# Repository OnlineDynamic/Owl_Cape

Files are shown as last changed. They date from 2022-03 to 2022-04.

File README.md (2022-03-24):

# Owl_Cape
Raspberry Pi (SMI Driven) FPP WS2811 based ch16 Pixel Controller Cape

Building on the great work of the Falcon FPP project, numerous open hardware pixel controllers and the clever brain behind this blog: https://iosoft.blog/2020/09/29/raspberry-pi-multi-channel-ws2812/

This project is looking to create a simple low cost 16ch Raspberry PI Cape to run on FPP using SMI interface of a 'Raspberry Pi Zero 2 W' (and potentially then expand out to supporting other Pi's with the 40PIN Header).  The aspiration is for the final code for the cape to be included in the FPP project and the xLights project to make a low cost easy to use pixel controller for LED pixel light shows which will benefit as the FPP project evolves its functionality.

## Basic Spec of Cape

- 12V DC in only (fused at xx Amps)
- PI Mounts on PCB
- 40 Pin Header for attaching to RPI via a ribbon cable (allow easy removal of PI)
- Power the RPI via Header pins
- 16 Ch of LED (WS2811) outputs individually fused at 5A running at 12V DC with SMD LED power indicators
- EEPROM onboard to identify CAPE to PI

## Potential Future expansion
- On board RJ45 Jack to connect wired ethernet to PI using USB test pads on PI
- Jumper to make LED voltage either 12V or 5V DC
- Basic LED Screen showing status

## Out of scope
- Any differential outputs

## Special Thanks to:
https://github.com/Kosh42/PCB-Designs/tree/main/Mirage for the inspiration

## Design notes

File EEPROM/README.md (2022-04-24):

# HOWTO: Raspi HAT EEPROM and device-tree setup

Customised from https://forums.raspberrypi.com/viewtopic.php?t=108134

## Intro

As it is hard to find good quality information EEPROM for HATs, and after some struggling I have found the post above but it too had issues and seemed out of date, so I decided to write this file to create a set of instructions for myself to use with the 'Owl Cape' project but have tried to leave in lots of description to help others more generically. 

In this project I'm using a Amtel AT24C256 (32,768 x 8 bits (256k bits or 32kB)) (https://ww1.microchip.com/downloads/en/DeviceDoc/doc0670.pdf) to meet FPP[^5]. spec but typically the standard Pi hat spec talks about using its smaller brother the AT24C32 (4,096 x 8)

This process should work for:
- 24c32
- 24c64
- 24c128
- 24c256
- 24c512
- 24c1024

(with the correct adjustments in file size generation and type command passed to eepflash)

## Initial Setup

First off, let’s talk about the hardware. I used an AT24C256 DIP i2c EEPROM. 

The pins need to be wired like this:

| AT24C256 Pin |	Raspberry Pi Pin 	  | Notes |
|---|---|---|
|1 (AO) 	 |GND (pins 6, 9, 14, 20, 25, 30, 34, 39)| 	All address pins tied to ground will place the EEPROM at address 50. This is the required address in the specification|
|2 (A1) |GND | | 	
|3 NC |Not Connected|| 	
|4 GND 	|GND 	||
|5 SDA | 	27 You should also add a 3.9K pullup resistor from EEPROM pin 5 to 3.3V | You must use this pin for the Raspberry Pi to detect the EEPROM on startup |
|6 SCL | 	28 You should also add a 3.9K pullup resistor from EEPROM pin 6 to 3.3V | You must use this pin for the Raspberry Pi to detect the EEPROM on startup |
|7 WP 	|Not connected 	| Write protect. The write protect input, when connected to GND, allows normal write operations. When WP is connected high to V CC , all write operations to the memory are inhib-ited. If the pin is left floating, the WP pin will be internally pulled down to GND.|
|8 VCC 	| 3.3V (pins 1 or 17) |	The EEPROM is capable of being run at 5 volts, but must be run at 3.3 volts to work as a HAT identification EEPROM.|

The specification requires that the data pin be on pin 27, the clock pin be on pin 28, and that the EEPROM be at address 50 on the i2c bus as described in the table above. There is also some mention of pullup resistors in both the data sheet and the HAT specification, but not in a lot of detail. The best I could find was a circuit diagram for a different EEPROM with the pullup resistors shown.

## Setup Raspberry PI

As a preliminary step, you need to activate videocore I2C. This is done by adding a line at the beginning of your /boot/config.txt file :

Add:

Code: 
```
dtparam=i2c_vc=on
```

Then reboot.

First of all, you need to get EEPROM utils (to make EEPROM content and flash it) and device-tree compiler (dtc).
For the device tree, the original author followed advice from Adafruit : https://learn.adafruit.com/introduction-to-the-beaglebone-black-device-tree/compiling-an-overlay

Code: 
```bash
git clone https://github.com/raspberrypi/hats.git
wget -c https://raw.githubusercontent.com/RobertCNelson/tools/master/pkgs/dtc.sh
chmod +x dtc.sh
./dtc.sh
```

You'll have now installed dtc compiler and have a hats directory. Go inside, and open eepromutils directory.

Code:
```bash
cd hats/eepromutils
```

Then need to run the make command to get the eepmake programme work:

Code:
```bash
make && sudo make install
```

Install I2C tools (used for detecting EEPROM)

Code:
```bash
sudo apt install i2c-tools
```

## Create Custom EEPROM Content

First of all, you need to modify eeprom_settings.txt to create your own version of HAT board. You don't have to modify UUID, as it will be auto-generated.

Template Code: (Owl_Cape version in git folder) 

```
########################################################################
# EEPROM settings text file
#
# Edit this file for your particular board and run through eepmake tool,
# then use eepflash tool to write to attached HAT ID EEPROM 
#
# Tools available:
#  eepmake   Parses EEPROM text file and creates binary .eep file
#  eepdump   Dumps a binary .eep file as human readable text (for debug)
#  eepflash  Write or read .eep binary image to/from HAT EEPROM
#
########################################################################

########################################################################
# Vendor info

# 128 bit UUID. If left at zero eepmake tool will auto-generate
# RFC 4122 compliant UUID
product_uuid 00000000-0000-0000-0000-000000000000

# 16 bit product id
product_id 0x0001

# 16 bit product version
product_ver 0x0002

# ASCII vendor string  (max 255 characters)
vendor "Martinlbb"

# ASCII product string (max 255 characters)
product "Brilliant board"

########################################################################
# GPIO bank settings, set to nonzero to change from the default.
# NOTE these setting can only be set per BANK, uncommenting any of
# these will force the bank to use the custom setting.

# drive strength, 0=default, 1-8=2,4,6,8,10,12,14,16mA, 9-15=reserved
gpio_drive 0

# 0=default, 1=slew rate limiting, 2=no slew limiting, 3=reserved
gpio_slew 0

# 0=default, 1=hysteresis disabled, 2=hysteresis enabled, 3=reserved
gpio_hysteresis 0

# If board back-powers Pi via 5V GPIO header pins:
# 0 = board does not back-power
# 1 = board back-powers and can supply the Pi with a minimum of 1.3A
# 2 = board back-powers and can supply the Pi with a minimum of 2A
# 3 = reserved
# If back_power=2 then USB high current mode will be automatically 
# enabled on the Pi
back_power 0

########################################################################
# GPIO pins, uncomment for GPIOs used on board
# Options for FUNCTION: INPUT, OUTPUT, ALT0-ALT5
# Options for PULL: DEFAULT, UP, DOWN, NONE
# NB GPIO0 and GPIO1 are reserved for ID EEPROM so cannot be set

#         GPIO  FUNCTION  PULL
#         ----  --------  ----
#setgpio  2     INPUT     DEFAULT
#setgpio  3     INPUT     DEFAULT
#setgpio  4     INPUT     DEFAULT
#setgpio  5     INPUT     DEFAULT
#setgpio  6     INPUT     DEFAULT
#setgpio  7     INPUT     DEFAULT
#setgpio  8     INPUT     DEFAULT
#setgpio  9     INPUT     DEFAULT
#setgpio  10    INPUT     DEFAULT
#setgpio  11    INPUT     DEFAULT
#setgpio  12    INPUT     DEFAULT
#setgpio  13    INPUT     DEFAULT
#setgpio  14    INPUT     DEFAULT
#setgpio  15    INPUT     DEFAULT
#setgpio  16    INPUT     DEFAULT
#setgpio  17    INTPUT     DEFAULT
setgpio  18    OUTPUT     DEFAULT
#setgpio  19    INPUT     DEFAULT
#setgpio  20    INPUT     DEFAULT
#setgpio  21    INPUT     DEFAULT
#setgpio  22    INPUT     DEFAULT
#setgpio  23    INPUT     DEFAULT
#setgpio  24    INPUT     DEFAULT
#setgpio  25    INPUT     DEFAULT
#setgpio  26    INPUT     DEFAULT
#setgpio  27    INPUT     DEFAULT
```

Then, you can create an eep file, based on you eeprom_settings.txt file. Basically, an eep file is a binary version of this file, which is ready to flash on EEPROM.

Code:
```bash
./eepmake eeprom_settings.txt myhat.eep
```
You have now a working HAT file!

## Writting file to EEPROM

You can now write it on EEPROM. If you have followed my design, you have a 24c256 memory (32k) if you have pi standard hat spec you have 24c32 memory (4k). But your myhat.eep file is smaller. As you don't know the state of your EEPROM, you may have conflict, as your myhat.eep could be misread. To avoid that, we shall start by cleaning EEPROM.

Use this dd command to generate a 32k file, padded with zero (an excellent choice, zeros are my favorites!). If you have another EEPROM size, just change count value according to your real EEPROM size.

Code: 

```bash
dd if=/dev/zero ibs=1k count=32 of=blank.eep
```

To be sure, you can review this binary, using hexdump :

Code:
```bash
hexdump blank.eep
```

## Make sure you can talk to the EEPROM

    In the HAT specification, the HAT EEPROM is connected to pins that can be driven by I2C0. However, this is the same interface as used by the camera and displays, so use of it by the ARMs is discouraged. The eepflash.sh script gets around this problem by instantiating a software driven I2C interface using those pins as GPIOs, calling it i2c-9:

Code:
```bash
   sudo dtoverlay i2c-gpio i2c_gpio_sda=0 i2c_gpio_scl=1 bus=9
```

Install i2cdetect Code:
```bash
   sudo apt install i2c-tools
```
    
Check with i2cdetect -y 9 (should be at address 0x50)

Code:
```bash
   i2cdetect -y 9 0x50 0x50
```

   Result:
   ```
       0  1  2  3  4  5  6  7  8  9  a  b  c  d  e  f
   00: 
   10:
   20:
   30:
   40:
   50: 50
   60: 
   70:
```

Next, you can now upload it to your EEPROM :

Code:
```bash
sudo ./eepflash.sh -w -d=9 -f=blank.eep -t=24c256
```

Answer yes, and before hitting enter, do a ground connection to test point (see design guide recommendation), who remove read-only flag. Then, press enter and wait without moving this ground connection!

To verify if everything went well, you can use this command to check EEPROM content. Caution: it will only work after you use the eepflash command, which does some modprobes.

Code: 
```bash
sudo hexdump /sys/class/i2c-adapter/i2c-9/0-0050/eeprom
```

If everything is okay, you'll only see zeros.

Then, you can upload your own myhat.eep.

Code:
```bash
sudo ./eepflash -w -d=9 -f=myhat.eep -t=24c256
```

And again, verify it after uploading :

Code:
```bash
sudo hexdump /sys/class/i2c-adapter/i2c-9/0-0050/eeprom
```

If the contents match, you can reboot your Raspberry Pi.

## Checking it worked and PI recognises HAT

To check if your HAT is recognized, just go to /proc/device-tree/. If you see a hat directory, you are a winner:)

Code:
```bash
cd /proc/device-tree/hat/
more vendor
more product
```

## Setting up Auto Configuration

The next step is to allow autoconfiguration of this HAT, following device-tree usage. In our example, we have a led connected to GPIO 18 (pin 12). I suggest you to test it before, using /sys/class/gpio :

Code:
```bash
sudo sh -c 'echo "18" > /sys/class/gpio/export'
sudo sh -c 'echo "out" > /sys/class/gpio/gpio18/direction'
sudo sh -c 'echo "1" > /sys/class/gpio/gpio18/value'
```

Your led is powered on. And to power off :

Code:
```bash
sudo sh -c 'echo "0" > /sys/class/gpio/gpio18/value'
```

Don't forget to get back to your hat/eepromutils directory after !

Now we can dive in the device-tree world. Open a file, called myled.dts, and paste this code (heavily copied from fividi post viewtopic.php?f=29&t=97875):

Code:
```
/dts-v1/;
/plugin/;

/ {
    compatible = "brcm,bcm2708";

    fragment@0 {
        target = <&leds>;
        __overlay__ {
            my_led: myled {
                label = "MYLED";
                gpios = <&gpio 18 0>;
                linux,default-trigger = "heartbeat";
            };
        };
    };
};
```
Compile it with dtc compiler :

Code:
```bash
sudo dtc -@ -I dts -O dtb -o myled.dtb myled.dts ; sudo chown pi:pi myled.dtb
```
For testing purposes, you can load this dtb as an overlay, using dtoverlay= in /boot/config.txt. This is not the purpose of this post, I let you search it on this forum.

Now, we can generate a eep file containing both board definition (eeprom_config.txt) and device-tree (for kernel auto configuration).

Code: 
```bash
./eepmake eeprom_settings.txt myhat-with-dt.eep myled.dtb
```

Then, blank the eeprom and upload it (don't forget to ground the test point to disabled read-only mode):

Code:
```bash
sudo ./eepflash.sh -w -f=blank.eep -t=24c256
sudo ./eepflash.sh -w -f=myhat-with-dt.eep -t=24c256
```

And finally, consistency checking by viewing both original file and eeprom dump :

Code:
```bash
hexdump myhat-with-dt.eep
sudo hexdump /sys/class/i2c-adapter/i2c-9/0-0050/eeprom
```
Finally, do a reboot, and enjoy your LED, blinking like a heartbeat!

Final reminder: When you start playing with adding long device tree, keep in mind you have a limited memory (4096 bytes for a 24c32 memory). When creating an eep file with eepmake, this tool will give you final size of your eep. Just verifiy if you have exceed your EEPROM size.

Note: With an incorrect DT, even your eeprom_settings are not recognized by kernel. And a bootable device-tree overlay is sometimes not sufficient for "eeprom boot"

To allow auto configuration after kernel boot (ie: modprobe some modules, TFT calibration, etc...), I use a custom parameter file, based on JSON, that could be parsed after. I choose JSON as it is small, human-readable, and easy to parse.
To add a custom file to your eep, just do this:

Code:
```bash
./eepmake eeprom_settings.txt myhat-with-dt.eep myled.dtb -c myparams.json
```

## Footnotes of reference sites used

[^1]: Official Guide https://github.com/raspberrypi/hats/tree/master/eepromutils.
[^2]: Helpful blog https://www.madebymikal.com/raspberry-pi-hat-identity-eeproms-a-simple-guide/.
[^3]: AT24C256 Spec https://datasheetspdf.com/pdf-file/160492/ATMELCorporation/AT24C256/1.
[^4]: Raspberry Pi Pinout https://pinout.xyz/pinout/sdio#.
[^5]: FPP (Falcon Pi Player) https://github.com/FalconChristmas/fpp.

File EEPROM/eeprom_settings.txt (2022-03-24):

########################################################################
# EEPROM settings text file
#
# Edit this file for your particular board and run through eepmake tool,
# then use eepflash tool to write to attached HAT ID EEPROM 
#
# Tools available:
#  eepmake   Parses EEPROM text file and creates binary .eep file
#  eepdump   Dumps a binary .eep file as human readable text (for debug)
#  eepflash  Write or read .eep binary image to/from HAT EEPROM
#
########################################################################

########################################################################
# Vendor info

# 128 bit UUID. If left at zero eepmake tool will auto-generate
# RFC 4122 compliant UUID
product_uuid 00000000-0000-0000-0000-000000000000

# 16 bit product id
product_id 0x0001

# 16 bit product version
product_ver 0x0002

# ASCII vendor string  (max 255 characters)
vendor "OnlineDynamic"

# ASCII product string (max 255 characters)
product "Owl Cape"

########################################################################
# GPIO bank settings, set to nonzero to change from the default.
# NOTE these setting can only be set per BANK, uncommenting any of
# these will force the bank to use the custom setting.

# drive strength, 0=default, 1-8=2,4,6,8,10,12,14,16mA, 9-15=reserved
gpio_drive 0

# 0=default, 1=slew rate limiting, 2=no slew limiting, 3=reserved
gpio_slew 0

# 0=default, 1=hysteresis disabled, 2=hysteresis enabled, 3=reserved
gpio_hysteresis 0

# If board back-powers Pi via 5V GPIO header pins:
# 0 = board does not back-power
# 1 = board back-powers and can supply the Pi with a minimum of 1.3A
# 2 = board back-powers and can supply the Pi with a minimum of 2A
# 3 = reserved
# If back_power=2 then USB high current mode will be automatically 
# enabled on the Pi
back_power 2

########################################################################
# GPIO pins, uncomment for GPIOs used on board
# Options for FUNCTION: INPUT, OUTPUT, ALT0-ALT5
# Options for PULL: DEFAULT, UP, DOWN, NONE
# NB GPIO0 and GPIO1 are reserved for ID EEPROM so cannot be set

#         GPIO  FUNCTION  PULL
#         ----  --------  ----
#setgpio  2     INPUT     DEFAULT
#setgpio  3     INPUT     DEFAULT
#setgpio  4     INPUT     DEFAULT
#setgpio  5     INPUT     DEFAULT
#setgpio  6     INPUT     DEFAULT
#setgpio  7     INPUT     DEFAULT
setgpio  8     ALT1    DOWN
setgpio  9     ALT1    DOWN
setgpio  10    ALT1    DOWN
setgpio  11    ALT1    DOWN
setgpio  12    ALT1    DOWN
setgpio  13    ALT1    DOWN
setgpio  14    ALT1    DOWN
setgpio  15    ALT1    DOWN
setgpio  16    ALT1    DOWN
setgpio  17    ALT1    DOWN
setgpio  18    ALT1    DOWN
setgpio  19    ALT1    DOWN
setgpio  20    ALT1    DOWN
setgpio  21    ALT1    DOWN
setgpio  22    ALT1    DOWN
setgpio  23    ALT1    DOWN
#setgpio  24    INPUT     DEFAULT
#setgpio  25    INPUT     DEFAULT
#setgpio  26    INPUT     DEFAULT
#setgpio  27    INPUT     DEFAULT

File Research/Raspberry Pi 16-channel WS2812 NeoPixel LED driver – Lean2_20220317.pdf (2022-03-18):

## Lean2 (https://iosoft.blog/)

Embedded systems without the bloat

# Raspberry Pi 16-channel WS2812 NeoPixel LED driver

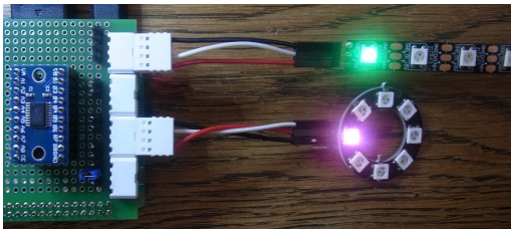
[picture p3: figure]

Raspberry Pi driving smart LEDs

WS2812B LEDs (‘NeoPixels’) are intelligent devices, that can be programmed to a specic 24-bit red, green & blue (RGB) colour, by a pulse train on a single wire. They are capable of being daisy-chained, so a single pulse line can drive a large number of devices.

The programming pulses have to be accurately timed to within fractions of a microsecond, so conventional Raspberry Pi techniques are of limited use; they can only handle a small number of pulse channels, driving a maximum of 1 or 2 strings of LEDs, which is insucient for a complex display.

This blog post describes a new technique that uses the RPi Secondary Memory Interface (SMI) to drive 8 or 16 channels with very accurate timing. No additional hardware is needed, apart from a 3.3 to 5V level-shifter, that is required for all NeoPixel interfaces.

### Pulse shape

To set one device, it is necessary to send 24 pulses with specic widths into its input; they represent green bits G7 to G0, red bits R7 to R0, and blue bits B7 to B0, in that order. If you send more than 24 bits, the extra will emerge from the data output pin, which can drive the data input of the next device in the chain, so to drive ‘n’ LEDs, it is necessary to send n * 24 pulses, without any sizeable gaps in the transmission. If the data line is held low for the ‘reset’ time (or longer), the next transmission will restart at the rst LED. Here is a waveform for 2 LEDs in a chain, the rst being set to red (RGB 240,0,0) the second to green (RGB 0,240,0).

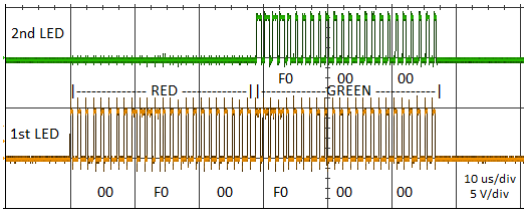
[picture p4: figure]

LED pulse sequence

It is just about possible to see the 0 and 1 pulses on the oscilloscope trace above, here is a zoomed-in section of that trace, to show the varying pulse width more clearly.

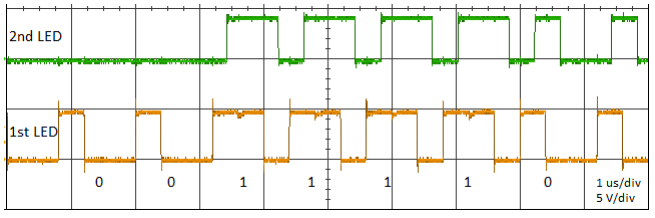
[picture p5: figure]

LED pulses

You can see that the pulses for the second LED are oset by about 200 nanoseconds from those of the rst LED; this is because the rst LED is regenerating the signal, rather than just copying the input to output.

The precise denition of a 0/1/reset pulse depends which version of the LED you are using, but the commonly-accepted values in microseconds (us) are:

To simplify the code, we can tweak the values slightly, whilst still remaining in the tolerance band, so my code generates a ‘0’ pulse as 0.4 us high, 0.8 us low, and a ‘1’ pulse as 0.8 us high, 0.4 us low.

### Generating the pulses

Since the pulses have to be quite accurately timed, and the Raspberry Pi has no specic hardware for pulse generation, the pulse width modulation (PWM) or audio interfaces are generally used, but this imposes a signicant limitation on the number of LED channels that can be supported. I’m using the Secondary Memory Interface (SMI) instead, which could provide up to 18 channels, though my software only supports 8 or 16.

If you are interested in learning more about SMI, I have written a detailed post here, (https://iosoft.blog/raspberry-pi-smi/) but the key points are:

1. The SMI hardware is included as standard in all Raspberry Pi versions, but is little-used due to the lack of publicly-available documentation.
2. As the name implies, it is intended to support fast transfers to & from external memory, so it can eciently transfer blocks of 8- or 16-bit data.
3. The timing of the transfers can be controlled to within a few nanoseconds, making it ideal for generating accurate pulses.
4. When driven by Direct Memory Access (DMA), the SMI output will proceed without any CPU intervention, so the timing will still be accurate even when using the slowest of CPUs (e.g. Pi Zero or 1).
5. SMI output uses specic pins on the I/O header: SD0 to SD17 as shown below.
0: | 0.4 us high, 0.85 us low, tolerance +/- 0.15 us
1: | 0.8 us high, 0.45 us low, tolerance +/- 0.15 us
RST: at least 50 us (older devices) or 300 us (newer devices)

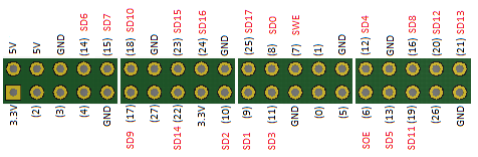
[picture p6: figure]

SMI pins on I/O header

My code supports both 8 and 16-bit SMI output, which equates to 8 or 16 output channels, where each channel can have an arbitrarily long string of LEDs.

Each LED can be individually programmed to any RGB value, the only limitation is that all channels will transmit the same number of RGB values. This is not a problem, since any extra settings have no eect; if 2 LEDs receive 5 RGB values, they will accept the rst 2 values, and ignore the rest.

When rst generating a pulse train, it is worth checking that the output is as expected, so I rst sent the following byte values to the 8-bit SMI interface, using DMA:

This should result in a classic stepped binary output, but instead the lowest 3 data bits were as follows:

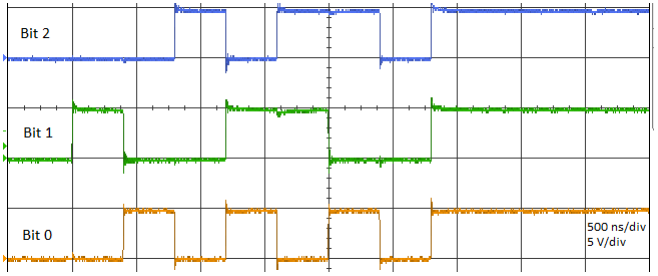
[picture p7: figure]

Binary test waveform: 8-bit SMI

The voltage level and pulse width are correct, but the bytes in each 8-bit word are swapped. This can be corrected by a simple function, using a GCC builtin

// Data for simple transmission test
uint8_t tx_test_data[] = {1, 2, 3, 4, 5, 6, 7, 0};

byte-swap call:

The resulting waveform is correct:

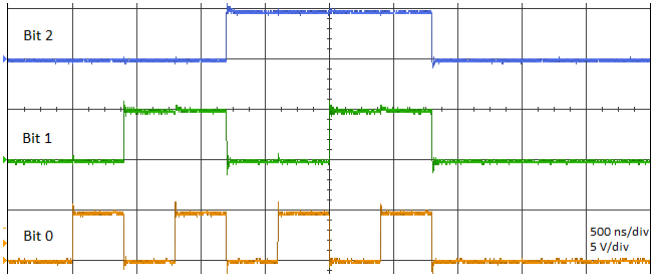
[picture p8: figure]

Corrected test waveform

This byte-swapping isn’t necessary if running a 16-bit interface; the rst byte has the least-signicant data bits, in the usual little-endian format.

### Hardware

The data outputs are SD0 – SD7 for 8 channels, or SD0 – SD15 for 16 channels:

// Swap adjacent bytes in transmit data void swap_bytes(void *data, int len) {
uint16_t *wp = (uint16_t *)data;

len = (len + 1) / 2;
while (len-- > 0)
{
*wp = __builtin_bswap16(*wp); wp++;
}
}

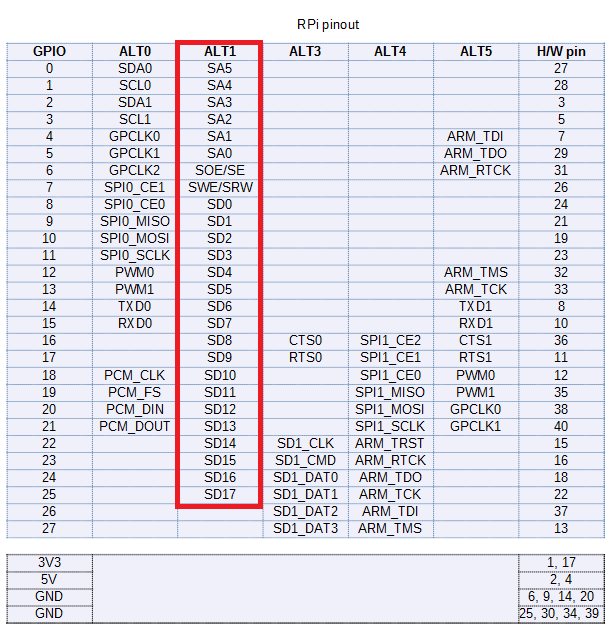
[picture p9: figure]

SMI I/O lines

If 8 channels are sucient, it is worthwhile setting the software to do this, since it halves the DMA bandwidth requirement, and reduces the possibility of a timing conict with the video drivers.

The LEDs need a 5 volt power supply, which can be quite sizeable if there is a large number of devices. A single device takes around 34 mA when at full RGB output, so the standard Pi supply can only be used for relatively small numbers of LEDs.

The channel output signals also need to be stepped up from 3.3V to 5V. There are various ways to do this, I used a TXB0108 bi-directional converter, which generally works OK, but the waveform isn’t correct driving some budget-price devices. In the following graphic, the bottom oscilloscope trace shows a good-quality square wave with 5V amplitude; the upper trace peaks around 5V, but then decays to nearly 3V, which is outside the LED specication.

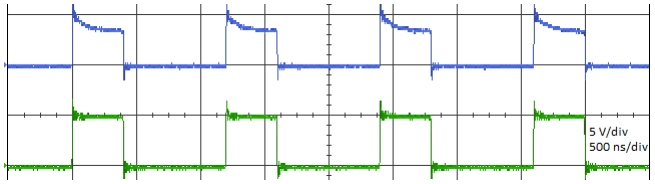
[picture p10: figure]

Correct (lower) and incorrect (upper) drive waveforms

The cheap devices seem to have higher input capacitance than other NeoPixels, and this triggers an issue with the TXB0108, which has an unusual automatic bi-directional ability. Every time an input changes, it emits a brief current pulse to drive the output, then keeps the output in that state using a weak drive. The TXB0108 data sheet warns against driving high-capacitance loads; to get a good-quality waveform, it’d be much better to use a conventional level-shifter such as the 74LVC245.

For quick testing, it is possible to drive a few LEDs from the RPi 3.3V supply rail, in which case the RPi output pin can be connected directly to the LED digital input, without level-shifting; this is outside the specication of the device, but generally works, providing the supply isn’t overloaded.

### Software

As the application has to drive the SMI interface and DMA controller, it is written in C, and must run with root privileges (using ‘sudo’). You can nd detailed information on SMI here, (https://iosoft.blog/raspberry-pi-smi/) and DMA here. (https://iosoft.blog/raspberry-pi-dma-programming/)

In contrast to my other DMA programs, driving WS2812 LEDs is relatively straightforward; it just requires a single block of data to be transmitted, and a single DMA descriptor to transmit it. There is no need for additional DMA pacing, as all the pulse timing is handled by SMI, to a really high accuracy (around 1 nanosecond, according to my measurements).

The only tricky part is the preparation of data for the transmit buer. Each LED needs to receive 24 bits of GRB (green, red, blue) data, and each bit has 3 pulses: the rst is ‘1’, the second is ‘0’ or ‘1’ according to the data, and the third is ‘0’. Each pulse is a single SMI write cycle. The data for all channels is sent out simultaneously, so if we are driving 8 channels, the byte sequence will be:

The encoder function takes a 1-dimensional array of RGB values (1 RGB value per channel), converts them to GRB, and writes the corresponding sequence to the transmit buer. To handle 8 or 16 channels, the buer data type is switched between 8 and 16 bits.

Ch7 Ch6 Ch5 Ch4 Ch3 Ch2 Ch1 Ch0
1 | 1 | 1 | 1 | 1 | 1 | 1 | 1
Grn bit 7: x | x | x | x | x | x | x | x
0 | 0 | 0 | 0 | 0 | 0 | 0 | 0
1 | 1 | 1 | 1 | 1 | 1 | 1 | 1
Grn bit 6: x | x | x | x | x | x | x | x
0 | 0 | 0 | 0 | 0 | 0 | 0 | 0
..and so on until..
1 | 1 | 1 | 1 | 1 | 1 | 1 | 1
Grn bit 0: x | x | x | x | x | x | x | x
0 | 0 | 0 | 0 | 0 | 0 | 0 | 0
1 | 1 | 1 | 1 | 1 | 1 | 1 | 1
Red bit 7: x | x | x | x | x | x | x | x
0 | 0 | 0 | 0 | 0 | 0 | 0 | 0
..and so on until..
1 | 1 | 1 | 1 | 1 | 1 | 1 | 1
Blu bit 0: x | x | x | x | x | x | x | x
0 | 0 | 0 | 0 | 0 | 0 | 0 | 0
#define LED_NCHANS | 16 // Number of LED string channels (8 or 16)

#define BIT_NPULSES | 3 | // Number of O/P pulses per LED bit

#if LED_NCHANS > 8

#define TXDATA_T | uint16_t

#else

#define TXDATA_T | uint8_t

#endif

// Set transmit data for 8 LEDs (1 per chan), given 8 RGB vals
// Logic 1 is 0.8us high, 0.4 us low, logic 0 is 0.4us high, 0.8us low void rgb_txdata(int *rgbs, TXDATA_T *txd)
{
int i, n, msk;

// For each bit of the 24-bit RGB values..
for (n=0; n<LED_NBITS; n++)
{
// Mask to convert RGB to GRB, M.S bit first
msk = n==0 ? 0x8000 : n==8 ? 0x800000 : n==16 ? 0x80 : msk>>1; // 1st byte is a high pulse on all lines

### Beware caching

If you are modifying the software, there is a major trap, that I fell into shortly before releasing the code.

Everything was working ne on RPi v3 hardware, then I switched to a Pi Zero, and it was a disaster; the pulse sequences were all over the place, bearing no resemblance to what they should be.

I then tried outputting a simple 8-bit binary sequence, and that was wrong as well; the code steps were:

Looking at the output on an oscilloscope, the byte-swap function wasn’t working; no matter how I modied the code, it was doing nothing. I then realised there is a golden rule of DMA programming: if your code is behaving illogically, it is probably due to caching.

The transmit buer has been allocated in uncached video memory, as the DMA controller doesn’t have access to the CPU cache – for more details, see my post on DMA. (https://iosoft.blog/raspberry-pi-dma-programming/) Since the transmit buer pointer was dened as non-cached and volatile, the data was copied to it immediately, but then the subsequent byte-swapping will have taken place the CPU’s on-chip cache. Eventually this cache would be written back to the physical memory, but in the short term, there is a mismatch between the two – and the DMA controller will use the copy in txd[0] = (TXDATA_T)0xffff;
// 2nd byte has high or low bits from data // 3rd byte is low pulse
txd[1] = txd[2] = 0;
for (i=0; i<LED_NCHANS; i++)
{
if (rgbs[i] & msk)
txd[1] |= (1 << i);
}
txd += BIT_NPULSES;
}
}

Copy data into transmit buffer Byte-swap the buffer data
Transmit the buffer data physical memory. So the cure is simple; just do the byte-swapping before the data is written to the transmit buer.

Switching back to the real pulse-generating code, again this was all being done in the transmit buer:

Now, in addition to the byte-swap issue, we also have a caching problem in the data preparation, as it involves lots of bit-twiddling; even if we could persuade the compiler to ignore the cache, the code would run quite slowly due to the absence of caching. The best solution is to prepare all the data in local (cached) memory, then nally copy it across to the uncached memory for transmission:

### Source code

The main source le is rpi_pixleds.c, it uses functions from rpi_dma_utils.c and .h, and SMI denitions from rpi_smi_defs.h, available on Github here. (https://github.com/jbentham/rpi)

It is essential to modify the PHYS_REG_BASE setting in rpi_smi_defs.h to reect the RPi hardware version:

The application is compiled and run using:

The options can be in upper or lower case:

Prepare data in transmit buffer Byte-swap the buffer data
Transmit the buffer data

Prepare data in local buffer Byte-swap the local data
Copy local data to transmit buffer Output the transmit buffer data

// Location of peripheral registers in physical memory #define PHYS_REG_BASE PI_23_REG_BASE
#define PI_01_REG_BASE 0x20000000 // Pi Zero or 1 #define PI_23_REG_BASE 0x3F000000 // Pi 2 or 3 #define PI_4_REG_BASE 0xFE000000 // Pi 4

gcc -Wall -o rpi_pixleds rpi_pixleds.c rpi_dma_utils.c

sudo ./rpi_pixleds [options] [RGB_values]

Test mode generates a chaser-light pattern for the given number of LEDs, on 8 or 16 channels as specied at compile-time, e.g. for 5 LEDs per channel:

It is also possible to set the RGB value of an individual LED using 6-character hexadecimals, so full red is FF0000, full green 00FF00, and full blue 0000FF. The RGB values for each LED in a channel are delimited by commas, and the channels are delimited by whitespace, e.g.

You will note that it isn’t necessary to specify the number of LEDs per channel when RGB data is given; the code counts the number of RGB values for each channel, and uses the highest number for all the channels.

### Compile-time options

The following denitions are at the top of the main source le:

The main items that might be changed are:

- TX_TEST, set non-zero to output a simple binary sequence on data bits 0-2,
-n num | # Set number of LEDs per channel
-t | # Set test mode

sudo ./rpi_pixleds -n 5 -t

# All 8 or 16 channels, 5 LEDs per channel, all off

sudo ./rpi_pixleds -n 5
# All 8 or 16 channels, 3 LEDs per channel, all off apart from Ch2 LED0 | red

sudo ./rpi_pixleds -n 3 0 0 ff0000

# 3 active channels, 1 LED per channel, set to half-intensity red, green, blue sudo ./rpi_pixleds 7f0000 007f00 00007F

# 3 active channels, 2 LEDs per channel, set to full & light red, green, blue sudo ./rpi_pixleds ff0000,ff2020 00ff00,20ff20 0000ff,2020ff

#define TX_TEST | 0 | // If non-zero, use dummy Tx data

#define LED_D0_PIN | 8 | // GPIO pin for D0 output

#define LED_NCHANS | 8 | // Number of LED channels (8 or 16)

#define LED_NBITS | 24 // Number of data bits per LED

#define LED_PREBITS | 4 | // Number of zero bits before LED data

#define LED_POSTBITS | 4 | // Number of zero bits after LED data

#define BIT_NPULSES | 3 | // Number of O/P pulses per LED bit

#define CHAN_MAXLEDS | 50 // Maximum number of LEDs per channel

#define CHASE_MSEC | 100 // Delay time for chaser light test

for checking that SMI works as intended.
- LED_NCHANS, to specify either 8 or 16 channels; set to 8 if this number is sucient.
- CHAN_MAXLEDS, to increase the maximum number of LEDs allowed per channel. This is only used for dimensioning the data arrays; the actual number of LEDs per channel is specied at run-time.
- CHASE_MSEC, to increase or decrease the delay time for test mode

### Possible problems

If the program doesn’t work, here are some issues to check:

- PHYS_REG_BASE: make sure you have set this correctly for the RPi version you are using.
- Power overload: check that there is an adequate reserve of power, assuming around 34 mA per LED.
- Incorrect voltage: ensure that the data lines are being driven to the full supply voltage, usually 5 volts.
- Stuck pixels: if you specify too few RGB values for a given channel, then the remaining LEDs will be unchanged, and may appear to be ‘stuck’. If in doubt, use the -n option to set the actual number of LEDs per channel, to ensure all the LEDs receive some data.
- Caching problems: if you have modied the pulse-generating code, and it is behaving illogically, then you probably have a caching issue. See the detailed description (https://iosoft.blog/2020/09/29/raspberry-pi-multi-channel-ws2812/#beware-caching) above.
- RPi v4: test mode may only set 1 row of LEDs, then stop. The reason for this is not understood, but it can be cured by running headless as described below.

There can be an intermittent problem with brief ickering of LEDs to other colours when running a fast-changing test such as the chaser-lights, or maybe occasional colour errors on a slowly-changing display, if running in 16-channel mode. This is due to the HDMI display drivers taking priority over the SMI memory accesses, causing jitter in the pulse timing. I suspect it can be cured by changing the priorities, but due to time pressure, I’ve been taking the

## 25 thoughts on “Raspberry Pi 16-channel WS2812 NeoPixel LED driver”

easy way out, and disabling HDMI output using:

Sadly restoring the output (using ‘/usr/bin/tvservice -p’) doesn’t restore the desktop image, so the Rpi is run ‘headless’, controlled using ssh. More work is needed to nd an easier solution.

Safety warning: take care when creating a rapidly-changing display, as some people can be adversely aected by ashing lights; research ‘photosensitive epilepsy’ for more information.

Copyright (c) Jeremy P Bentham 2020. Please credit this blog if you use the information or software in it.

September 29, 2020 (https://iosoft.blog/2020/09/29/raspberry-pi-multi-channel-ws2812/) Bare metal, (https://iosoft.blog/category/bare-metal/) NeoPixel, (https://iosoft.blog/category/neopixel/) Raspberry Pi, (https://iosoft.blog/category/raspberry-pi/) Smart LED (https://iosoft.blog/category/smart-led/)

/usr/bin/tvservice -o

/

Like (https://iosoft.blog/2020/09/29/raspberry-pi-multi-channel-ws2812/?like_comment=2027&_wpnonce=099cc7a34a)

Like (https://iosoft.blog/2020/09/29/raspberry-pi-multi-channel-ws2812/?like_comment=2028&_wpnonce=badc4067d4)

Pete

October 13, 2020 at 5:39 pm (https://iosoft.blog/2020/09/29/raspberry-pi-multi-channel-ws2812/#comment-2027)

Fantastic work, Jeremy! I’m working on getting this technique into some of the existing RPi libraries and tools for driving RBG LEDs. They currently already use the the PWM or PCM peripheral fed by DMA, so it shouldn’t be too much eort.
If I understand correctly, could one use SMI_TIMING of (4, 26, 52, 26) for the RPi 0-3, or (6, 26, 52, 26) for the RPi 4, to extend the cycle time from 400ns to 416ns, thereby bringing the overall output speed closer to 800kHz? That assumes it doesn’t extend the 0-bit to the point that it becomes a 1-bit.

iosoftcode (https://iosoftblog.wordpress.com/)

October 13, 2020 at 6:56 pm (https://iosoft.blog/2020/09/29/raspberry-pi-multi-channel-ws2812/#comment-2028)

An easy-to-use library would be great, but personally I thought that approximating the individual pulse widths was more important than getting the frequency right, since the WS2182B data sheet species the acceptable pulse timings, not frequency. However, there is plenty of scope for interpreting the (minimal amount of) manufacturer’s data.

Pete

October 14, 2020 at 3:22 pm (https://iosoft.blog/2020/09/29/raspberry-pi-multi-channel-ws2812/#comment-2031)

That is true, at least for short LED chains and the IC you tested. My hope is this is stable for chains as long as 680 RGB LEDS. That’s four DMX universes, which is typical of a production-grade LED controller.
Also of potential interest with longer chains is the stability of the clock in the face of CPU throttling/overclocking. The RPi 4 is especially known for running hot and throttling the CPU if not actively cooled. Is there any info

Like (https://iosoft.blog/2020/09/29/raspberry-pi-multi-channel-ws2812/?like_comment=2031&_wpnonce=ade18cbb15)

Like (https://iosoft.blog/2020/09/29/raspberry-pi-multi-channel-ws2812/?like_comment=2032&_wpnonce=f9c700e0ef)

Like (https://iosoft.blog/2020/09/29/raspberry-pi-multi-channel-ws2812/?like_comment=2034&_wpnonce=1ca4ee924a)

out there to verify that the SMI clock stays xed even as the CPU is throttled?

iosoftcode (https://iosoftblog.wordpress.com/)

October 14, 2020 at 7:10 pm (https://iosoft.blog/2020/09/29/raspberry-pi-multi-channel-ws2812/#comment-2032)

I don’t have access to very long strings of LEDs, so I’ll leave it to others to perform that test; the key advantage of my approach is that the timings can be tweaked with 3 nanosecond resolution if required, though the values I’m using are well within the published tolerance bands, so really should be OK.

To the best of my knowledge, the CPU frequency throttling does not change the SMI frequency, since it is fed from a separate DPLL clock, however that does need to be checked as well. Personally I’d use a PI zero or 3 for this application, since they fared much better than the Pi 4 in my DMA tests – there is no need for much CPU power, since SMI and DMA are doing all the hard work.

Claude Schwarz (@Claude1079) (http://twitter.com/Claude1079)

October 16, 2020 at 8:09 am (https://iosoft.blog/2020/09/29/raspberry-pi-multi-channel-ws2812/#comment-2034)

This might explain the misbehaviour on RPI4 using the test program, I stumbeld over similar eects on the Pi4 using SMI : https://github.com/raspberrypi/linux/issues/3847

Christian

December 29, 2020 at 2:42 pm (https://iosoft.blog/2020/09/29/raspberry-pi-multi-channel-ws2812/#comment-2463)

Like (https://iosoft.blog/2020/09/29/raspberry-pi-multi-channel-ws2812/?like_comment=2463&_wpnonce=8ba6ad1bfa)

Like (https://iosoft.blog/2020/09/29/raspberry-pi-multi-channel-ws2812/?like_comment=2467&_wpnonce=b4fe470eca)

You did a really good Job! Unfortunalety only the 8 Channel Mode works properly for me. In 16 Channel Mode the driver only produces 12 Data Bits instead of 24 Data Bits per Channel if i set n=1 . The problem occurs on raspberry pi 4 (4GB). I set the correct REG_BASE and disabled the Display output as described above, but the problem still exists. I guess that some DMA have to be changed for 16 Channel Mode? I would be very greatful about a short reply. Thank you!

iosoftcode (https://iosoftblog.wordpress.com/)

December 30, 2020 at 10:16 am (https://iosoft.blog/2020/09/29/raspberry-pi-multi-channel-ws2812/#comment-2467)

Yes, there are some signicant problems with the Pi 4, that I need to revisit to try and understand what is going on – I don’t have any extra information at present.

Like (https://iosoft.blog/2020/09/29/raspberry-pi-multi-channel-ws2812/?like_comment=2668&_wpnonce=2d3048c98b)

Like (https://iosoft.blog/2020/09/29/raspberry-pi-multi-channel-ws2812/?like_comment=2673&_wpnonce=a359b4c874)

Eric-Jan

January 28, 2021 at 1:53 pm (https://iosoft.blog/2020/09/29/raspberry-pi-multi-channel-ws2812/#comment-2668)

Hi,

Thanks for this blog and your amazing example code! I’m quite a newbie when it comes to c / c++. I Managed to add libe131 and driving an 117×47 (5499 pixels) DIY led display with your code (Raspberry Pi 4, 8 Channel mode). With xLights used as sequencer (running about 20fps) But that’s more due xLights then it is a pi limitation. I created a player with libAV on the pi which does it niceley 30+ fps. I want to create my own sequencer on the pi to loose the xLights overhead. So i went to the 64bit version of raspios, i can get the code compiled but it segfaults after that. Is it possible to run the code on 64bit? if so, can you give me some hints how i can x it to get it running on 64bit? Thanks in advance!

iosoftcode (https://iosoftblog.wordpress.com/)

January 29, 2021 at 9:41 am (https://iosoft.blog/2020/09/29/raspberry-pi-multi-channel-ws2812/#comment-2673)

Sorry, I haven’t done any work on 64-bit. One day I’ll get around to it…

Eric-Jan

January 30, 2021 at 2:30 pm (https://iosoft.blog/2020/09/29/raspberry-pi-multi-channel-ws2812/#comment-2687)

Thanks! I’ll keep it with 32bit for now, maybe i can look into 64bit part when i have mastered c /c++ a littlebit more But your code works quite nice with 5499 leds. I read an question about a long string of leds, well, this probably answers it. 702 leds per channel what i’ve got now (Except the 8th channel that has 585, but that is because of the design of the board where the strips are mounted on was cut too small). But with mpeg player and hardware decoding of a 1920×1080 video i’m able to reach about 30+ fps.

Like (https://iosoft.blog/2020/09/29/raspberry-pi-multi-channel-ws2812/?like_comment=2687&_wpnonce=a9af1cfd5d)

Like (https://iosoft.blog/2020/09/29/raspberry-pi-multi-channel-ws2812/?like_comment=3020&_wpnonce=271a320643)

Like (https://iosoft.blog/2020/09/29/raspberry-pi-multi-channel-ws2812/?like_comment=3026&_wpnonce=1c41bad070)

Nick

March 20, 2021 at 4:19 pm (https://iosoft.blog/2020/09/29/raspberry-pi-multi-channel-ws2812/#comment-3020)

I was looking for a solution like this to control ws2812 led without using pwm pins. I would use only one strip on GPIO 4 (BCM). However for test I compiled your code only modifying “#dene PHYS_REG_BASE PI_23_REG_BASE” in “rpi_dma_utils.h” because I’ve a RPi 2B.

compiled and run… and freeze, reboot is needed. I’m missing something? Thanks

iosoftcode (https://iosoftblog.wordpress.com/)

March 21, 2021 at 10:59 am (https://iosoft.blog/2020/09/29/raspberry-pi-multi-channel-ws2812/#comment-3026)

Oh dear; I must admit I don’t have a Pi 2 to test the code, have only tested on the Zero, 3, 4, and 400. Maybe there is an error in the base address..?

Like (https://iosoft.blog/2020/09/29/raspberry-pi-multi-channel-ws2812/?like_comment=3274&_wpnonce=f6932eeddf)

Like (https://iosoft.blog/2020/09/29/raspberry-pi-multi-channel-ws2812/?like_comment=3275&_wpnonce=9cb1271dd3)

Like (https://iosoft.blog/2020/09/29/raspberry-pi-multi-channel-ws2812/?like_comment=3276&_wpnonce=9b2357ac0f)

Hex

May 17, 2021 at 11:26 am (https://iosoft.blog/2020/09/29/raspberry-pi-multi-channel-ws2812/#comment-3274)

Thanks for this great post and solution. I’m trying to implement your library for driving 16 channels of 600leds. I’m using RPi 3 B+ and want also to test RPi 4 later. Now I noticed something strange. When I switch to 16ch mode I get only the exact halve LED count driven by the software. So no i can drive 16 strips but only 300 LEDs long.
I’m trying to gure out what could be the problem. Do you have any ideas?

iosoftcode (https://iosoftblog.wordpress.com/)

May 17, 2021 at 1:56 pm (https://iosoft.blog/2020/09/29/raspberry-pi-multi-channel-ws2812/#comment-3275)

You’ve tried doubling CHAN_MAXLEDs?

Christian

May 17, 2021 at 2:07 pm (https://iosoft.blog/2020/09/29/raspberry-pi-multi-channel-ws2812/#comment-3276)

I’ve gured it out…
Line 374 in rpi_pixleds.c needs to be updated:
cbs[0].tfr_len = nsamp * sizeof(TXDATA_T);

Otherwise the transfer length of the dma Controller will not be updated in 16 Channel Mode and therefore only half of the Data is shifted Out…

iosoftcode (https://iosoftblog.wordpress.com/)

May 17, 2021 at 5:34 pm (https://iosoft.blog/2020/09/29/raspberry-pi-multi-channel-ws2812/#comment-3277)

Like (https://iosoft.blog/2020/09/29/raspberry-pi-multi-channel-ws2812/?like_comment=3277&_wpnonce=d03acfa68f)

Like (https://iosoft.blog/2020/09/29/raspberry-pi-multi-channel-ws2812/?like_comment=3845&_wpnonce=6b73986240)

Thanks very much for nding that bug – I’ll update the code.

Hermann Stamm-Wilbrandt (https://stamm-wilbrandt.de/en)

August 26, 2021 at 12:36 pm (https://iosoft.blog/2020/09/29/raspberry-pi-multi-channel-ws2812/#comment-3845)

Thanks for that interesting code!

I tried with Pi400 and only saw 1 led working. So I connected Pi0W in gadget mode to Pi400 and used Pi0W SD0 to control 16 WS2812B leds. Here also one led works:

pi@raspberrypi0W:~/rpi $ sudo ./rpi_pixleds -n 3 0000 0000 0000
VC mem handle 6, phys 0xde5fd000, virt 0xb6fad000
Setting 3 LEDs per channel, 8 channels
Closing
pi@raspberrypi0W:~/rpi $

Even after disabling HDMI:

pi@raspberrypi0W:~/rpi $ tvservice -o Powering o HDMI
pi@raspberrypi0W:~/rpi $

The only detail I did not according your instructions is using voltage converter from 3.3V to 5V for SD0. If that causes the issues with leds “2..”, then why can I change happily the colors for 1st led without voltage level adapter?

iosoftcode (https://iosoftblog.wordpress.com/)

August 26, 2021 at 2:09 pm (https://iosoft.blog/2020/09/29/raspberry-pi-multi-channel-ws2812/#comment-3846)

I’ve not used gadget mode, so just in case that is causing the problem (e.g. by

Like (https://iosoft.blog/2020/09/29/raspberry-pi-multi-channel-ws2812/?like_comment=3846&_wpnonce=944a542647)

Like (https://iosoft.blog/2020/09/29/raspberry-pi-multi-channel-ws2812/?like_comment=3945&_wpnonce=e7a92fe805)

Like (https://iosoft.blog/2020/09/29/raspberry-pi-multi-channel-ws2812/?like_comment=3948&_wpnonce=44311f26d5)

a DMA conict) it is worth disabling that and using a conventional network ssh connection. Also make sure there isn’t a hardware problem, e.g. an inadequate power supply.

computergeek1507

September 26, 2021 at 5:57 pm (https://iosoft.blog/2020/09/29/raspberry-pi-multi-channel-ws2812/#comment-3945)

I was going to try to use your code in the Falcon Player Project. We use the GPLv2 and you use the Apache License. My understanding is Apache is incompatible with GPLv2. Is it possible to relicense your code to be GPL compatible?

iosoftcode (https://iosoftblog.wordpress.com/)

September 27, 2021 at 7:01 pm (https://iosoft.blog/2020/09/29/raspberry-pi-multi-channel-ws2812/#comment-3948)

I have no problem with my code being used in the Falcon Player, but am unfamiliar with the mechanics of dual-licensing; do I just publish another copy of the source les with a GPL header, or is it more complicated than that?

Graeme (http://n/A)

October 15, 2021 at 10:14 pm (https://iosoft.blog/2020/09/29/raspberry-pi-multi-channel-ws2812/#comment-3995)

Hi there, thank you for this excellent article. I was just wondering if I am understanding the 16 bit-SMI transfer correctly. Let’s say that I am trying to output a 16 bit word via a 16 bit SMI transfer and the word is stored in memory as: yyyyyyyyxxxxxxxx where the x values denote the bits of the most signicant byte as per little-endian format. Am I correct in understanding that this would

Like (https://iosoft.blog/2020/09/29/raspberry-pi-multi-channel-ws2812/?like_comment=3995&_wpnonce=d134463e86)

Like (https://iosoft.blog/2020/09/29/raspberry-pi-multi-channel-ws2812/?like_comment=3996&_wpnonce=761b6de547)

Like (https://iosoft.blog/2020/09/29/raspberry-pi-multi-channel-ws2812/?like_comment=4104&_wpnonce=c6a72c32d6)

then be mapped to the SMI pins as follows during the transfer: (SD15)xxxxxxxxyyyyyyyy(SD0).

I am working on a project where I am trying to output RGB data through a video game console from the RPi and one uses big endian and the other little endian. I want to swap the lines of the adapter board to avoid cpu utilization byte-swapping but I just need to make sure that I am correctly understanding how the SMI bits are transferred.

Thank you very much for your time.

iosoftcode (https://iosoftblog.wordpress.com/)

October 16, 2021 at 10:15 am (https://iosoft.blog/2020/09/29/raspberry-pi-multi-channel-ws2812/#comment-3996)

That should be right, but I’d strongly recommend writing some simple test code to simulate what you intend to do, before you create the hardware. Some users have reported problems with my Smart LED driver when running in 16-bit mode, so I can’t help thinking there might be a serious bug somewhere.

Paul

November 1, 2021 at 2:18 am (https://iosoft.blog/2020/09/29/raspberry-pi-multi-channel-ws2812/#comment-4104)

This is awesome, thanks! Do you have an estimate for the maximum number of LEDs per channel this could drive? The rpi_ws281x library (working via PWM, PCM, SPI) has a maximum of about 5400 LEDs (2 channels of about 2700 LEDs per channel for PWM).

iosoftcode (https://iosoftblog.wordpress.com/)

Like (https://iosoft.blog/2020/09/29/raspberry-pi-multi-channel-ws2812/?like_comment=4105&_wpnonce=18585ba9ff)

Like (https://iosoft.blog/2020/09/29/raspberry-pi-multi-channel-ws2812/?like_comment=4301&_wpnonce=2fb8b229d3)

November 1, 2021 at 10:02 am (https://iosoft.blog/2020/09/29/raspberry-pi-multi-channel-ws2812/#comment-4105)

I am aware of someone using 3000 LEDs in 8 channels, but don’t have a maximum number. I guess the main constraint would be that most of the available DMA channels are ‘lite’ channels (see the BCM2835 ARM Peripherals document) that can only handle a maximum of 64K bytes per transfer, so you might need to use a non-lite channel (0 to 6) without disrupting those that are already taken by OS functions. There is also a limit as to the amount of uncached memory that the GPU will give you, but apart from that, I can’t think of any other theoretical limits.

With regard to using 16 channels, some users have reported problems with my code; I don’t have a lot of LEDs to test, and so far I’ve failed to nd the problem, so 8 channels is the safer option.

siberian microchimp service

December 10, 2021 at 9:39 am (https://iosoft.blog/2020/09/29/raspberry-pi-multi-channel-ws2812/#comment-4301)

Thanks to your unique knowledge, I managed to run ~10000 ws2811 with over 50 frames per second on rpi3. There were problems with “lite” DMA channel 10, but I discovered the ability to use channel 0 on rpi without a display (used by fbturbo).

On frosty evenings, when the vodka becomes thick and the snow creaks under the paws of domestic bears, thousands of iridescent LEDs on the sidewalk make the inhabitants of the small russian cyberpunk city freeze with delight and whisper “uh blya” (“how beautiful it is”). We sincerely thank you Tovarishch

Lean2 (https://iosoft.blog/)
/

Blog at WordPress.com. (https://wordpress.com/?ref=footer_blog)

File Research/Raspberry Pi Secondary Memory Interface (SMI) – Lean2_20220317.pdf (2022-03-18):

## Lean2 (https://iosoft.blog/)

Embedded systems without the bloat

# Raspberry Pi Secondary Memory Interface (SMI)

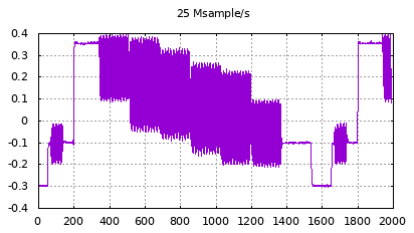
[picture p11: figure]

Colour video signal captured at 25 MS/s

The Secondary Memory Interface (SMI) is a parallel I/O interface that is included in all the Raspberry Pi versions. It is rarely used due to the acute lack of publicly-available documentation; the only information I can nd is in the source code to an external memory device driver here, (https://github.com/Ysurac/raspberry_kernel_mptcp/blob/master/include/linux/broadcom/bcm2835_smi.h) and an experimental IDE interface here. (https://github.com/fenlogic/IDE_trial)

However, it is a very useful general-purpose high-speed parallel interface, that deserves wider usage; in this post I’m testing it with digital-to-analogue and analogue-to-digital converters (DAC and ADC) but there are many other parallel-bus devices that would be suitable.

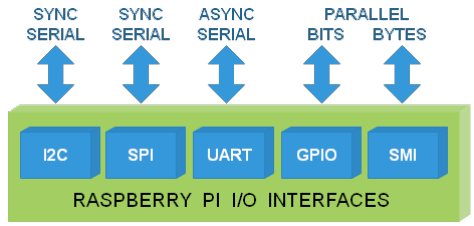
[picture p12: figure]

To take advantage of the high data rates, I’ll be using the C language, and Direct Memory Access (DMA); if you are unfamiliar with DMA on the RPi, I suggest you read my previous 2 posts on the subject, here (https://iosoft.blog/raspberry-pi-dma-programming/) and here. (https://iosoft.blog/fast-data-capture-raspberry-pi/)

## Parallel interface

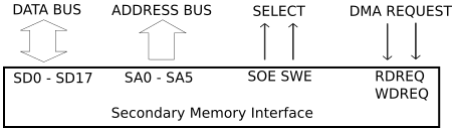
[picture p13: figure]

Raspberry Pi SMI signals

The SMI interface has up to 18 bits of data, 6 address lines, read & write select lines. Transfers can be initiated internally, or externally via read & write request lines, which can take over the uppermost 2 bits of the data bus. Transfer data widths are 8, 9, 16 or 18 bits, and are fully supported by First In First Out (FIFO) buers, and DMA; this makes for ecient memory usage when driving an 8-bit peripheral, since a single 32-bit DMA transfer can automatically be converted into four 8-bit accesses.

If you have ever worked with the classic bus-interfaces of the original microprocessors, you’ll feel quite at home with SMI, but no need to worry about timing problems, because the setup, strobe & hold times are fully
programmable with 4 nanosecond resolution; what luxury!

The SMI functions are assigned to specic GPIO pins:

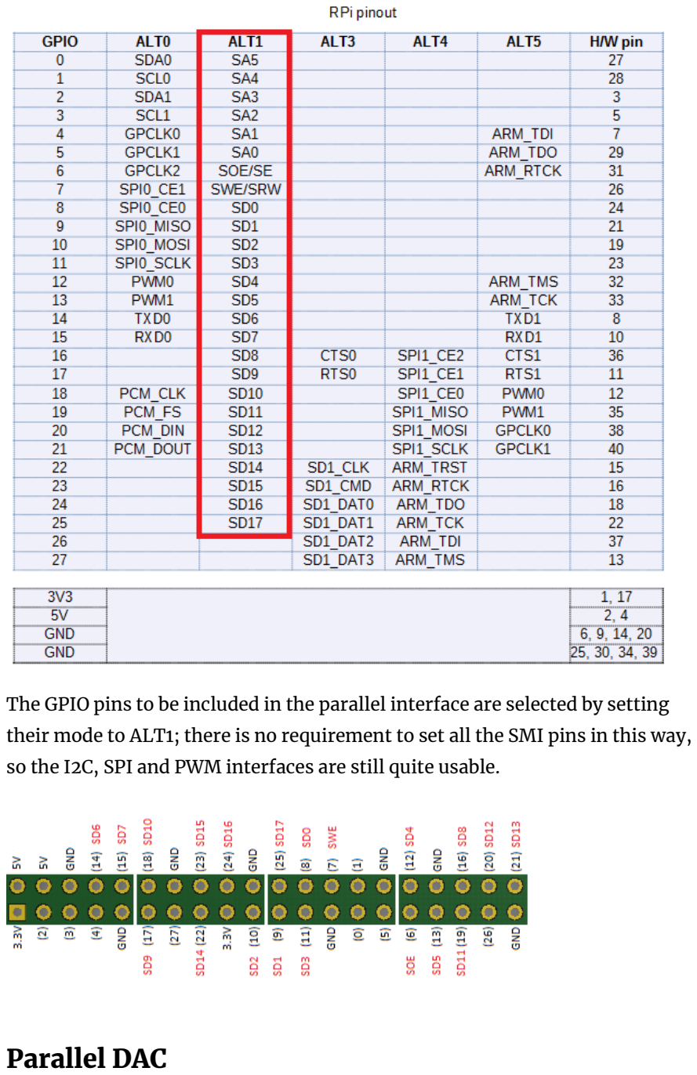
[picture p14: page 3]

The GPIO pins to be included in the parallel interface are selected by setting their mode to ALT1; there is no requirement to set all the SMI pins in this way, so the I2C, SPI and PWM interfaces are still quite usable.

## Parallel DAC

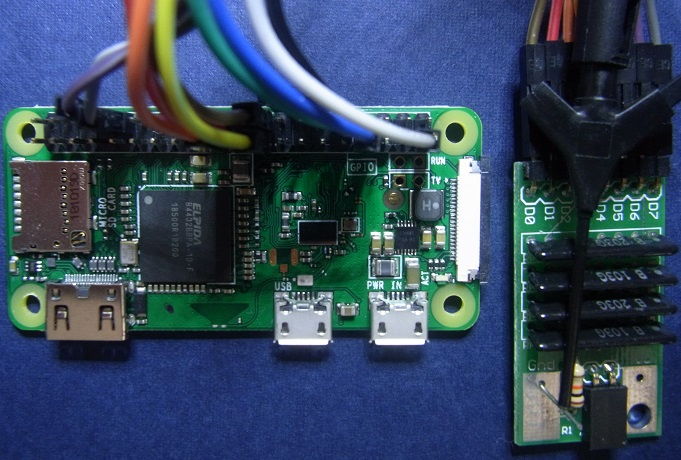
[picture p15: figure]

H A R D W A R E

The simplest device to drive from the parallel bus is a digital-to-analogue converter (DAC), using resistors from each data line to a common output. This arrangement is commonly known as an R-2R ladder, due to the resistor values needed.

I’ve used a pre-built device from Digilent (details here, (https://store.digilentinc.com/r2r-module-retired/) or newer version here) (https://store.digilentinc.com/pmod-r2r-resistor-ladder-d-a-converter/) but it is easy to make your own using discrete resistors; the least-signicant is connected to GPIO8 (SD0), and the most-signicant to GPIO15 (SD7).

S O F T W A R E

I’ll be making extensive use of the dma_utils functions that were created for my previous DMA projects, but before diving into the complication of SMI, it is helpful to test the hardware using simpler GPIO commands:

#define DAC_D0_PIN | 8

#define DAC_NPINS | 8

extern MEM_MAP gpio_regs;

This is less-than-ideal because we have to use one command to set some I/O pins to 1, and another command to clear the rest to 0, so in the gap between them the I/O state will be incorrect; also we won’t get accurate timing with the usleep command.

To my surprise, when I ran this code on a Pi Zero, and viewed the output on an oscilloscope, it didn’t look too bad; however, as soon as I moved the mouse, there were very signicant gaps in the output, so clearly we need to do better.

S M I R E G I S T E R D E F I N I T I O N S

To use SMI, we rst need to dene the control registers, and the bit-values within them. The primary reference is bcm2835_smi.h from the Broadcom external memory driver, but I found this dicult to use in my code, so converted the denitions into C bitelds; this makes the code a bit less portable, but a lot simpler and easier to read.

Also, when learning about a new peripheral, it is helpful if the biteld values can be printed on the console. This normally requires the tedious copying of map_periph(&gpio_regs, (void *)GPIO_BASE, PAGE_SIZE);

// Output value to resistor DAC (without SMI)
void dac_ladder_write(int val)
{
*REG32(gpio_regs, GPIO_SET0) = (val & 0xff) << DAC_D0_PIN; *REG32(gpio_regs, GPIO_CLR0) = (~val & 0xff) << DAC_D0_PIN; }

// Initialise resistor DAC
void dac_ladder_init(void)
{
int i;

for (i=0; i<DAC_NPINS; i++) gpio_mode(DAC_D0_PIN+i, GPIO_OUT); }

// Output sawtooth waveform dac_ladder_init();
while (1)
{
i = (i + 1) % 256;
dac_ladder_write(i);
usleep(10);
}

register eld names into string constants, but with a small amount of macro processing, this can be done with a single denition, for example the SMI CS register:

The last bit of code is needed so that smi_cs points to the register in virtual memory; if you don’t understand why, I suggest you read my post on RPi DMA programming here. (https://iosoft.blog/raspberry-pi-dma-programming/) Anyway, the upshot of all this code is that we can access the whole 32-bit value of the register as smi_cs->value, and also individual bits such as smi_cs->enable, smi_cs->done, etc.

To print out the bit values, we use macros to convert the register denition to a string, then have a simple C parser:

#define REG_DEF(name, fields) typedef union {struct {volatile uint32_t fields;}; volatile

#define SMI_CS_FIELDS \

enable:1, done:1, active:1, start:1, clear:1, write:1, _x1:2,\
teen:1, intd:1, intt:1, intr:1, pvmode:1, seterr:1, pxldat:1, edreq:1,\
_x2:8, _x3:1, aferr:1, txw:1, rxr:1, txd:1, rxd:1, txe:1, rxf:1 REG_DEF(SMI_CS_REG, SMI_CS_FIELDS);

volatile SMI_CS_REG *smi_cs;

smi_cs = (SMI_CS_REG *) REG32(smi_regs, SMI_CS);

#define STRS(x) STRS_(x) ","

#define STRS_(...) #__VA_ARGS__

char *smi_cs_regstrs = STRS(SMI_CS_FIELDS);

// Display bit values in register
void disp_reg_fields(char *regstrs, char *name, uint32_t val) {
char *p=regstrs, *q, *r=regstrs;
uint32_t nbits, v;

printf("%s %08X", name, val); while ((q = strchr(p, ':')) != 0) {
p = q + 1;
nbits = 0;
while (*p>='0' && *p<='9')
nbits = nbits * 10 + *p++ - '0'; v = val & ((1 << nbits) - 1);
val >>= nbits;
if (v && *r!='_')
printf(" %.*s=%X", q-r, r, v); while (*p==',' || *p==' ')
p = r = p + 1;
}

Now we can display all the non-zero bit values using:

..which produces a display like..

S M I R E G I S T E R S

The SMI registers are:

You can specify up to 4 unique timing settings for read & write, making 8 settings in total. The settings are specied by giving a 2-bit device number for each transaction; this selects 1 of the 4 descriptors for read or write. I’ve only used one pair of settings, and the ADC & DAC don’t have address lines, so the address & device register remains at zero.

Direct mode is a simple way of doing accesses using the appropriate timings, but without DMA; it has separate address, data and control registers.

Some notable elds in the control & status register are:

Enable: it is obvious that this bit must be set for SMI to work, but it is less obvious when that should be done. Initially, I assumed it was necessary to enable the interface before any other initialisation, but then it responded with the ‘settings error’ bit set. So now I do most of the conguration with the device disabled, then enable it before clearing the FIFOs and enabling DMA,

printf("\n");
}

disp_reg_fields(smi_cs_regstrs, "CS", *REG32(smi_regs, SMI_CS));

CS 54000025 enable=1 active=1 write=1 txw=1 txd=1 txe=1

CS: control and status
L: | data length (number of transfers)
A: | address and device number
D: | data FIFO
DMC: DMA control
DSR: device settings for read
DSW: device settings for write
DCS: direct control and status
DCA: direct control address and device number DCD: direct control data otherwise the transfers go through immediately.

Start: set this bit to start the transfer; the SMI controller will perform the number of transfers in the length register, using the timing parameters specied in DSR (for read) or DSW (for write). If there is a backlog of data (FIFO is full) the transaction may stall.

Pxldat: when this ‘pixel data’ bit is set, the 8- or 16-bit data is packed into 32-bit words.

Pvmode: I have no idea what this ‘pixel valve’ mode should do; any information would be gratefully received.

D I R E C T M O D E

As the name implies, SMI Direct Mode allows you to perform a single I/O transfer without DMA. However, it is still necessary to specify the timing parameters of the transfer, specically:

- The clock period, that will be used for the following timing:
- The setup time, that is used by the peripheral to decode the address value
- The width of the strobe pulse, that triggers the transfer
- The hold time, that keeps the signals stable after the transfer

To add to the complication, the SMI controller can drive 4 peripheral devices, each with its own individual read & write settings, so there are a total of 8 timing registers. I’m keeping this simple by always using the rst register pair (for device zero) but it is worth remembering that you can dene more than one set of timings, and quickly switch between them by setting the device number.

Likewise, I’m ignoring the address eld since it is also redundant for my DAC; for safety, I clear all the SMI registers on startup, in case there are any residual unwanted values.

As it happens, this setup/strobe/hold timing is largely redundant for our simple resistor DAC (since it doesn’t latch the data) but we still need to specify something, for example if we want the overall cycle time to be 1 microsecond, this can be achieved with a clock period of 10 nanoseconds, setup 25, strobe 50, and hold 25, since (25 + 50 + 25) * 10 = 1000 nanoseconds. This is the code I use to set the timing:

The clock-frequency-setting code is similar to that I used to set the PWM frequency for my DMA pacing; that peripheral did seem to be really sensitive to any glitches in the clock, so I’ve been a bit over-cautious in adding extra time-delays, which may not really be necessary.

The seterr ag is supposed to indicate an error if the settings have been changed while the SMI device is active; the easiest way to avoid this error is to do most of the settings while the device is disabled, then enable it just before

// Width values
#define SMI_8_BITS 0

#define SMI_16_BITS 1

#define SMI_18_BITS 2

#define SMI_9_BITS 3

// Initialise SMI interface, given time step, and setup/hold/strobe counts // Clock period is in nanoseconds: even numbers, 2 to 30
void init_smi(int width, int ns, int setup, int strobe, int hold)
{
int divi = ns/2;

smi_cs->value = smi_l->value = smi_a->value = 0;
smi_dsr->value = smi_dsw->value = smi_dcs->value = smi_dca->value = | 0;
if (*REG32(clk_regs, CLK_SMI_DIV) != divi << 12)
{
*REG32(clk_regs, CLK_SMI_CTL) = CLK_PASSWD | (1 << 5);
usleep(10);
while (*REG32(clk_regs, CLK_SMI_CTL) & (1 << 7)) ; usleep(10);
*REG32(clk_regs, CLK_SMI_DIV) = CLK_PASSWD | (divi << 12);
usleep(10);
*REG32(clk_regs, CLK_SMI_CTL) = CLK_PASSWD | 6 | (1 << 4);
usleep(10);
while ((*REG32(clk_regs, CLK_SMI_CTL) & (1 << 7)) == 0) ; usleep(100);
}
if (smi_cs->seterr)
smi_cs->seterr = 1;
smi_dsr->rsetup = smi_dsw->wsetup = setup; smi_dsr->rstrobe = smi_dsw->wstrobe = strobe; smi_dsr->rhold = smi_dsw->whold = hold; smi_dsr->rwidth = smi_dsw->wwidth = width;
}

starting; the ag is also cleared on startup, by writing a 1 to it.

Once the timing is set, the following code can be used to initiate a single direct-control write-cycle:

The code clears the FIFO, in case there is any data left over from a previous transaction (which isn’t unusual, if you have been using DMA), and the FIFO error ag, then enables the device. The transfer is initiated by clearing the completion ag, setting write mode, loading the value into the Direct Mode data register, then starting the cycle.

The transfer then proceeds using the specied timing, and the completion ag is set when complete. If we run this code with usleep for timing, there is very little dierence in the DAC output; it is still susceptible to other events, such as mouse movement, as shown in the oscilloscope trace below.

To gain maximum benet from SMI, we have to use DMA.

S M I A N D D M A

When using SMI with DMA, the fundamental question is where the DMA

// Initialise resistor DAC void dac_ladder_init(void) {
smi_cs->clear = 1;
smi_cs->aferr = 1;
smi_dcs->enable = 1;
}

// Output value to resistor DAC void dac_ladder_write(int val) {
smi_dcs->done = 1;
smi_dcs->write = 1;
smi_dcd->value = val & 0xff; smi_dcs->start = 1;
}

requests will be coming from.

They can be triggered by an external signal, in ‘DMA passthrough’ mode. The data lines SD 16 & 17 can be used as triggers; SD16 to write to an external device or SD17 to read from external device, with a maximum data width of 16 bits. It is important to note that they are level-sensitive signals (not edge-triggered) so if held high, the transfers will carry on at the maximum rate; see the oscilloscope trace below, where a 500 ns request is sucient to trigger 2 transfers.

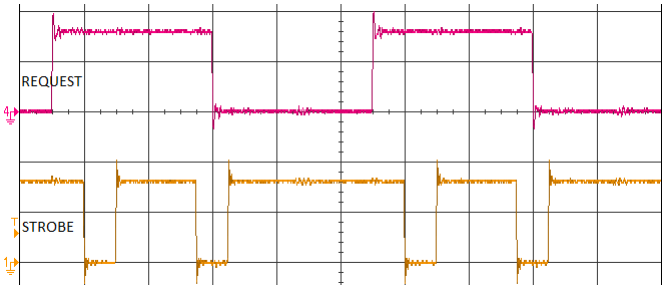
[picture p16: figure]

Oscilloscope trace of DMA passthrough (200 ns/div)

So DMA passthrough is designed for use with peripherals that assert the request when they have data to send, and negate it when the transfer has gone through. I have experimented with the PWM controller to generate narrow pulses, and it does seem possible to trigger single transfers this way, but more tests are needed to make sure this method is 100% reliable, so for the time being I won’t use it.

Instead, the requests will originate from the SMI controller itself; the transfer will proceed at the maximum speed dened by the setup, strobe & hold times, with DMA keeping the FIFOs topped up with data. This places a lower limit on the rate at which the transfers go through; the maximum clock resolution is 30 ns, and the maximum setup, strobe & hold values are 63, 127 and 63, giving a slowest cycle time of 7.6 microseconds.

The DMA Control Block is similar to those in my previous projects; it just needs a data source in uncached memory, data destination as the SMI FIFO, and length

A convenient way of outputting a repeating waveform is to create one cycle in memory, and set the control block to that length. Then the SMI length is set to the total number of bytes to be sent, assuming the pixel mode ag ‘pxldat’ has been set; this instructs the SMI controller to unpack the 32-bit DMA & FIFO values into 4 sequential output bytes.

The following trace was generated by a 256-byte ramp, repeated 6 times, using a 1 microsecond cycle time.

Oscilloscope trace of DAC output (200 us/div)

The SMI interface can generate much faster waveforms, but unfortunately they

#define NCYCLES 4

// DMA values to resistor DAC
void dac_ladder_dma(MEM_MAP *mp, uint8_t *data, int len, int repeat) {
DMA_CB *cbs=mp->virt;
uint8_t *txdata=(uint8_t *)(cbs+1);

memcpy(txdata, data, len);
enable_dma(DMA_CHAN_A);
cbs[0].ti = DMA_DEST_DREQ | (DMA_SMI_DREQ << 16) | DMA_CB_SRCE_INC;
cbs[0].tfr_len = NSAMPLES * NCYCLES;
cbs[0].srce_ad = MEM_BUS_ADDR(mp, txdata);
cbs[0].dest_ad = REG_BUS_ADDR(smi_regs, SMI_D);
cbs[0].next_cb = repeat ? MEM_BUS_ADDR(mp, &cbs[0]) : 0; start_dma(mp, DMA_CHAN_A, &cbs[0], 0);
}

smi_dsr->rwidth = SMI_8_BITS;
smi_l->len = NSAMPLES * REPEATS; smi_cs->pxldat = 1;
smi_dmc->dmaen = 1;
smi_cs->write = 1;
smi_cs->enable = 1;
smi_cs->clear = 1;
dac_ladder_dma(&vc_mem, sample_buff, sample_count, NCYCLES>1); smi_cs->start = 1;

aren’t rendered very well by the DAC as it uses 10K resistors; when these are combined with the oscilloscope probe input capacitance, the resulting rise time is around 500 nanoseconds. So for faster waveforms, you need a faster DAC.

R E A D C Y C L E T E S T

The last DAC test I’m going to do will seem a bit crazy: a read cycle. The settings are the same as the write-cycle, with the following changes:

The scope has been set to additionally show the SOE signal as the top trace:

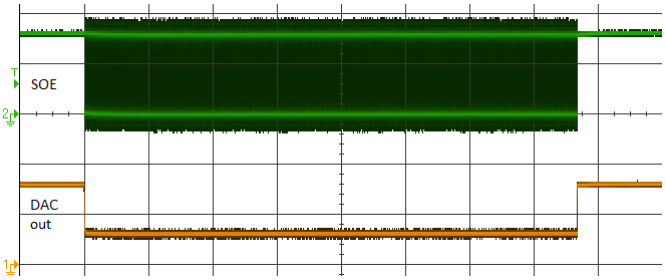
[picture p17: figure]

The DAC output starts at 3.3V which was the nal value of the previous output cycle. It then drops to 1.2V during the read cycles, as this is the value it oats to when the I/O lines aren’t being driven. At the end of the last read cycle, the output is driven back to 3.3V.

This is a very important result; as soon as the input cycles stop, SMI drives the bus. This is because memory chips don’t like a oating data bus; a halfway-on voltage can cause excessive power dissipation, and even damage the chip in extreme cases. So it is a sensible precaution that the data bus is always driven, though this is about to cause a major problem…

smi_cs->write = 1;

cbs[0].ti = DMA_SRCE_DREQ | (DMA_SMI_DREQ << 16) | DMA_CB_DEST_INC;
cbs[0].srce_ad = REG_BUS_ADDR(smi_regs, SMI_D);
cbs[0].dest_ad = MEM_BUS_ADDR(mp, txdata);

## AD9226 ADC

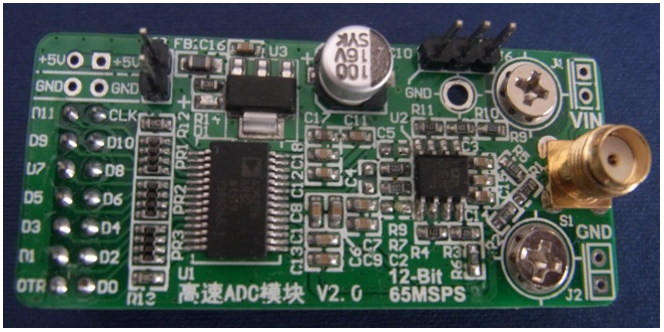
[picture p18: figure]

Searching the Internet for a fast low-cost analogue-to-digital (ADC) module with a parallel interface, I found very few; the best one featured the 12-bit AD9226, with a maximum throughput of 65 megasamples per second. It requires a 5 volt supply, but has a 3.3V logic interface, so is compatible with the Raspberry Pi.

Having worked with the module for a few days, I’ve found it to be less than ideal, for various reasons that’ll be given later, but it is still useful to demonstrate high-speed parallel input with SMI.

Connecting to the RPi isn’t dicult, but as we’re dealing with high-speed signals, it is necessary to keep the wiring short, preferably under 50 mm (2 inches), especially the power, ground & clock signals.

One minor confusion is that the pin marked D0 is the most-signicant bit, and D11 the least signicant; I wanted to leave the SPI0 pins free, so adopted the following connection scheme, which puts the data in the top 12 bits of a 16-bit SMI read cycle.:

H/W pin Function AD9226
------- ----------- ------31 GPIO06 SOE CLK
16 GPIO23 SD15 D0 (MSB)
15 GPIO22 SD14 D1
40 GPIO21 SD13 D2
38 GPIO20 SD12 D3

D I R E C T M O D E

We’ll start by using Direct Mode to obtain an sample without DMA. The ADC is designed to work with a continuous clock signal, but ours is derived from the SMI Output Enable (OE) line, so only changes state during data transfers.

The AD9226 data sheet describes how it stabilises the clock signal, and suggests it may require over 100 cycles when adapting to a new frequency. In practice, when starting up there seems to be a major data glitch after 8 cycles, but after that the conversions appear to have stabilised, so I allow for 10 cycles before taking a reading.

It is necessary to choose timing values for the SMI cycles; my default settings are 10 nanosecond time interval, with a setup of 25, strobe 50, hold 25, so the total cycle time is 10 * (25 + 50 + 25) = 1000 nanoseconds, or 1 megasample/sec.

V O L T A G E V A L U E

The ADC has an op-amp input circuit that can accommodate positive and negative voltages. Converting the ADC value to a voltage is a bit fraught; I

35 GPIO19 SD11 D4
12 GPIO18 SD10 D5
11 GPIO17 SD9 D6
36 GPIO16 SD8 D7
10 GPIO15 SD7 D8
8 GPIO14 SD6 D9
33 GPIO13 SD5 D10
32 GPIO12 SD4 D11 (LSB)
2 | 5V | +5V
6 | GND | GND

for (i=0; i<ADC_NPINS; i++) gpio_mode(ADC_D0_PIN+i, GPIO_IN); gpio_mode(SMI_SOE_PIN, GPIO_ALT1);

init_smi(SMI_16_BITS, 10, 25, 50, 25); // 1 MS/s

smi_start(10, 1);
usleep(20);
val = adc_gpio_val();
printf("%4u %1.3f\n", val, val_volts(val));

determined the following values by experimentation with one module, but suspect they are subject to quite wide component tolerances, so won’t be the same for all modules.

It is important to note that the module has a 50-ohm input, so imposes a very heavy loading on any circuit it is monitoring. It can’t cope with signicant voltages for any period of time; for example, if you apply 5 volts, the input resistor will dissipate half a watt, heat up rapidly, and probably burn out.

So, although the ADC is excellent for fast data acquisition, the module isn’t really suitable for general purpose measurement, and would benet from a redesign with a high-impedance input.

A V O I D I N G B U S C O N F L I C T S

The module doesn’t have a chip-select or chip-enable input, so the data is always being output; the 28-pin version of the AD9226 doesn’t have the facility for disabling its output drivers. In the above code I avoided the possibility of bus conicts doing a GPIO register read, but for high speeds we have to use SMI read cycles. This is potentially a major problem; when the read cycles are complete, the SMI controller and the ADC will both try to drive the data bus at the same time, causing signicant current draw, only limited by the 100 ohm resistors on the module: they are insucient to keep the current below the maximum values (16 mA per pin, 50 mA total for all I/O) in the Broadcom data sheet.

#define ADC_ZERO | 2080

#define ADC_SCALE | 410.0

// Convert ADC value to voltage
float val_volts(int val)
{
return((ADC_ZERO - val) / ADC_SCALE); }

// Return ADC value, using GPIO inputs int adc_gpio_val(void)
{
int v = *REG32(gpio_regs, GPIO_LEV0);

return((v>>ADC_D0_PIN) & ((1 << ADC_NPINS)-1)); }

I’ve experimented with various software solutions, basically using a DMA Control Block to set the ADC pins to SMI mode (ALT1), then the second CB for the data transfer, then a third to set the pins back to GPIO inputs. The problem with this approach is that at the higher transfer rates the DMA controller is only just keeping up with the incoming data, and there is a sizeable backlog that has to be cleared before the DMA completes. So there is a signicant delay before the SMI pins are set back to inputs, and in that time, there is a bus conict.

For this reason (and to avoid any concerns about hardware damage when debugging new code) I added a resistor in series with each data line, to reduce the current ow when a bus conict occurs. The value is a compromise; the resistance needs to be high enough to block excessive current, but not so high that it will slow down the I/O transitions too much, when combined with the stray capacitance of the GPIO inputs.

I chose 330 ohms, which combines with the 100 ohms already on the module, to produce a maximum current of 7.7 mA per line. This is well within the per-pin limit of the Broadcom device, but if all the lines are in conict, the total will actually exceed the maximum chip I/O current, so it is inadvisable to leave the hardware in this state for a signicant period of time.

A D C C O D E

If you’ve read my previous blogs on fast ADC data capture, the DMA code will seem quite familiar, with control blocks to set the GPIO pins to SMI mode, capture the data, and restore the pins:

// Get GPIO mode value into 32-bit word
void mode_word(uint32_t *wp, int n, uint32_t mode) {
uint32_t mask = 7 << (n * 3);
*wp = (*wp & ~mask) | (mode << (n * 3));
}

// Start DMA for SMI ADC, return Rx data buffer uint32_t *adc_dma_start(MEM_MAP *mp, int nsamp)
{
DMA_CB *cbs=mp->virt;
uint32_t *data=(uint32_t *)(cbs+4), *pindata=data+8, *modes=data+0x10; uint32_t *modep1=data+0x18, *modep2=modep1+1, *rxdata=data+0x20, i;

When DMA is complete, we have a data buer in uncached memory, containing left-justied 16-bit samples packed into 32-bit words; they are shifted and copied into the sample buer. The rst few samples are discarded as they are erratic; the ADC needs several clock cycles before its internal logic is stable.

// Get current mode register values
for (i=0; i<3; i++)
modes[i] = modes[i+3] = *REG32(gpio_regs, GPIO_MODE0 + i*4); // Get mode values with ADC pins set to SMI
for (i=ADC_D0_PIN; i<ADC_D0_PIN+ADC_NPINS; i++) mode_word(&modes[i/10], i%10, GPIO_ALT1);
// Copy mode values into 32-bit words
*modep1 = modes[1];
*modep2 = modes[2];
*pindata = 1 << TEST_PIN;
enable_dma(DMA_CHAN_A);
// Control blocks 0 and 1: enable SMI I/P pins
cbs[0].ti = DMA_SRCE_DREQ | (DMA_SMI_DREQ << 16) | DMA_WAIT_RESP;
cbs[0].tfr_len = 4;
cbs[0].srce_ad = MEM_BUS_ADDR(mp, modep1);
cbs[0].dest_ad = REG_BUS_ADDR(gpio_regs, GPIO_MODE0+4); cbs[0].next_cb = MEM_BUS_ADDR(mp, &cbs[1]); cbs[1].tfr_len = 4;
cbs[1].srce_ad = MEM_BUS_ADDR(mp, modep2); cbs[1].dest_ad = REG_BUS_ADDR(gpio_regs, GPIO_MODE0+8); cbs[1].next_cb = MEM_BUS_ADDR(mp, &cbs[2]);
// Control block 2: read data
cbs[2].ti = DMA_SRCE_DREQ | (DMA_SMI_DREQ << 16) | DMA_CB_DEST_INC;
cbs[2].tfr_len = (nsamp + PRE_SAMP) * SAMPLE_SIZE;
cbs[2].srce_ad = REG_BUS_ADDR(smi_regs, SMI_D);
cbs[2].dest_ad = MEM_BUS_ADDR(mp, rxdata);
cbs[2].next_cb = MEM_BUS_ADDR(mp, &cbs[3]);
// Control block 3: disable SMI I/P pins
cbs[3].ti = DMA_CB_SRCE_INC | DMA_CB_DEST_INC;
cbs[3].tfr_len = 3 * 4;
cbs[3].srce_ad = MEM_BUS_ADDR(mp, &modes[3]); cbs[3].dest_ad = REG_BUS_ADDR(gpio_regs, GPIO_MODE0); start_dma(mp, DMA_CHAN_A, &cbs[0], 0); return(rxdata);
}

// ADC DMA is complete, get data
int adc_dma_end(void *buff, uint16_t *data, int nsamp) {
uint16_t *bp = (uint16_t *)buff;
int i;

for (i=0; i<nsamp+PRE_SAMP; i++) {
if (i >= PRE_SAMP)
*data++ = bp[i] >> 4;
}
return(nsamp);
}

## ADC speed tests

The important question is: how fast can we run the SMI interface? Here are the settings for some tests:

The SMI clock is 1 GHz; the rst number is the clock divisor, followed by the setup, strobe & hold counts, so 1000 / (10 * (25+50+25)) = 1 MS/s. Where possible, I’ve tried to keep the waveform symmetrical by making setup + hold = strobe, but that isn’t essential; the ADC can handle asymmetric clock signals.

R P I V 3

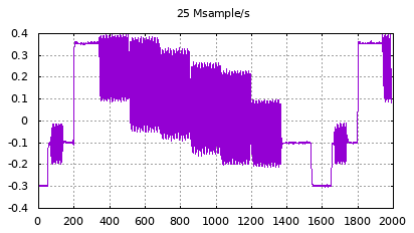
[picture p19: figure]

25 MS/s capture of a video test waveform

Running on a Raspberry Pi 3B v1.2, the fastest continuous rate that produces consistent results is 25 megasamples per second. The following trace shows a data line and the SOE (ADC clock) line, with a 40-byte transfer at 25 MS/s:

// RPi v0-3
#define SMI_NUM_BITS | SMI_16_BITS

#define SMI_TIMING | SMI_TIMING_25M

#define SMI_TIMING_1M | 10, 25, 50, 25 // 1 MS/s

#define SMI_TIMING_20M | 2, 6, 13, 6 // 20 MS/s

#define SMI_TIMING_25M | 2, 5, 10, 5 // 25 MS/s

#define SMI_TIMING_31M | 2, 4, 6, 4 // 31.25 MS/s

#define SMI_TIMING_50M | 2, 3, 5, 2 // 50 MS/s

init_smi(SMI_16_BITS, SMI_TIMING);

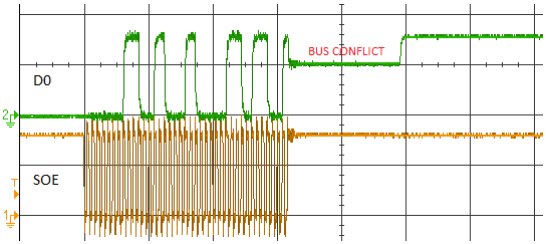
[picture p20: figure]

Scope trace 500 ns/div, 2 volts/div

The data line is being measured on the ADC module connector, so when there is a bus conict, the 100 ohm resistor on the module combines with the 330 ohms on the data line to form a potential divider, that makes the conict easy to see. It is inevitable that there will be a brief conict as the read cycles end, and the SMI controller takes control of the bus, but it only lasts 900 nanoseconds, which shouldn’t be an issue, given the resistor values I’m using.

However, increasing the rate to 31.25 MS/s does cause a problem:

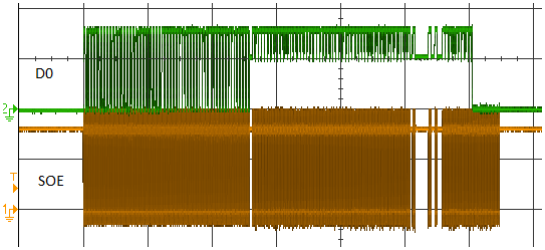
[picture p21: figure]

Scope trace 5 us/div, 2 volts/div

The system seems able to handle this rate ne for about 13 microseconds (400 samples), then it all goes wrong; there is a gap in the transfers, followed by continuous bus conicts. Zooming in to that area, the SMI controller seems to transition between continuous evenly-paced cycles, to bursts of 8, with a continuous conict:

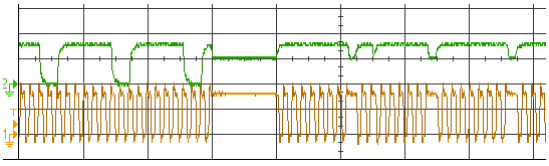
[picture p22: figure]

Scope trace 200 ns/div, 2 volts/div

In the absence of any documentation on the SMI controller, it is dicult to speculate on the reasons for this, but it does emphasise the need for caution when working with high-speed transfers.

Since 16-bit transfers work at 25 MS/s, it should be possible to run 8-bit transfers at 50 MS/s. This can be tested using the following settings:

With ADC connections I’m using, this doesn’t produce useful data (just the top 4 bits from the ADC), but the waveforms look ne on an oscilloscope, so there doesn’t seem to be a problem running 50 megabyte-per-second SMI transfers on an RPi v3.

P I Z E R O W

Switching to a Pi ZeroW, the results are remarkably good; here is a 500 kHz triangle wave, captured at 41.7 megasamples per second

#define SMI_NUM_BITS | SMI_8_BITS

#define SMI_TIMING | SMI_TIMING_50M

#define SAMPLE_SIZE | 1

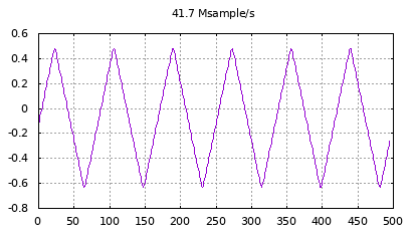
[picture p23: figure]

Capture of 500 kHz triangle wave

This does seem to be the top speed for a Pi ZeroW, as increasing the transfer rate to 50 MS/s causes some errors in the data. However, being able to transfer over 83 megabytes per second is a remarkably good result for this low-cost computer.

The question is whether this transfer rate is completely reliable; for example, is it disrupted by network activity? The easiest way to generate a lot of network trac is using ‘ood pings’ from a Linux PC to the RPi; I did a few data captures with pings running, and they didn’t seem to have any eect on the data, but more testing is needed.

R P I V 4

The rst test of a Rpi v4 at 1 MS/s actually produced 1.5 MS/s, so the base SMI clock for RPi v4 must be 1.5 GHz. This means a new set of speed denitions:

As before, the rst number is the clock divisor, followed by the setup, strobe & hold counts, so 1500 / (10 * (38+74+38)) = 1 MS/s.

Unfortunately the maximum throughput with the current code is quite poor; the following trace is for 500 samples at 25 MS/s, and you can see the bus contention towards the end, similar to that I experienced on the RPi v3.

// RPi v4
#define SMI_TIMING_1M | 10, 38, 74, 38 // 1 MS/s

#define SMI_TIMING_10M | 6, 6, 13, 6 // 10 MS/s

#define SMI_TIMING_20M | 4, 5, 9, 5 // 19.74 MS/s

#define SMI_TIMING_25M | 4, 3, 8, 4 // 25 MS/s

#define SMI_TIMING_31M | 4, 3, 6, 3 // 31.25 MS/s

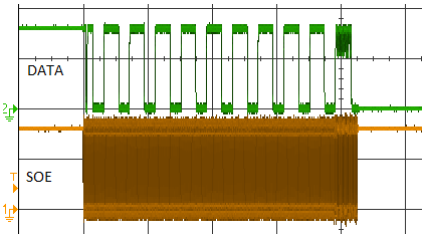
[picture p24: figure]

Scope trace 5 usec/div, 2 volts/div

The upper trace is the most signicant ADC bit (measured at the module pin), and the analogue input is a 500 kHz sine wave, hence the regular bit transitions.

The key question is: why does the throughput get worse with a faster processor? I’d guess that this is a memory bandwidth issue; with a single core, the DMA controller can eectively monopolise the memory, always getting the data through. On a multi-core processor, it has to cooperate with all the cores that are active during the data capture.

Clearly more work is needed to understand this phenomenon, for example by manipulating the cores and process priorities; alternatively, for maximum performance, just use a Pi Zero!

## Running the code

The source code is on Github here. (https://github.com/jbentham/rpi) The main les for DAC and ADC are rpi_smi_dac_test.c and rpi_smi_adc_test.c; the other les needed are rpi_dma_utils.c, rpi_dma_utils.h and rpi_smi_defs.h.

It is necessary to edit the top of rpi_dma_utils.h depending on which RPi hardware you are using:

// Location of peripheral registers in physical memory #define PHYS_REG_BASE PI_23_REG_BASE
#define PI_01_REG_BASE 0x20000000 // Pi Zero or 1 #define PI_23_REG_BASE 0x3F000000 // Pi 2 or 3 #define PI_4_REG_BASE 0xFE000000 // Pi 4

## 39 thoughts on “Raspberry Pi Secondary Memory

There are other settings at the top of the main les, that can be changed as required. The code can then be compiled with gcc, optionally with the -O2 option to optimise the code (which isn’t really necessary), and the -pedantic option if you want to check for extra warnings:

The code is run using sudo, optionally with the CSV output piped to a le:

The CSV le can be imported into a spreadsheet, or plotted using Gnuplot from the RPi command line, e.g.

You may have read elsewhere that it is necessary to enable SMI in /boot/cong.txt:

This sets the GPIO mode of the SMI pins on startup; it isn’t necessary for my code, which does its own GPIO conguration, with the added advantage that the unused pins are unchanged, so are free for use by other I/O functions.

If you want to see an example of SMI being used as a multi-channel pulse generator, see my 16 channel NeoPixel smart LED example here. (https://iosoft.blog/raspberry-pi-multi-channel-ws2812/)

Copyright (c) Jeremy P Bentham 2020. Please credit this blog if you use the information or software in it.

July 16, 2020 (https://iosoft.blog/2020/07/16/raspberry-pi-smi/) Data acquisition, (https://iosoft.blog/category/data-acquisition/) DMA, (https://iosoft.blog/category/dma/) Raspberry Pi, (https://iosoft.blog/category/raspberry-pi/) Secondary Memory Interface (https://iosoft.blog/category/secondary-memory-interface/) gcc -Wall -pedantic -o rpi_smi_adc rpi_smi_adc.c rpi_dma_utils.c

sudo ./rpi_smi_adc
..or..
sudo ./rpi_smi_adc > test6.csv

gnuplot -e "set term png size 420,240 font 'sans,8'; \
set title '41.7 Msample/s'; set grid; set key noautotitle; \ set output 'test6.png'; plot 'test6.csv' every ::10 with lines"

dtoverlay=smi # Not needed!

/

Like (https://iosoft.blog/2020/07/16/raspberry-pi-smi/?like_comment=1886&_wpnonce=b44f1bb8a9)

Like (https://iosoft.blog/2020/07/16/raspberry-pi-smi/?like_comment=1890&_wpnonce=fda49ccedf)

Like (https://iosoft.blog/2020/07/16/raspberry-pi-smi/?like_comment=1891&_wpnonce=ae103a533e)

## Interface (SMI)”

Pete

September 2, 2020 at 9:54 pm (https://iosoft.blog/2020/07/16/raspberry-pi-smi/#comment-1886)

The question on everyone’s mind is: Can this be used to drive WS2812 RGB LEDs?

iosoftcode (https://iosoftblog.wordpress.com/)

September 3, 2020 at 1:05 pm (https://iosoft.blog/2020/07/16/raspberry-pi-smi/#comment-1890)

A very good question. I think the answer is yes, but I’ll do some tests and post the results.

Pete

September 3, 2020 at 7:05 pm (https://iosoft.blog/2020/07/16/raspberry-pi-smi/#comment-1891)

Dude, if this is can drive 4 or more channels reliably, you would be a hero within the DIY Christmas Lights community! Especially if it can be scaled down to run on a Pi ZeroW…
Good luck!

iosoftcode (https://iosoftblog.wordpress.com/)

September 15, 2020 at 7:37 pm (https://iosoft.blog/2020/07/16/raspberry-pi-smi/#comment-1935)

The tests are very successful; I’m driving 8 channels on a ZeroW without any problems. I just need to add a user interface, and do the writeup. Watch

Liked (https://iosoft.blog/2020/07/16/raspberry-pi-smi/?like_comment=1935&_wpnonce=86d42b8943) by 1 person (https://iosoft.blog/2020/07/16/raspberry-pi-smi/#)

Like (https://iosoft.blog/2020/07/16/raspberry-pi-smi/?like_comment=1936&_wpnonce=c547ae69c1)

Like (https://iosoft.blog/2020/07/16/raspberry-pi-smi/?like_comment=1965&_wpnonce=b64210e4f5)

this space…

Pete

September 16, 2020 at 2:45 pm (https://iosoft.blog/2020/07/16/raspberry-pi-smi/#comment-1936)

You rock!! Looking forward to your writeup..
Be prepared for a large inux of trac. You may want to monetize rst or get a sponsor.

iosoftcode (https://iosoftblog.wordpress.com/)

September 29, 2020 at 8:10 pm (https://iosoft.blog/2020/07/16/raspberry-pi-smi/#comment-1965)

I’ve posted the NeoPixel project at https://iosoft.blog/raspberry-pi-multi-channel-ws2812/ (https://iosoft.blog/raspberry-pi-multi-channel-ws2812/)

Like (https://iosoft.blog/2020/07/16/raspberry-pi-smi/?like_comment=2101&_wpnonce=81c61d873e)

Like (https://iosoft.blog/2020/07/16/raspberry-pi-smi/?like_comment=2102&_wpnonce=f042ea180c)

KOKO. PE. (http://e-dessa.gr/)

October 29, 2020 at 3:04 pm (https://iosoft.blog/2020/07/16/raspberry-pi-smi/#comment-2101)

I am working on an fpga for raspberry pi and I already have a implemented a simple half duplex parallel communication. But that tops at 4mb/s.
After reading your post I thought to give smi a go. But there is one little problem. On my board gpio 7 aka swe/srw is used as tck line for fpga programming and cannot be used.
Now heres my question. Do you think I can use any other pin as swe/srw? I cannot change my design easily so I am looking for alternatives. I guess it would require a modied smi module for linux kernel but is it doable?

iosoftcode (https://iosoftblog.wordpress.com/)

October 29, 2020 at 8:39 pm (https://iosoft.blog/2020/07/16/raspberry-pi-smi/#comment-2102)

The short answer is no; the SMI pin assignment is done in Pi hardware, so it can not be changed in software.
However, you could use another pin as a substitute by tweaking the communications between the Pi and FPGA; for example, if you always do read cycles from address 0, and write cycles to address 1, then the SA0 pin eectively becomes a read/write indicator.

Marcel (http://-/)

February 17, 2021 at 5:33 pm (https://iosoft.blog/2020/07/16/raspberry-pi-smi/#comment-2812)

I was really looking for smething like this to implement an high speed interface to an FPGA to the RPI4. It is really a pity that most of the information is kept “secret” buy Broadcom and the RPI foundation. There is nothing special about a parallel bus like this, so why do not provide the documentation.

Like (https://iosoft.blog/2020/07/16/raspberry-pi-smi/?like_comment=2812&_wpnonce=c68bf9c504)

Like (https://iosoft.blog/2020/07/16/raspberry-pi-smi/?like_comment=2813&_wpnonce=beb138851a)

Like (https://iosoft.blog/2020/07/16/raspberry-pi-smi/?like_comment=3248&_wpnonce=a7d602ca11)

iosoftcode (https://iosoftblog.wordpress.com/)

February 17, 2021 at 9:14 pm (https://iosoft.blog/2020/07/16/raspberry-pi-smi/#comment-2813)

I’m working on an FPGA project with an SMI interface, so will probably be posting something in the next month or two.

With regard the ‘secret’ information, the Pi foundation would probably publish if they could, but are legally restricted by Broadcom, and that company would need a signicant commercial incentive to change the current situation.

How many more chips will they sell, if the information is released? Not many…

Michael

May 6, 2021 at 11:17 pm (https://iosoft.blog/2020/07/16/raspberry-pi-smi/#comment-3248)

Thank you for this awesome bit of work. I have one question. I’m working on a project where I’m connecting to another system that needs to send a lot of 16bit data, and I need that system to handle the data clock because it has a lot of other stu going on. Have you gured out any way to have the smi clocked externally?

iosoftcode (https://iosoftblog.wordpress.com/)

May 7, 2021 at 8:46 am (https://iosoft.blog/2020/07/16/raspberry-pi-smi/#comment-3249)

You can trigger an SMI cycle using the external request line, however the timing of that request is important; it must be negated before the end of the

Like (https://iosoft.blog/2020/07/16/raspberry-pi-smi/?like_comment=3249&_wpnonce=003d8eed0a)

Like (https://iosoft.blog/2020/07/16/raspberry-pi-smi/?like_comment=3251&_wpnonce=13b2e407ce)

SMI cycle, otherwise a second cycle will start.
So the answer is ‘maybe’, depending on the actual timing of your external clock signal.

Jake

May 8, 2021 at 4:52 am (https://iosoft.blog/2020/07/16/raspberry-pi-smi/#comment-3251)

I admire your wonderful research.

I am following your research with RPi4 and AD9226.
However, the AD9226 output signal goes back and forth continuously between -5 and 5. (calculated voltage value)
In my opinion, voltage should output 0 if there is no input to AD9226.
Are there any special actions I should take to stabilize the AD9226’s output signal?

iosoftcode (https://iosoftblog.wordpress.com/)

May 8, 2021 at 8:58 am (https://iosoft.blog/2020/07/16/raspberry-pi-smi/#comment-3253)

I suggest you take a look at the AD9226 data sheet; the device measures the dierential voltage between VINA and VINB; if VINB is greater than VINA, it will report a negative value. Also, if you are using the same ADC module as I did, there is an additional input circuit that shifts the measuring range to around 0V, i.e. it will report +ve and -ve voltages with respect to ground. Sadly the details of this circuit aren’t published, so I don’t know exactly what they have done.

All this is very dierent to a simple ADC such as the MCP3008, which can only measure positive voltages, but the AD9226 is designed to do a very dierent job.

Like (https://iosoft.blog/2020/07/16/raspberry-pi-smi/?like_comment=3253&_wpnonce=2988a4f819)

Like (https://iosoft.blog/2020/07/16/raspberry-pi-smi/?like_comment=3401&_wpnonce=2b25858d8c)

icarletto (http://gravatar.com/icarletto)

June 9, 2021 at 10:45 am (https://iosoft.blog/2020/07/16/raspberry-pi-smi/#comment-3401)

Hi, this is a very nice work and I am now trying to replicate it, although I am focusing on the DMA passthrough mode.
I have never used a bus-interface before, therefore it would be helpful if could clarify few points:

– the lines SOE_N/SE and SWE_N/SRW seem to be both output: in my understanding the rst gives the temporization for read/write operations, but what is the purpose of the second?
– at the beginning of the section “SMI and DMA” you say that the transfer takes place if the request is held low, but I actually see the two strobe pulses take place while the request is high (am I interpreting it wrong?)
– always in the same section, I guess the line REQUEST in the oscilloscope can be either pin SD16 or SD17 but just to be sure, is SOE the line STROBE?
– does the data read/write take place on the rising or falling edge of SOE?
– can you please point me at the settings I need to change to use DMA in passthrough mode?

iosoftcode (https://iosoftblog.wordpress.com/)

June 9, 2021 at 7:04 pm (https://iosoft.blog/2020/07/16/raspberry-pi-smi/#comment-3402)

To address your points in turn:
1. SMI is designed to emulate a CPU data bus, and there are 2 types in common usage; those that have a strobe plus a signal that indicates if it is a read or write cycle (e.g. Motorola 68k), and those that have separate strobes for read & write (e.g. Intel 8080). That is why these signals can be congured 2 dierent ways, probably using mode68 bit in SMI_DSR_REG.
2. I think there is a mistake in the text; transfers occur while the request is

Liked (https://iosoft.blog/2020/07/16/raspberry-pi-smi/?like_comment=3402&_wpnonce=3836a54a53) by 1 person (https://iosoft.blog/2020/07/16/raspberry-pi-smi/#)

Like (https://iosoft.blog/2020/07/16/raspberry-pi-smi/?like_comment=3407&_wpnonce=ee0212ed3a)

Like (https://iosoft.blog/2020/07/16/raspberry-pi-smi/?like_comment=3410&_wpnonce=8083402390)

high.

3. Yes
4. Not sure.
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

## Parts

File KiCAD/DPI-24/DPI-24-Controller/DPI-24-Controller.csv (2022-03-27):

Source: | D:\Documents\1. Online Dynamic\Git Repositories\Owl_Cape\KiCAD\Owl_Cape\owl_cape.kicad_sch
Date: | 25/03/2022 23:29:27
Tool: | Eeschema (6.0.4)
Generator: | C:\Program Files\KiCad\6.0\bin\scripting\plugins/bom_csv_grouped_by_value_with_fp.py
Component Count: | 118
Ref | Qnty | Value | Cmp name | Footprint | Description | Vendor
C1, C2, | 2 | 0.1uF | C_Small | Capacitor_SMD:CP_Elec_4x5.3 | Unpolarized capacitor, small symbol
C3, | 1 | 0.1uF | C_Small |  | Unpolarized capacitor, small symbol
D1, D2, D3, D4, D5, D6, D7, D8, | 8 | 0603 | LED | LED_SMD:LED_0603_1608Metric | Light emitting diode
D9, D10, D11, D12, D13, D14, D15, D16, | 8 | 0603 | LED |  | Light emitting diode
D17, | 1 | V1 LED | LED | LED_SMD:LED_0603_1608Metric | Light emitting diode
D18, | 1 | V2 LED | LED | LED_SMD:LED_0603_1608Metric | Light emitting diode
D19, | 1 | 5V LED | LED | LED_SMD:LED_0603_1608Metric | Light emitting diode
D20, D21, D22, | 3 | SB5100 | D_Schottky | Diode_THT:D_DO-201AD_P12.70mm_Horizontal | Schottky diode
D23, | 1 | Zenner 5.1 | D_Zener | Diode_THT:D_5W_P10.16mm_Horizontal | Zener diode
F1, | 1 | P1 | Fuse | Fuse:Fuseholder_Blade_Mini_Keystone_3568 | Fuse
F2, | 1 | P2 | Fuse | Fuse:Fuseholder_Blade_Mini_Keystone_3568 | Fuse
F3, | 1 | P3 | Fuse | Fuse:Fuseholder_Blade_Mini_Keystone_3568 | Fuse
F4, | 1 | P4 | Fuse | Fuse:Fuseholder_Blade_Mini_Keystone_3568 | Fuse
F5, | 1 | P5 | Fuse | Fuse:Fuseholder_Blade_Mini_Keystone_3568 | Fuse
F6, | 1 | P6 | Fuse | Fuse:Fuseholder_Blade_Mini_Keystone_3568 | Fuse
F7, | 1 | P7 | Fuse | Fuse:Fuseholder_Blade_Mini_Keystone_3568 | Fuse
F8, | 1 | P8 | Fuse | Fuse:Fuseholder_Blade_Mini_Keystone_3568 | Fuse
F9, | 1 | P1 | Fuse |  | Fuse
F10, | 1 | P2 | Fuse |  | Fuse
F11, | 1 | P3 | Fuse |  | Fuse
F12, | 1 | P4 | Fuse |  | Fuse
F13, | 1 | P5 | Fuse |  | Fuse
F14, | 1 | P6 | Fuse |  | Fuse
F15, | 1 | P7 | Fuse |  | Fuse
F16, | 1 | P8 | Fuse |  | Fuse
F17, | 1 | 2A Max | Fuse | Fuse:Fuseholder_Blade_Mini_Keystone_3568 | Fuse
F18, F19, | 2 | 30A Max | Fuse | Fuse:Fuseholder_Blade_Mini_Keystone_3568 | Fuse
H5, H6, H7, H8, H9, H10, | 6 | M3 MountingHole | MountingHole | MountingHole:MountingHole_3.2mm_M3_Pad_TopBottom | Mounting Hole without connection
IC1, | 1 | SN74HC244N | SN74HC244N-SamacSys_Parts | SamacSys_Parts:DIP794W53P254L2540H508Q20N
IC2, | 1 | SN74HC244N | SN74HC244N-SamacSys_Parts | DIP794W53P254L2540H508Q20N
J1, J2, J3, J4, J5, J6, J7, J8, | 8 | G D V | 284514-3-SamacSys_Parts | SamacSys_Parts:SHDR3W80P0X350_1X3_1250X725X940P
J9, J10, J11, J12, J13, J14, J15, J16, | 8 | G D V | 284514-3-SamacSys_Parts | SHDR3W80P0X350_1X3_1250X725X940P
J21, | 1 | Aux In | Screw_Terminal_01x02 | TerminalBlock_MetzConnect:TerminalBlock_MetzConnect_Type701_RT11L02HGLU_1x02_P6.35mm_Horizontal | Generic screw terminal, single row, 01x02, script generated (kicad-library-utils/schlib/autogen/connector/)
J22, | 1 | 9-16 In | Screw_Terminal_01x02 | TerminalBlock_MetzConnect:TerminalBlock_MetzConnect_Type701_RT11L02HGLU_1x02_P6.35mm_Horizontal | Generic screw terminal, single row, 01x02, script generated (kicad-library-utils/schlib/autogen/connector/)
J23, | 1 | 1-8 In | Screw_Terminal_01x02 | TerminalBlock_MetzConnect:TerminalBlock_MetzConnect_Type701_RT11L02HGLU_1x02_P6.35mm_Horizontal | Generic screw terminal, single row, 01x02, script generated (kicad-library-utils/schlib/autogen/connector/)
J30, | 1 | Conn_02x20_Odd_Even_MountingPin | Conn_02x20_Odd_Even_MountingPin | Connector_PinHeader_2.54mm:PinHeader_2x20_P2.54mm_Vertical_SMD | Generic connectable mounting pin connector, double row, 02x20, odd/even pin numbering scheme (row 1 odd numbers, row 2 even numbers), script generated (kicad-library-utils/schlib/autogen/connector/)
Q1, | 1 | MMDT5401 | MMDT5401 | Package_TO_SOT_SMD:SOT-363_SC-70-6 | 200mA IC, 160V Vce, Dual PNP/PNP Transistors, SOT-363
Q2, | 1 | DMG2302U | DMG2302U | Package_TO_SOT_SMD:SOT-23 | 4.2A Id, 20V Vds, N-Channel MOSFET, SOT-23
R1, R2, R3, R4, R5, R6, R7, R8, | 8 | 33 | R_Small | Resistor_SMD:R_0805_2012Metric | Resistor, small symbol
R9, R10, R11, R12, R13, R14, R15, R16, R25, R26, R28, R29, R30, R31, | 14 | 4.7k | R_Small | Resistor_SMD:R_0805_2012Metric | Resistor, small symbol
R17, R18, R19, R20, R21, R22, R23, R24, | 8 | 33 | R_Small |  | Resistor, small symbol
R27, | 1 | 10k | R_Small | Resistor_SMD:R_0805_2012Metric | Resistor, small symbol
R32, R33, R34, R35, R36, R37, R38, R39, | 8 | 4.7k | R_Small |  | Resistor, small symbol
SW1, | 1 | Enter BTN | SW_SPST | Button_Switch_THT:SW_PUSH_6mm | Single Pole Single Throw (SPST) switch
SW2, | 1 | Down BTN | SW_SPST | Button_Switch_THT:SW_PUSH_6mm | Single Pole Single Throw (SPST) switch
U1, | 1 | AT24C256C | CAT24C256 | Package_SO:SOIC-8_3.9x4.9mm_P1.27mm | 256 kb CMOS Serial EEPROM, DIP-8/SOIC-8/TSSOP-8/DFN-8
U2, | 1 | MP1584 | MP1584-MP1584 | DC-BRICK

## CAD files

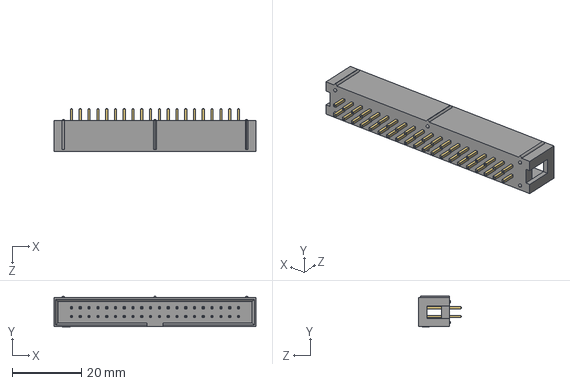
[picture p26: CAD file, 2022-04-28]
KiCAD/3D-Models/User Library-IDC Socket Male 40pin Straight THT Goldplated 2_54mm.STEP
58.4 x 8.85 x 12.4 mm

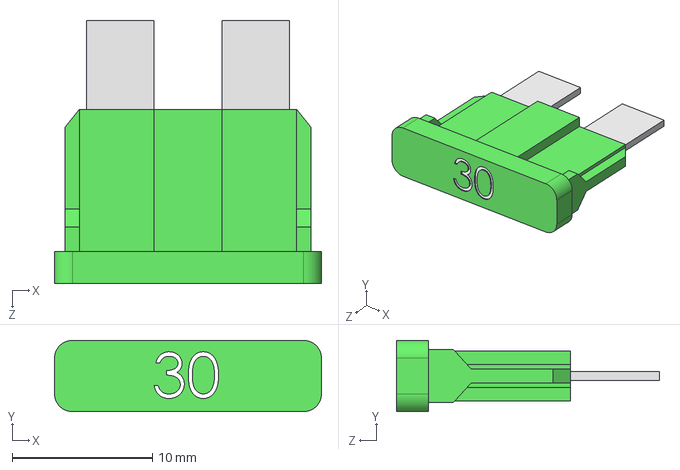
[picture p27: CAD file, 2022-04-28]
KiCAD/3D-Models/30A blade fuse.STEP
19.0 x 5.08 x 18.8 mm

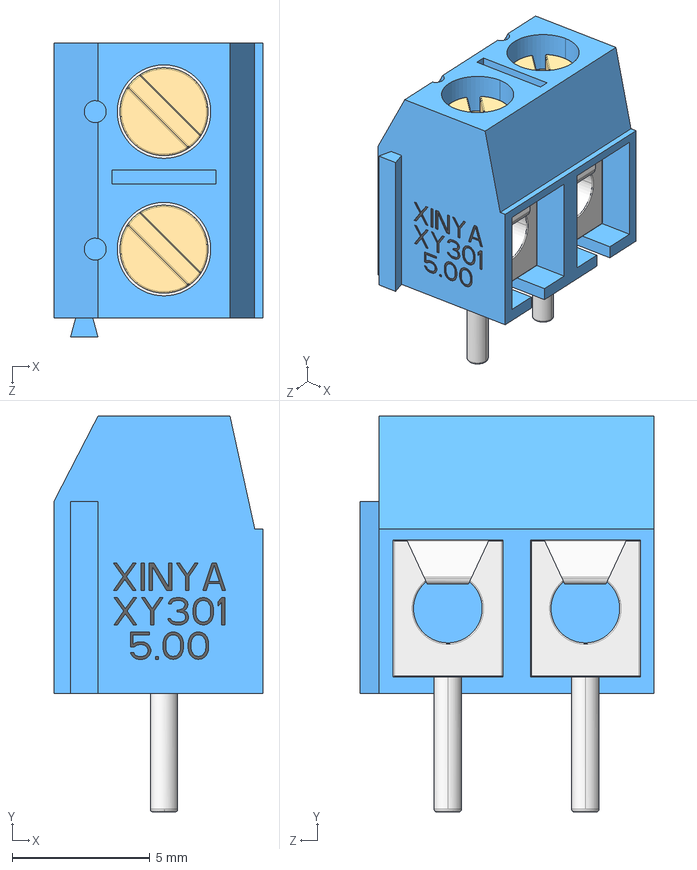
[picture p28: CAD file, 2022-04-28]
KiCAD/3D-Models/2P_P500MM_Terminal.STEP
7.60 x 14.4 x 10.7 mm
XY301A_5_CONTACT
XY301A_5_CONTACT_1
XY301A_5_KORPUS

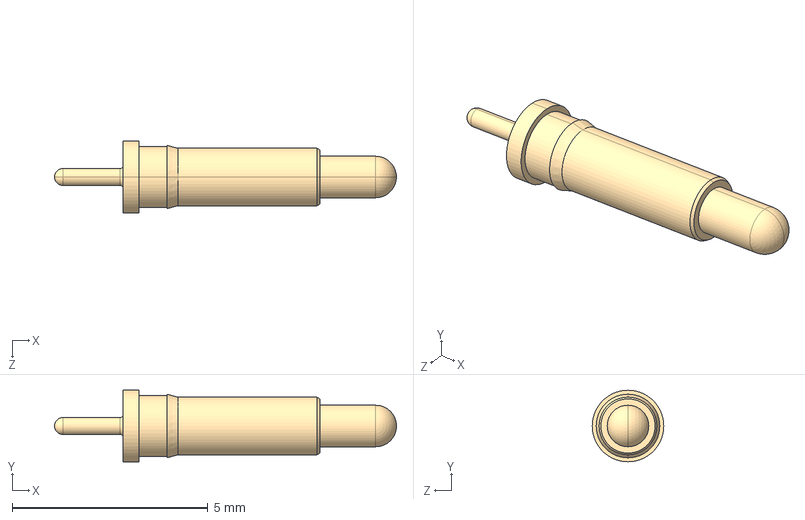
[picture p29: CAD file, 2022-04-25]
KiCAD/3D-Models/mill-max-0908-1-15-20-75-14-11-0.STEP
8.74 x 1.83 x 1.83 mm

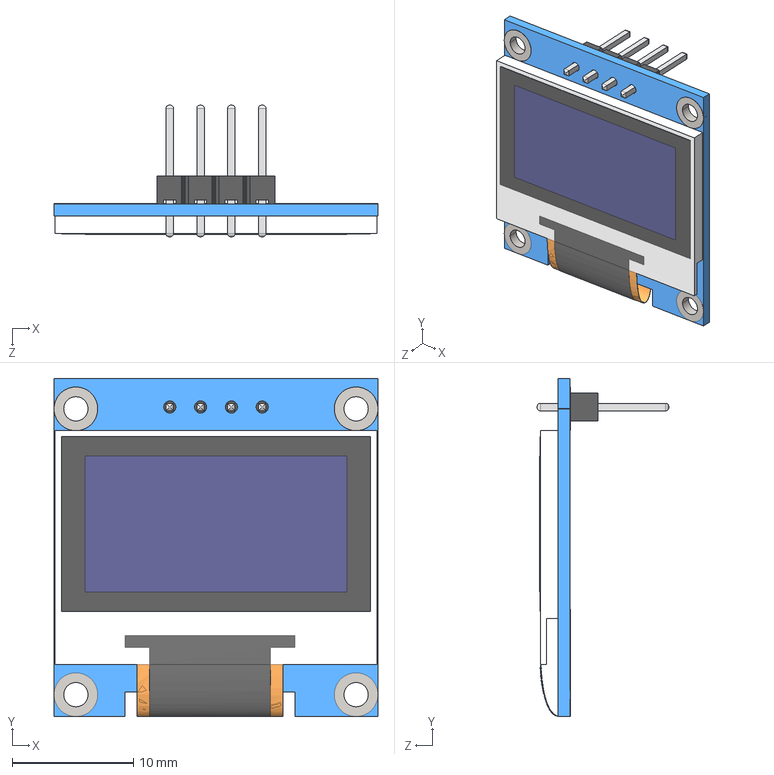
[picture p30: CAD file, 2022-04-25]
KiCAD/3D-Models/User Library-128x64I2COLEDDisplayAdafruit.STEP
26.7 x 27.9 x 10.8 mm

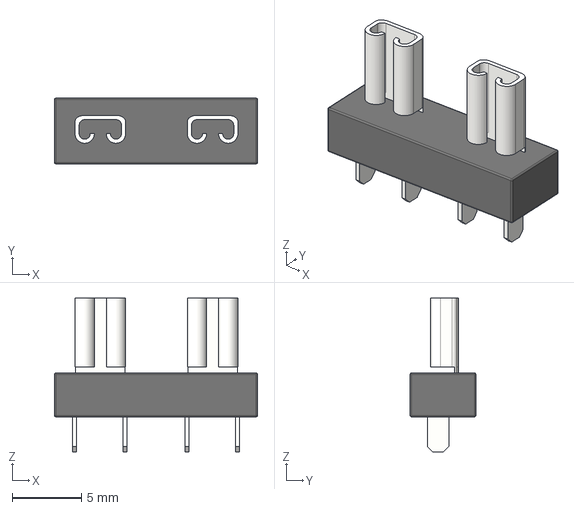
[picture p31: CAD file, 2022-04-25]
KiCAD/3D-Models/mini_balde_fuse_holder.step
14.7 x 4.75 x 11.1 mm
Pins

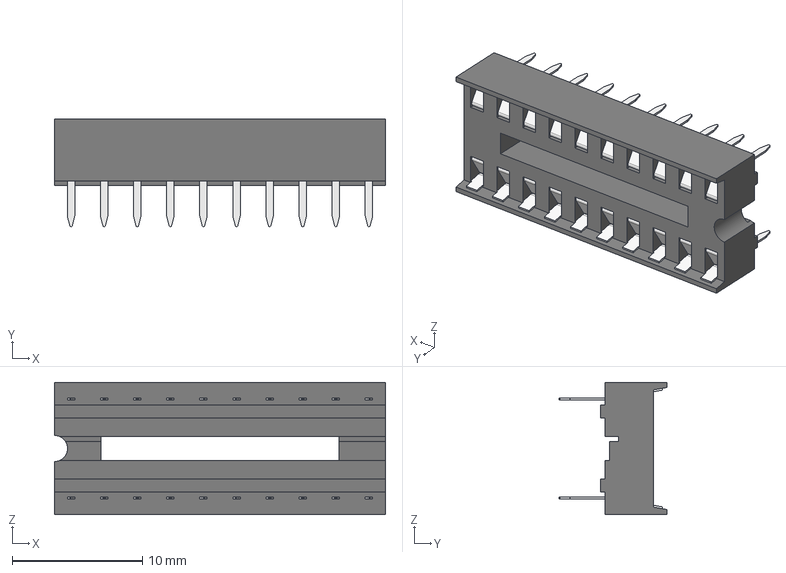
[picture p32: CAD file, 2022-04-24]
KiCAD/3D-Models/a_20-lc-tt.stp
25.4 x 8.25 x 10.2 mm

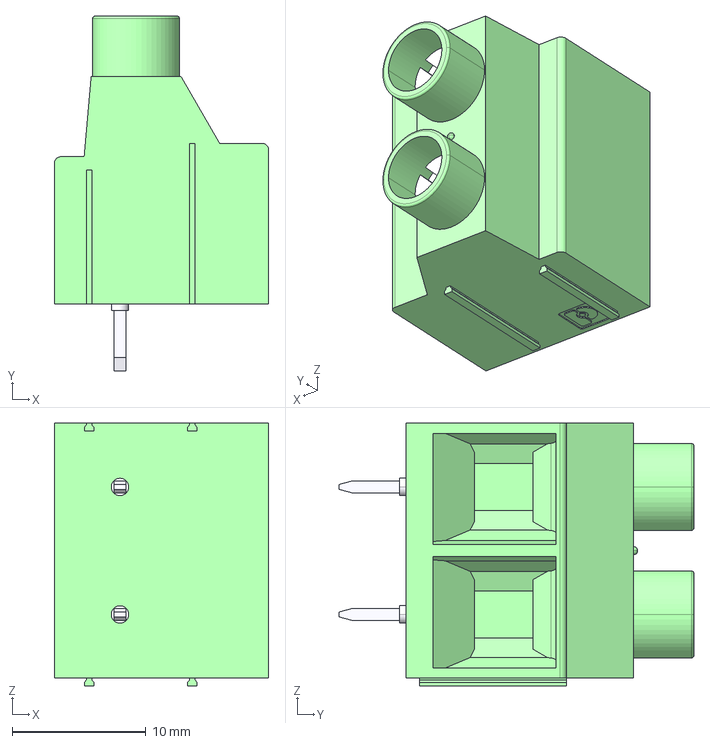
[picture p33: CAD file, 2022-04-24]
KiCAD/3D-Models/KF950_01_2P_P9.5.stp
16.0 x 26.5 x 19.6 mm

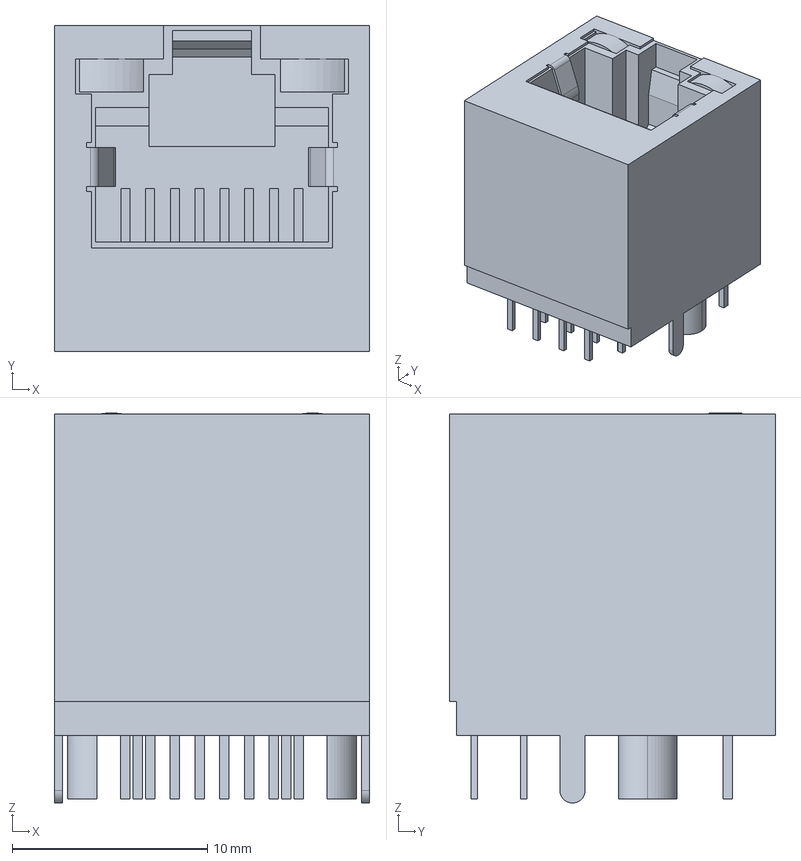
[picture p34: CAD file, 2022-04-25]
KiCAD/3D-Models/1734577-3.stp
16.1 x 16.7 x 20.0 mm

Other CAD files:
KiCAD/3D-Models/2A blade fuse.STEP
KiCAD/3D-Models/5A blade fuse.step
KiCAD/3D-Models/User Library-blade fuse - 1 to 40 a - 32 v.STEP

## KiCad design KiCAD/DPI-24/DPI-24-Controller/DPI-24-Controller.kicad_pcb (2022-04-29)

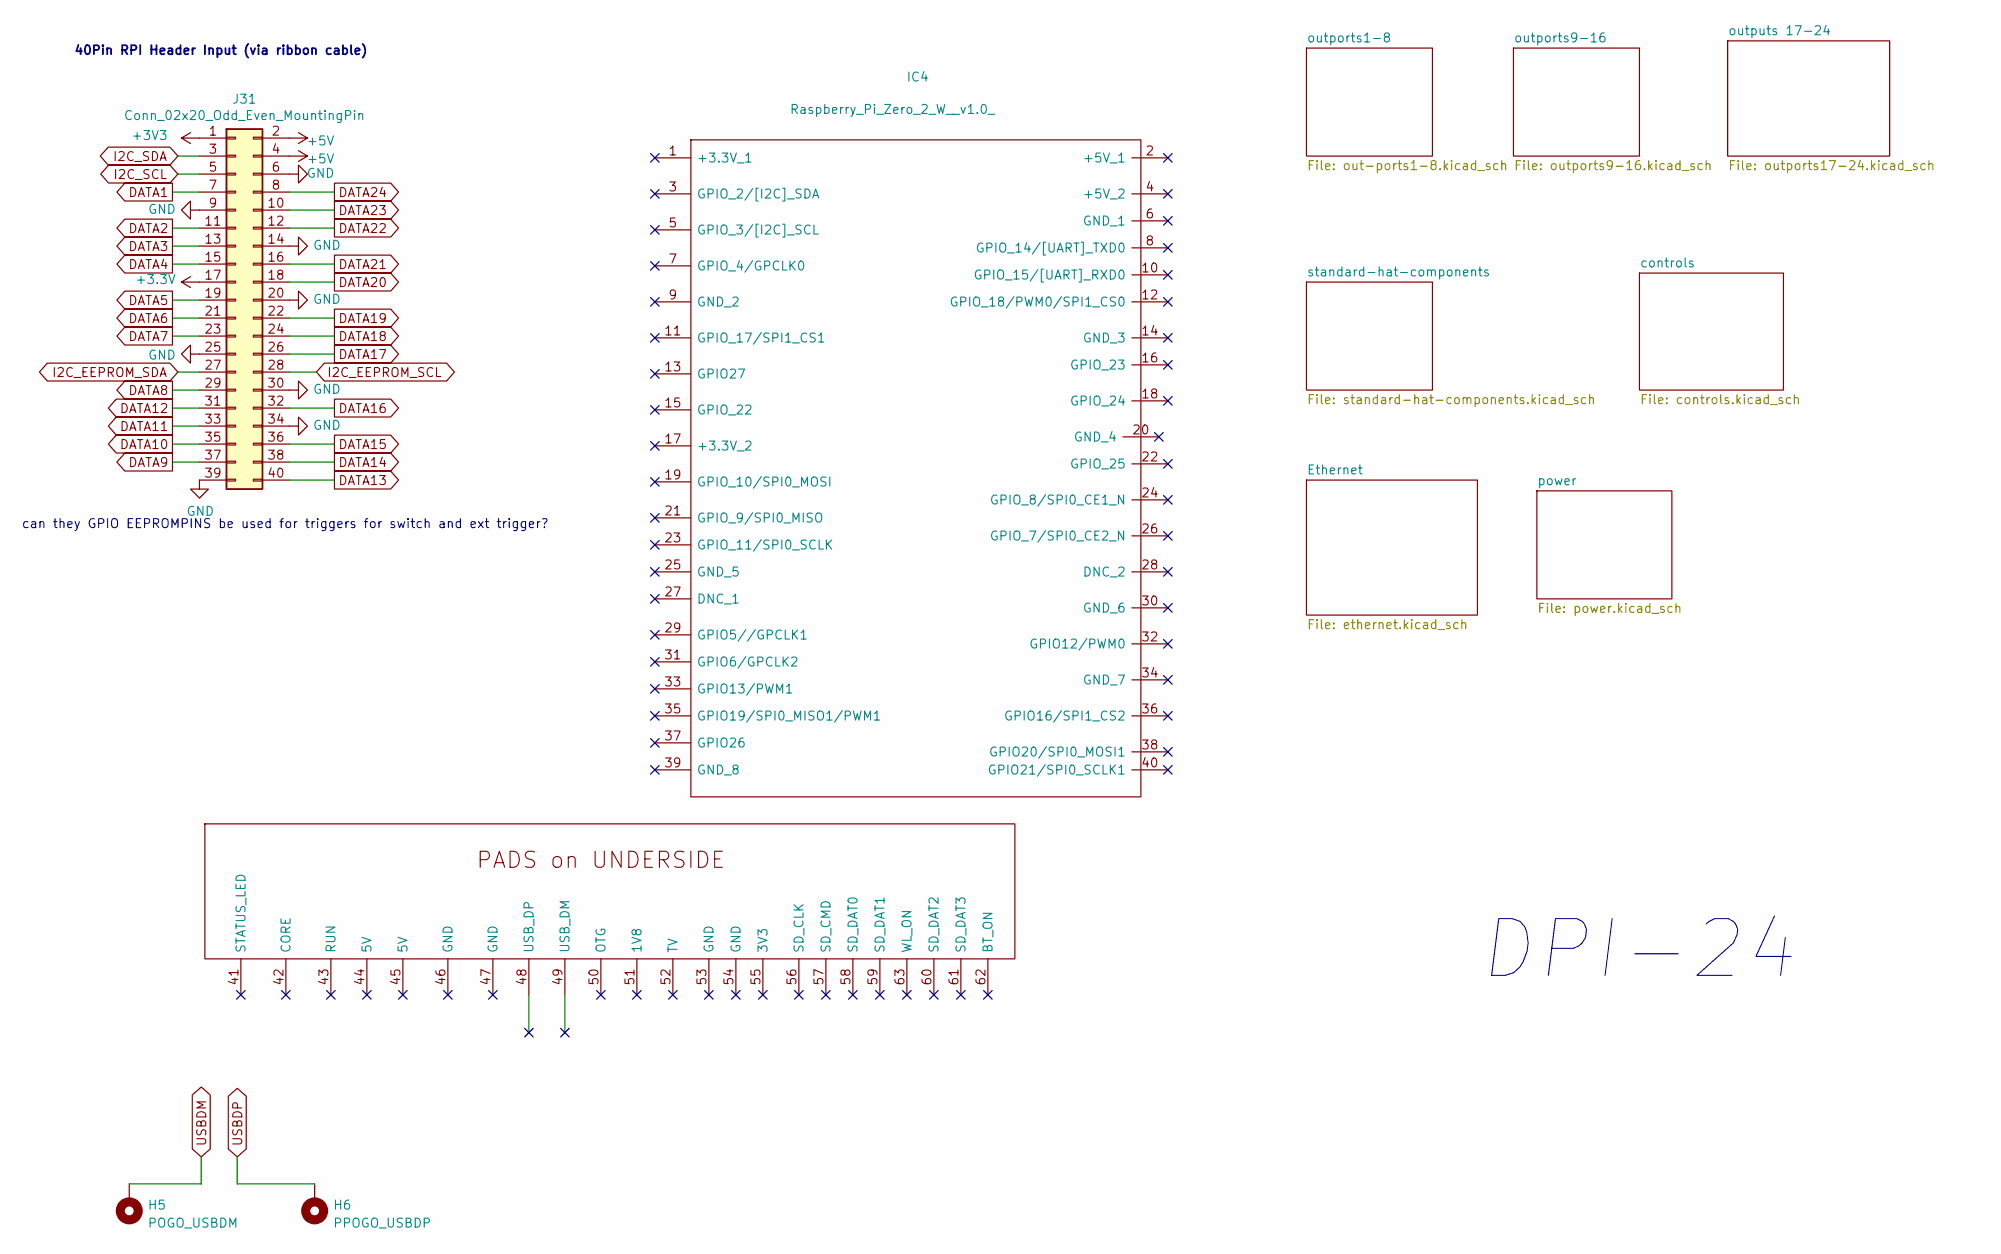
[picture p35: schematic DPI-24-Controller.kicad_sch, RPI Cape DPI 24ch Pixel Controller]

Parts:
H5: POGO_USBDM; POGO_D3.50mm_Drill0.9mm
H6: PPOGO_USBDP; POGO_D3.50mm_Drill0.9mm
IC4: Raspberry_Pi_Zero_2_W__v1.0_; RASPBERRYPIZERO2WV1; Manufacturer_Part_Number Raspberry Pi Zero 2 W (v1.0)
J31: Conn_02x20_Odd_Even_MountingPin; PinHeader_2x20_P2.54mm_Vertical

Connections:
DATA1: J31.7; also elsewhere on the board
DATA2: J31.11; also elsewhere on the board
DATA3: J31.13; also elsewhere on the board
DATA4: J31.15; also elsewhere on the board
DATA5: J31.19; also elsewhere on the board
DATA6: J31.21; also elsewhere on the board
DATA7: J31.23; also elsewhere on the board
DATA8: J31.29; also elsewhere on the board
DATA9: J31.37; also elsewhere on the board
DATA10: J31.35; also elsewhere on the board
DATA11: J31.33; also elsewhere on the board
DATA12: J31.31; also elsewhere on the board
DATA13: J31.40; also elsewhere on the board
DATA14: J31.38; also elsewhere on the board
DATA15: J31.36; also elsewhere on the board
DATA16: J31.32; also elsewhere on the board
DATA17: J31.26; also elsewhere on the board
DATA18: J31.24; also elsewhere on the board
DATA19: J31.22; also elsewhere on the board
DATA20: J31.18; also elsewhere on the board
DATA21: J31.16; also elsewhere on the board
DATA22: J31.12; also elsewhere on the board
DATA23: J31.10; also elsewhere on the board
DATA24: J31.8; also elsewhere on the board
I2C_EEPROM_SCL: J31.28; also elsewhere on the board
I2C_EEPROM_SDA: J31.27; also elsewhere on the board
I2C_SCL: J31.5; also elsewhere on the board
I2C_SDA: J31.3; also elsewhere on the board

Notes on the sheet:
can they GPIO EEPROMPINS be used for triggers for switch and ext trigger?
DPI-24
40Pin RPI Header Input (via ribbon cable)

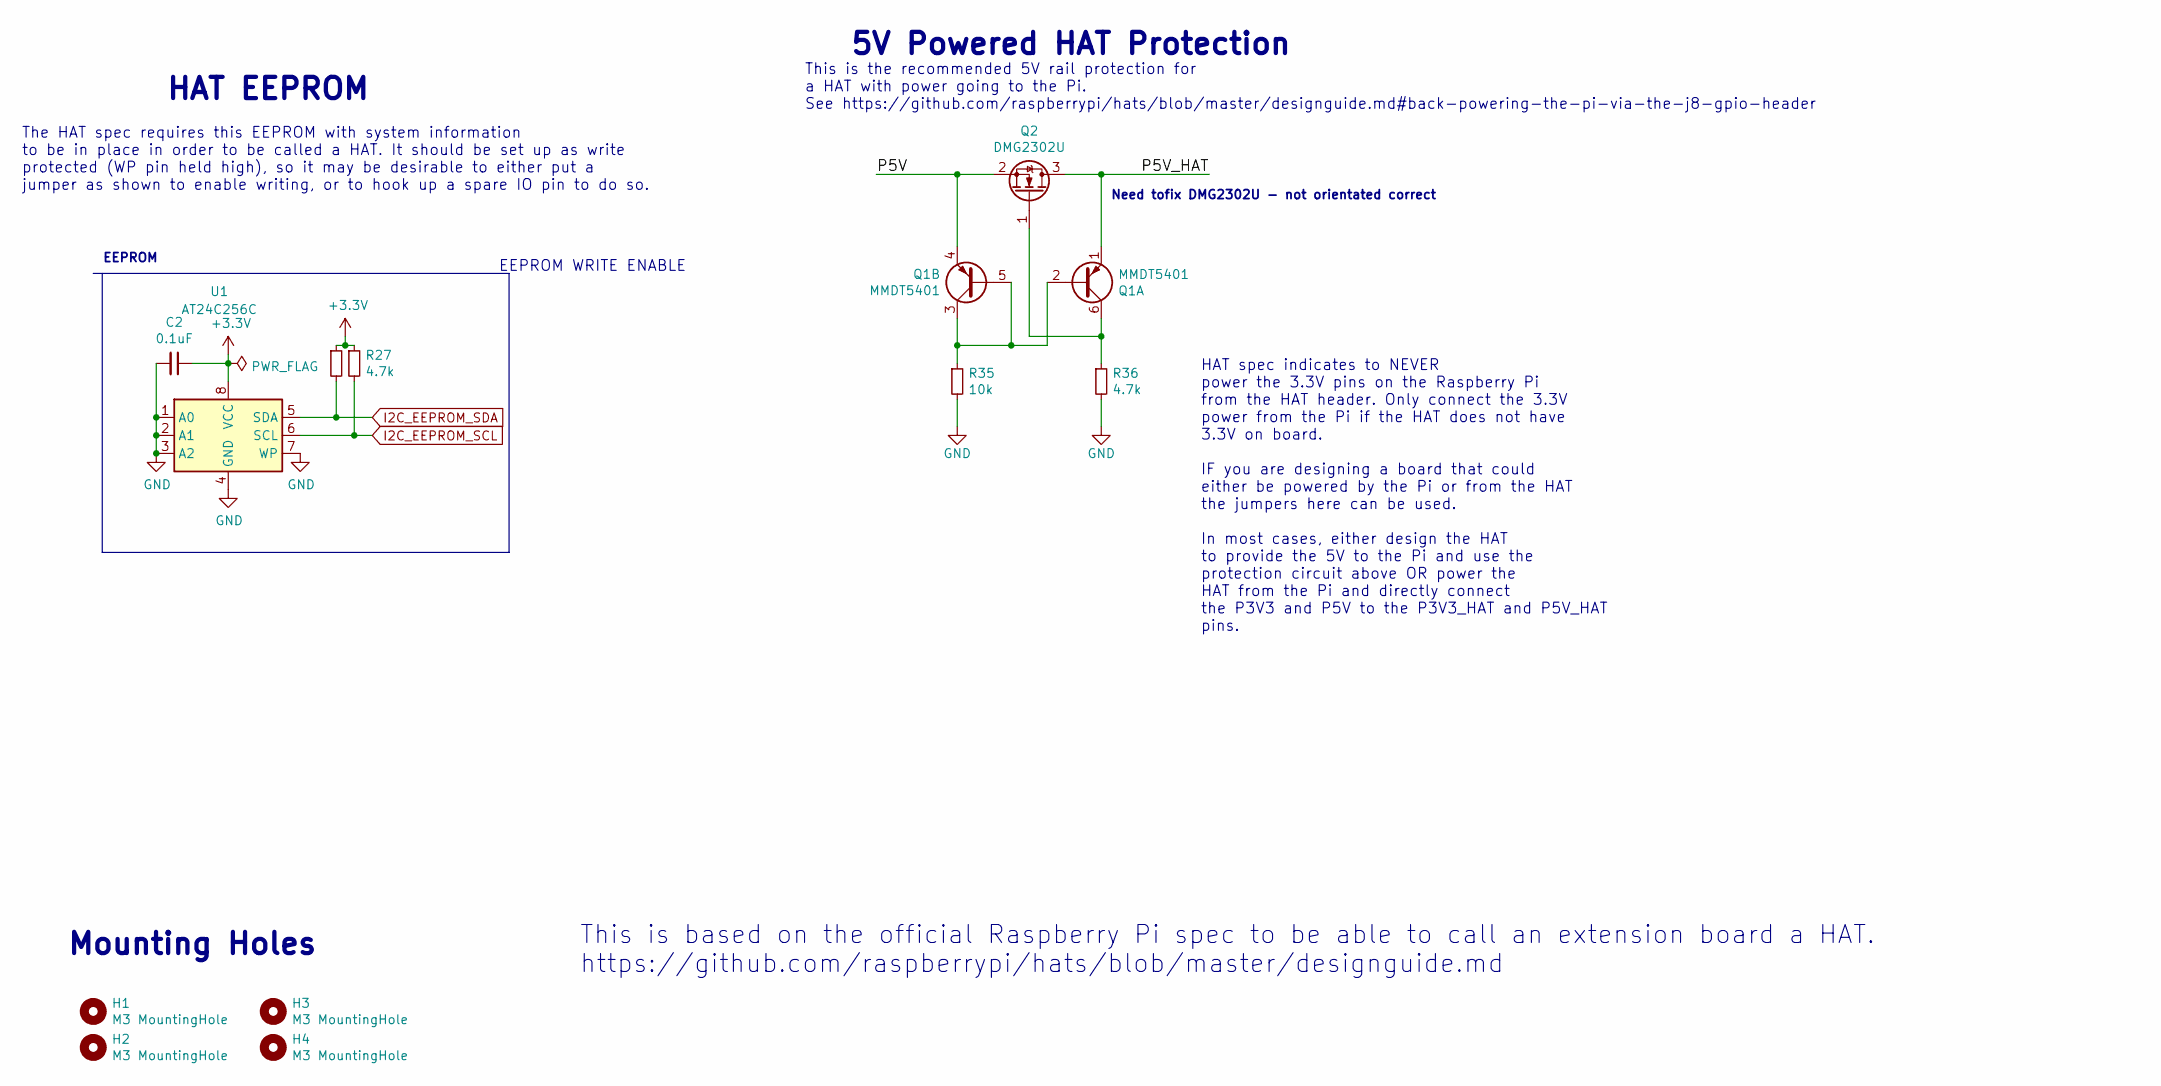
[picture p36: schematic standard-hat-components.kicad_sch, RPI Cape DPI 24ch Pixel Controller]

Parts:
C2: 0.1uF; C_Radial_D5.0mm_H11.0mm_P2.00mm
H1, H2, H3, H4: M3 MountingHole; MountingHole_3.2mm_M3_Pad_TopBottom
Q1: MMDT5401; SOT-363_SC-70-6
Q2: DMG2302U; SOT-23
R25, R27, R36: 4.7k; R_0805_2012Metric
R35: 10k; R_0805_2012Metric
U1: AT24C256C; DIP-8_W7.62mm_Socket

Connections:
/standard-hat-components/P5V: Q1.4 (E2), Q2.2 (S)
/standard-hat-components/P5V_HAT: Q1.1 (E1), Q2.3 (D)
I2C_EEPROM_SCL: R27.2, U1.6 (SCL); also elsewhere on the board
I2C_EEPROM_SDA: R25.2, U1.5 (SDA); also elsewhere on the board
unnamed: Q1.2 (B1), Q1.3 (C2), Q1.5 (B2), R35.1
unnamed: Q1.6 (C1), Q2.1 (G), R36.1

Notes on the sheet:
5V Powered HAT Protection
This is based on the official Raspberry Pi spec to be able to call an extension board a HAT. https://github.com/raspberrypi/hats/blob/master/designguide.md
Mounting Holes
EEPROM
HAT spec indicates to NEVER power the 3.3V pins on the Raspberry Pi from the HAT header. Only connect the 3.3V power from the Pi if the HAT does not have 3.3V on board. IF you are designing a board that could either be powered by the Pi or from the HAT the jumpers here can be used. In most cases, e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
HAT EEPROM
EEPROM WRITE ENABLE
Need tofix DMG2302U - not orientated correct
The HAT spec requires this EEPROM with system information to be in place in order to be called a HAT. It should be set up as write protected (WP pin held high), so it may be desirable to either put a jumper as shown to enable writing, or to hook up a spare IO pin to do so.
This is the recommended 5V rail protection for a HAT with power going to the Pi. See https://github.com/raspberrypi/hats/blob/master/designguide.md#back-powering-the-pi-via-the-j8-gpio-header

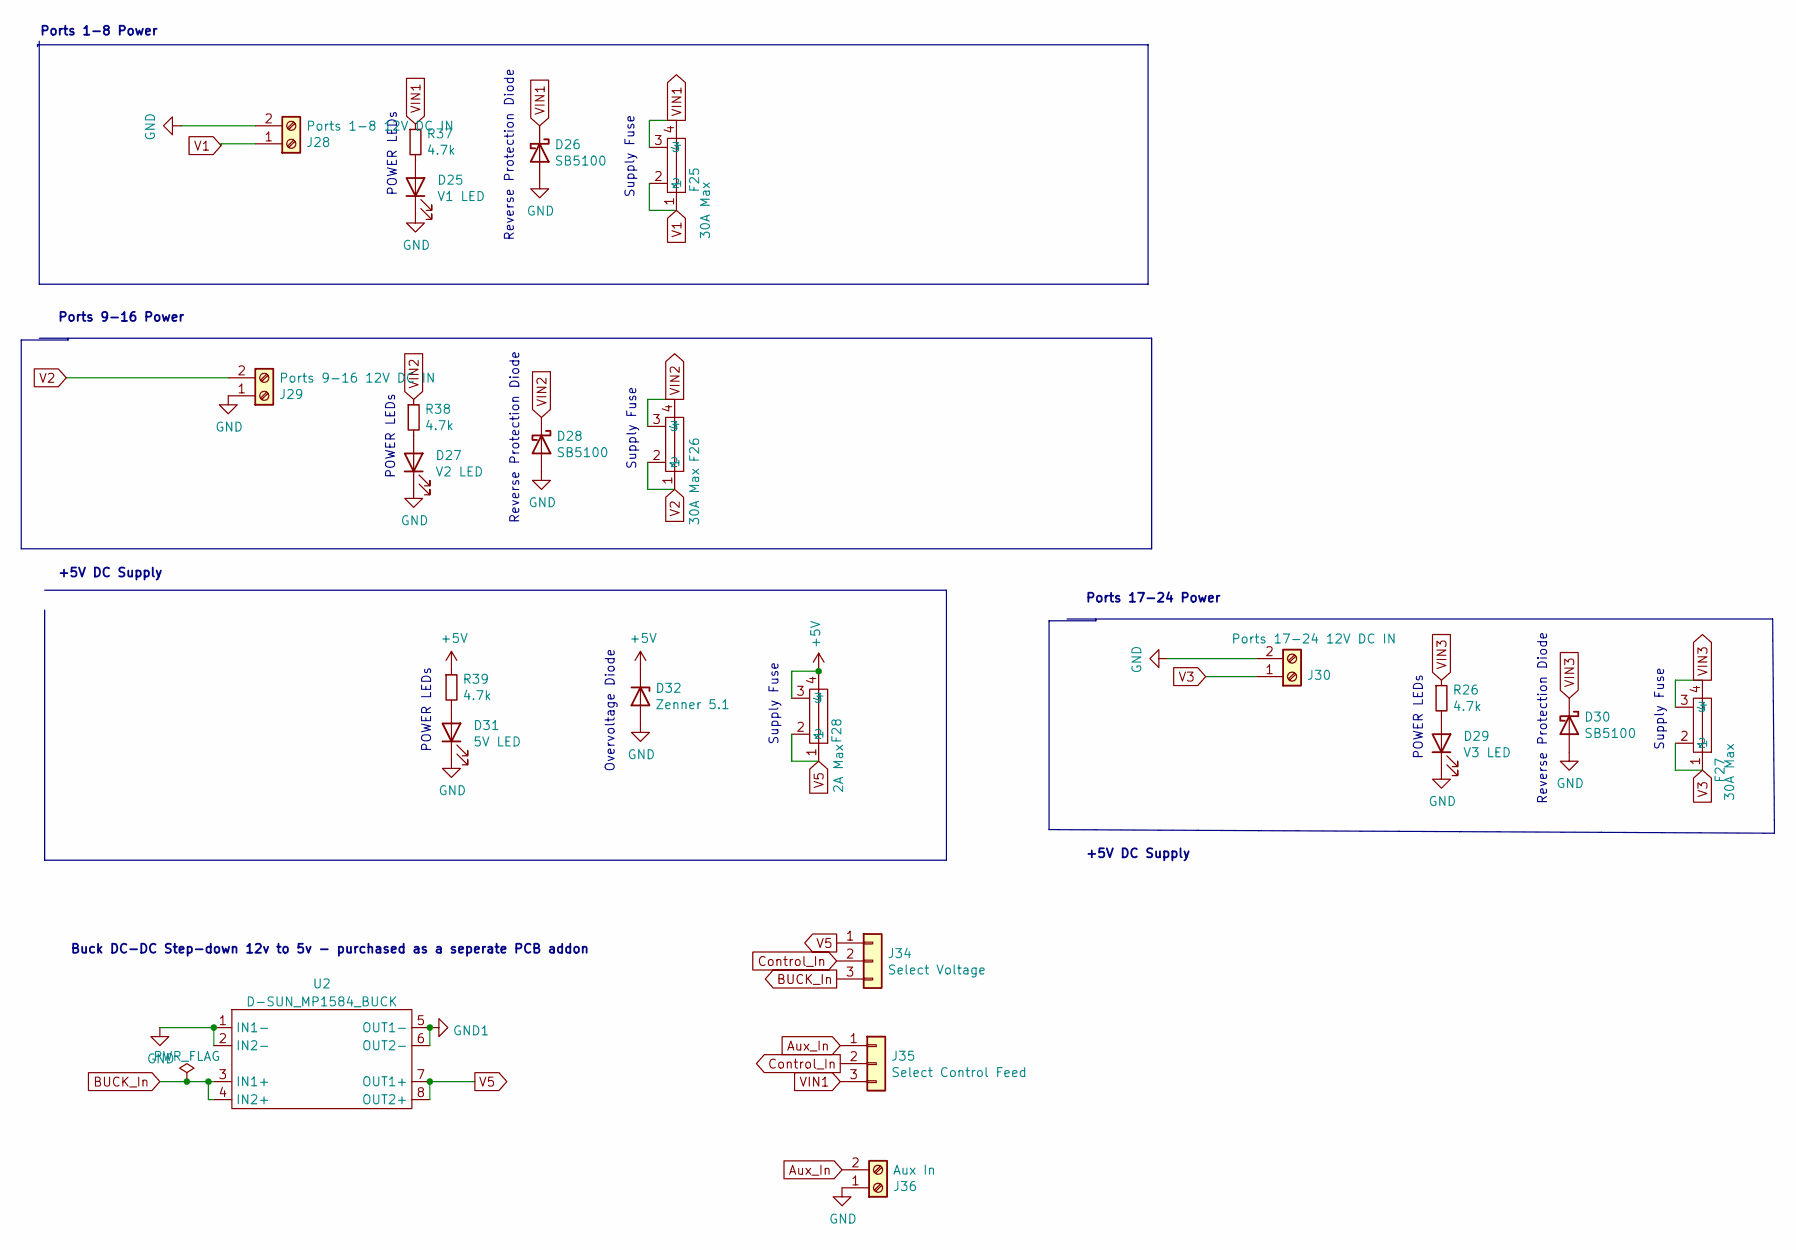
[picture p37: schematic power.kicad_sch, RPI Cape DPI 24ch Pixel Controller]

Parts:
D25: V1 LED; LED_0603_1608Metric
D26, D28, D30: SB5100; D_DO-201AD_P12.70mm_Horizontal
D27: V2 LED; LED_0603_1608Metric
D29: V3 LED; LED_0603_1608Metric
D31: 5V LED; LED_0603_1608Metric
D32: Zenner 5.1; D_5W_P10.16mm_Horizontal
F25, F26, F27: 30A Max; Medium Auto Fuse Holder
F28: 2A Max; Medium Auto Fuse Holder
J28: Ports 1-8 12V DC IN; TerminalBlock_KF950_1x02_P9.50mm_Horizontal
J29: Ports 9-16 12V DC IN; TerminalBlock_KF950_1x02_P9.50mm_Horizontal
J30: Ports 17-24 12V DC IN; TerminalBlock_KF950_1x02_P9.50mm_Horizontal
J34: Select Voltage; PinHeader_1x03_P2.54mm_Vertical
J35: Select Control Feed; PinHeader_1x03_P2.54mm_Vertical
J36: Aux In; TerminalBlock_RND_205-00012_1x02_P5.00mm_Horizontal
R26, R37, R38, R39: 4.7k; R_0805_2012Metric
U2: D-SUN_MP1584_BUCK

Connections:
Aux_In: J35.1, J36.2
BUCK_In: J34.3, U2.3 (IN1+), U2.4 (IN2+)
Control_In: J34.2, J35.2
GND1: U2.5 (OUT1-), U2.6 (OUT2-)
unnamed: D25.2 (A), R37.2
unnamed: D27.2 (A), R38.2
unnamed: D29.2 (A), R26.2
unnamed: D31.2 (A), R39.2
V1: F25.1, F25.2, J28.1
V2: F26.1, F26.2, J29.2
V3: F27.1, F27.2, J30.1
V5: F28.1, F28.2, J34.1, U2.7 (OUT1+), U2.8 (OUT2+)
VIN1: D26.1 (K), F25.3, F25.4, J35.3, R37.1; also elsewhere on the board
VIN2: D28.1 (K), F26.3, F26.4, R38.1; also elsewhere on the board
VIN3: D30.1 (K), F27.3, F27.4, R26.1; also elsewhere on the board

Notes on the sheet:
POWER LEDs
+5V DC Supply
Reverse Protection Diode
Supply Fuse
Ports 9-16 Power
Buck DC-DC Step-down 12v to 5v - purchased as a seperate PCB addon
Ports 17-24 Power
Ports 1-8 Power
Overvoltage Diode

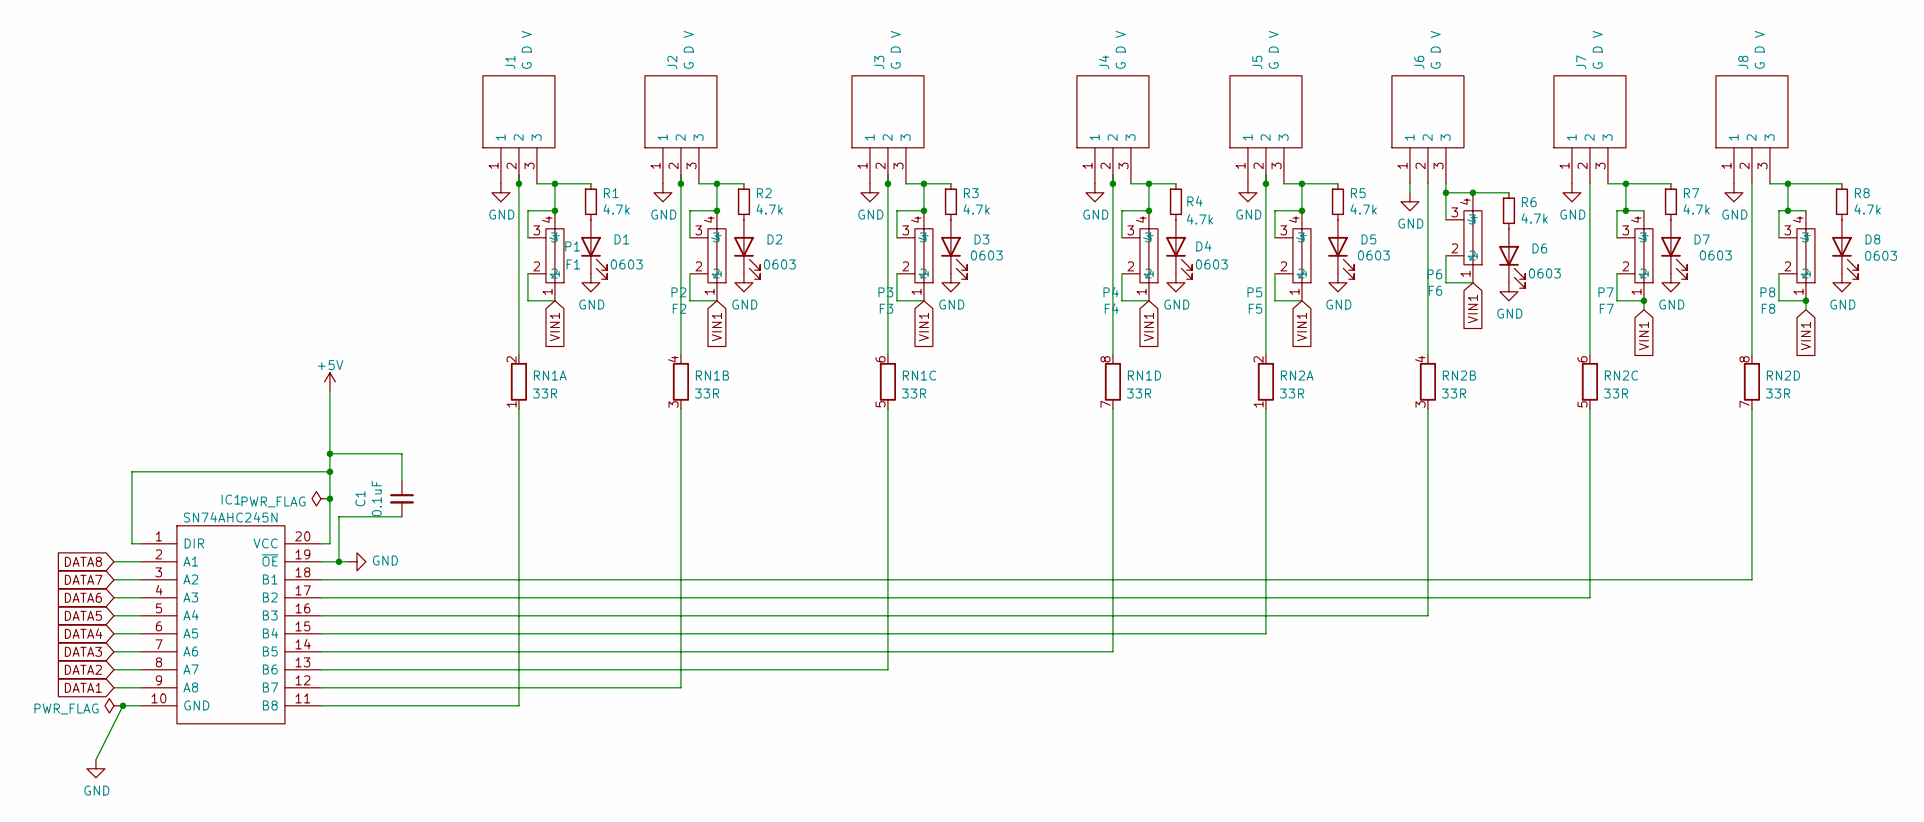
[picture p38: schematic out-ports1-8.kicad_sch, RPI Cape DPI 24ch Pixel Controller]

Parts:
C1: 0.1uF; C_Radial_D5.0mm_H11.0mm_P2.00mm
D1, D2, D3, D4, D5, D6, D7, D8: 0603; LED_0603_1608Metric
F1: P1; Medium Auto Fuse Holder
F2: P2; Medium Auto Fuse Holder
F3: P3; Medium Auto Fuse Holder
F4: P4; Medium Auto Fuse Holder
F5: P5; Medium Auto Fuse Holder
F6: P6; Medium Auto Fuse Holder
F7: P7; Medium Auto Fuse Holder
F8: P8; Medium Auto Fuse Holder
IC1: SN74AHC245N; DIP794W53P254L2540H508Q20N; Mouser Part Number 595-SN74AHC245N
J1, J2, J3, J4, J5, J6, J7, J8: G D V; PhoenixContact_MCV_1,5_3-G-3.5_1x03_P3.50mm_Vertical; Mouser Part Number 571-284514-3
R1, R2, R3, R4, R5, R6, R7, R8: 4.7k; R_0805_2012Metric
RN1, RN2: 33R; R_Array_SIP8

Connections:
DATA1: IC1.9 (A8); also elsewhere on the board
DATA2: IC1.8 (A7); also elsewhere on the board
DATA3: IC1.7 (A6); also elsewhere on the board
DATA4: IC1.6 (A5); also elsewhere on the board
DATA5: IC1.5 (A4); also elsewhere on the board
DATA6: IC1.4 (A3); also elsewhere on the board
DATA7: IC1.3 (A2); also elsewhere on the board
DATA8: IC1.2 (A1); also elsewhere on the board
unnamed: D1.2 (A), R1.2
unnamed: D2.2 (A), R2.2
unnamed: D3.2 (A), R3.2
unnamed: D4.2 (A), R4.2
unnamed: D5.2 (A), R5.2
unnamed: D6.2 (A), R6.2
unnamed: D7.2 (A), R7.2
unnamed: D8.2 (A), R8.2
unnamed: F1.3, F1.4, J1.3, R1.1
unnamed: F2.3, F2.4, J2.3, R2.1
unnamed: F3.3, F3.4, J3.3, R3.1
unnamed: F4.3, F4.4, J4.3, R4.1
unnamed: F5.3, F5.4, J5.3, R5.1
unnamed: F6.3, F6.4, J6.3, R6.1
unnamed: F7.3, F7.4, J7.3, R7.1
unnamed: F8.3, F8.4, J8.3, R8.1
unnamed: IC1.11 (B8), RN1.1 (R1.1)
unnamed: IC1.12 (B7), RN1.3 (R2.1)
unnamed: IC1.13 (B6), RN1.5 (R3.1)
unnamed: IC1.14 (B5), RN1.7 (R4.1)
unnamed: IC1.15 (B4), RN2.1 (R1.1)
unnamed: IC1.16 (B3), RN2.3 (R2.1)
unnamed: IC1.17 (B2), RN2.5 (R3.1)
unnamed: IC1.18 (B1), RN2.7 (R4.1)
unnamed: J1.2, RN1.2 (R1.2)
unnamed: J2.2, RN1.4 (R2.2)
unnamed: J3.2, RN1.6 (R3.2)
unnamed: J4.2, RN1.8 (R4.2)
unnamed: J5.2, RN2.2 (R1.2)
unnamed: J6.2, RN2.4 (R2.2)
unnamed: J7.2, RN2.6 (R3.2)
unnamed: J8.2, RN2.8 (R4.2)
VIN1: F1.1, F1.2, F2.1, F2.2, F3.1, F3.2, F4.1, F4.2, F5.1, F5.2, F6.1, F6.2, F7.1, F7.2, F8.1, F8.2; also elsewhere on the board

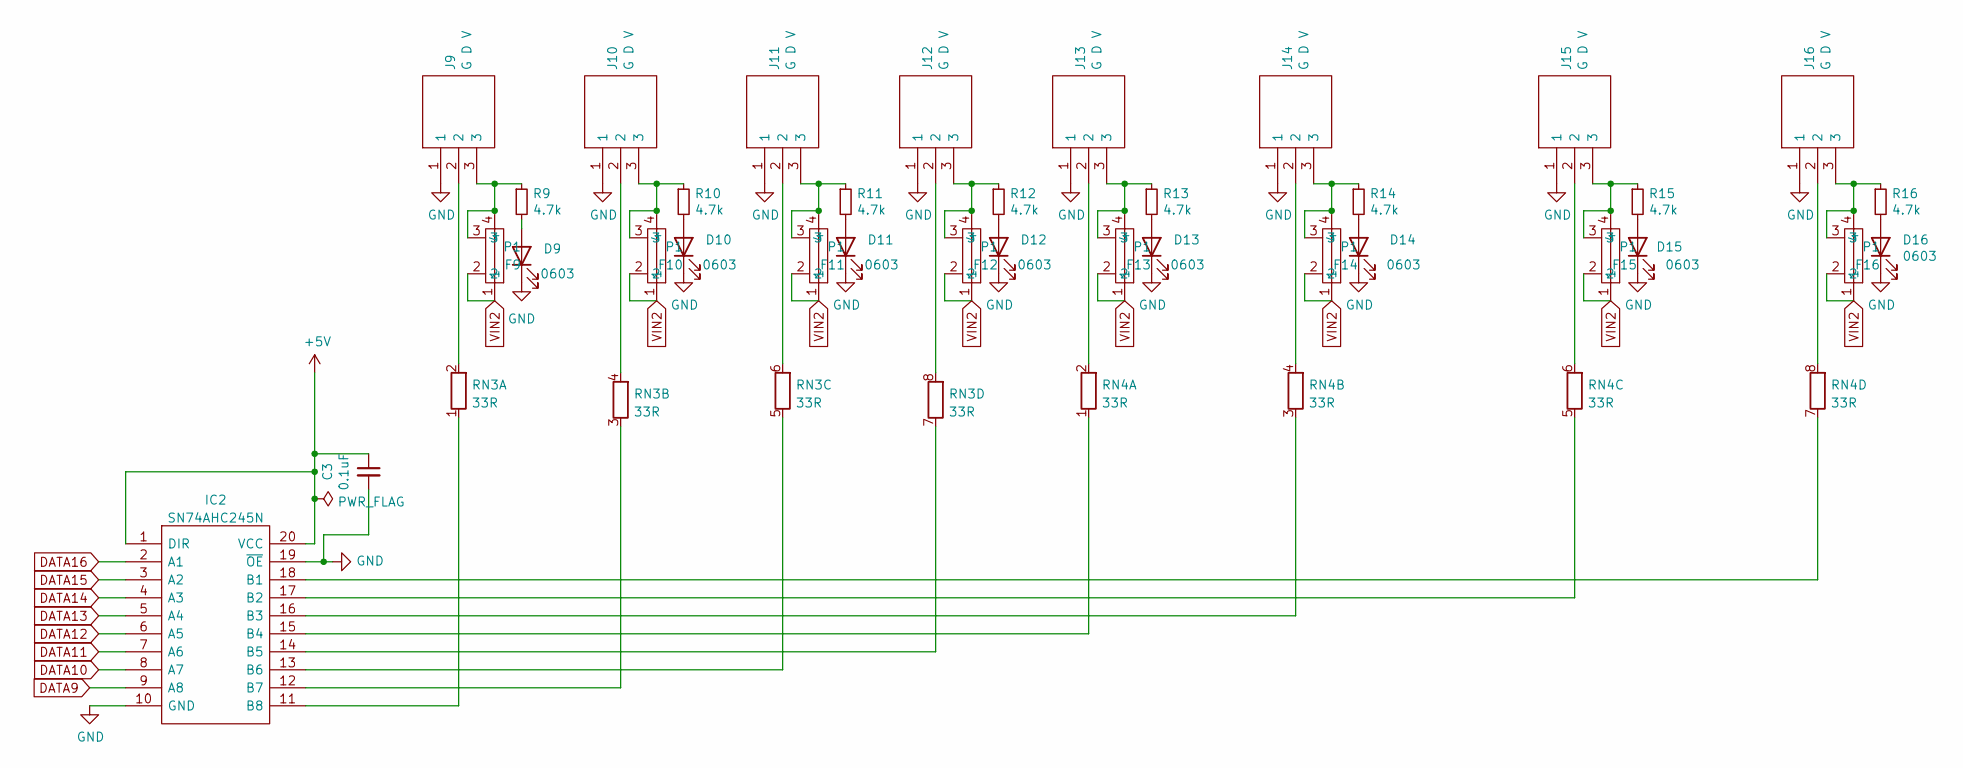
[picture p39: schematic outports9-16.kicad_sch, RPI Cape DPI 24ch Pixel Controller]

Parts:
C3: 0.1uF; C_Radial_D5.0mm_H11.0mm_P2.00mm
D9, D10, D11, D12, D13, D14, D15, D16: 0603; LED_0603_1608Metric
F9, F10, F11, F12, F13, F14, F15, F16: P1; Medium Auto Fuse Holder
IC2: SN74AHC245N; DIP794W53P254L2540H508Q20N; Mouser Part Number 595-SN74AHC245N
J9, J10, J11, J12, J13, J14, J15, J16: G D V; PhoenixContact_MCV_1,5_3-G-3.5_1x03_P3.50mm_Vertical; Mouser Part Number 571-284514-3
R9, R10, R11, R12, R13, R14, R15, R16: 4.7k; R_0805_2012Metric
RN3, RN4: 33R; R_Array_SIP8

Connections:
DATA9: IC2.9 (A8); also elsewhere on the board
DATA10: IC2.8 (A7); also elsewhere on the board
DATA11: IC2.7 (A6); also elsewhere on the board
DATA12: IC2.6 (A5); also elsewhere on the board
DATA13: IC2.5 (A4); also elsewhere on the board
DATA14: IC2.4 (A3); also elsewhere on the board
DATA15: IC2.3 (A2); also elsewhere on the board
DATA16: IC2.2 (A1); also elsewhere on the board
unnamed: D9.2 (A), R9.2
unnamed: D10.2 (A), R10.2
unnamed: D11.2 (A), R11.2
unnamed: D12.2 (A), R12.2
unnamed: D13.2 (A), R13.2
unnamed: D14.2 (A), R14.2
unnamed: D15.2 (A), R15.2
unnamed: D16.2 (A), R16.2
unnamed: F9.3, F9.4, J9.3, R9.1
unnamed: F10.3, F10.4, J10.3, R10.1
unnamed: F11.3, F11.4, J11.3, R11.1
unnamed: F12.3, F12.4, J12.3, R12.1
unnamed: F13.3, F13.4, J13.3, R13.1
unnamed: F14.3, F14.4, J14.3, R14.1
unnamed: F15.3, F15.4, J15.3, R15.1
unnamed: F16.3, F16.4, J16.3, R16.1
unnamed: IC2.11 (B8), RN3.1 (R1.1)
unnamed: IC2.12 (B7), RN3.3 (R2.1)
unnamed: IC2.13 (B6), RN3.5 (R3.1)
unnamed: IC2.14 (B5), RN3.7 (R4.1)
unnamed: IC2.15 (B4), RN4.1 (R1.1)
unnamed: IC2.16 (B3), RN4.3 (R2.1)
unnamed: IC2.17 (B2), RN4.5 (R3.1)
unnamed: IC2.18 (B1), RN4.7 (R4.1)
unnamed: J9.2, RN3.2 (R1.2)
unnamed: J10.2, RN3.4 (R2.2)
unnamed: J11.2, RN3.6 (R3.2)
unnamed: J12.2, RN3.8 (R4.2)
unnamed: J13.2, RN4.2 (R1.2)
unnamed: J14.2, RN4.4 (R2.2)
unnamed: J15.2, RN4.6 (R3.2)
unnamed: J16.2, RN4.8 (R4.2)
VIN2: F9.1, F9.2, F10.1, F10.2, F11.1, F11.2, F12.1, F12.2, F13.1, F13.2, F14.1, F14.2, F15.1, F15.2, F16.1, F16.2; also elsewhere on the board

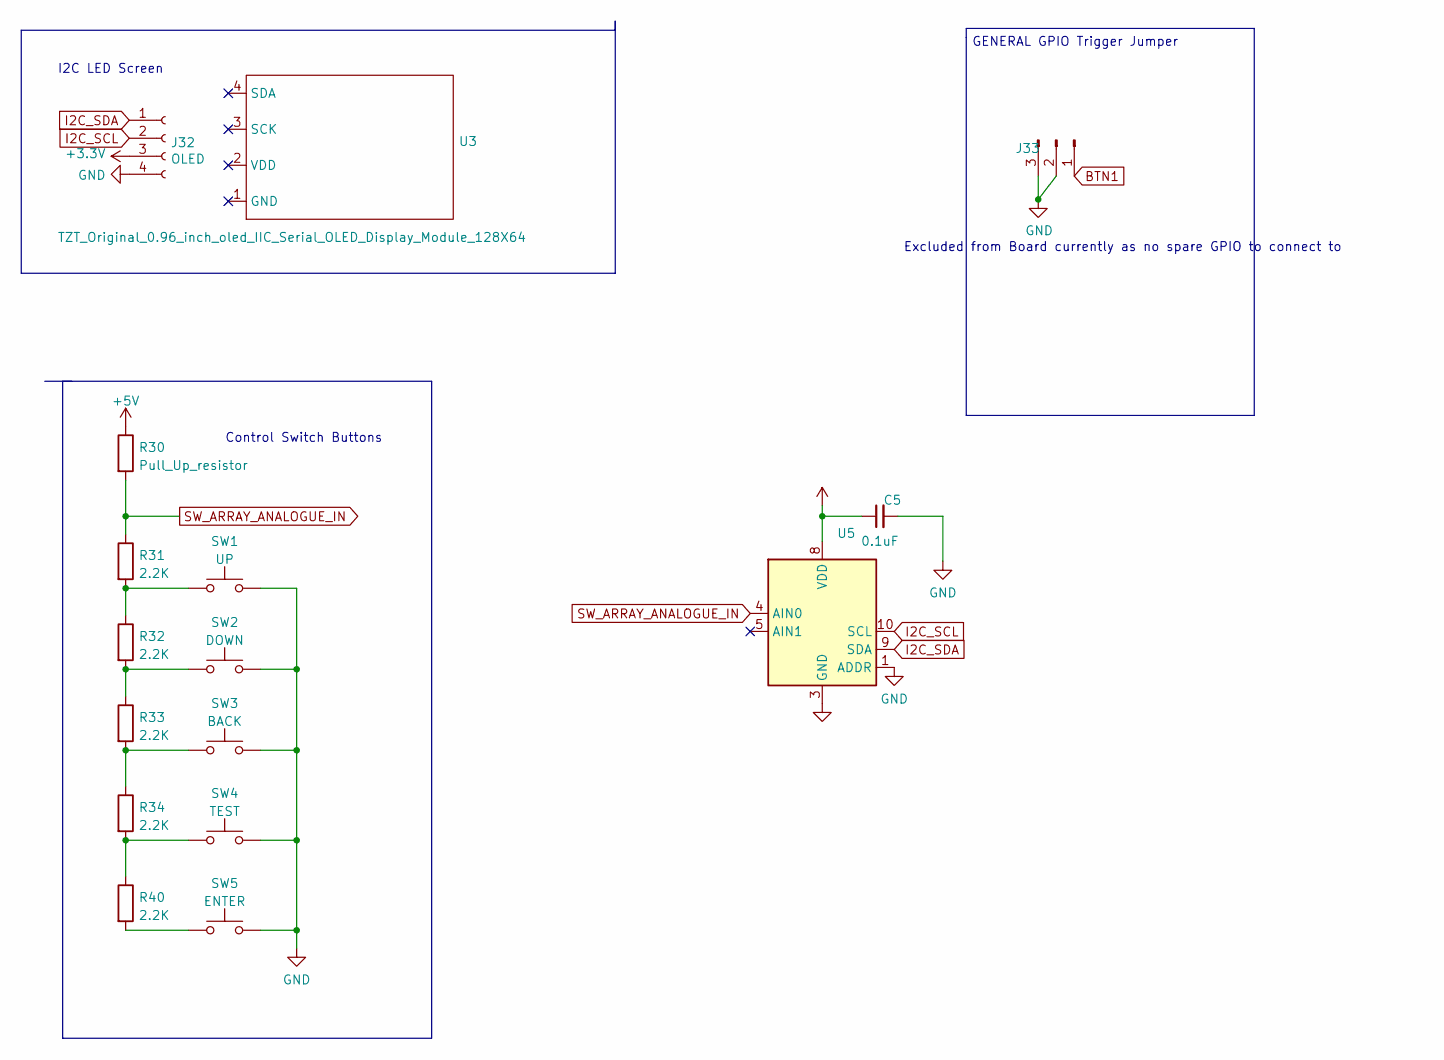
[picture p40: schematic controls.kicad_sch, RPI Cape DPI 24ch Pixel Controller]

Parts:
C5: 0.1uF; C_Radial_D5.0mm_H11.0mm_P2.00mm
J32: OLED; PinSocket_1x04_P2.54mm_Vertical
J33: (no value)
R30: Pull_Up_resistor; R_0805_2012Metric
R31, R32, R33, R34, R40: 2.2K; R_0805_2012Metric
SW1: UP; SW_PUSH_6mm
SW2: DOWN; SW_PUSH_6mm
SW3: BACK; SW_PUSH_6mm
SW4: TEST; SW_PUSH_6mm
SW5: ENTER; SW_PUSH_6mm
U3: TZT_Original_0.96_inch_oled_IIC_Serial_OLED_Displ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; TZT_0.96inch_OLED
U5: (no value)

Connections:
I2C_SCL: J32.2, U5.10 (SCL); also elsewhere on the board
I2C_SDA: J32.1, U5.9 (SDA); also elsewhere on the board
unnamed: R31.2, R32.1, SW1.1
unnamed: R32.2, R33.1, SW2.1
unnamed: R33.2, R34.1, SW3.1
unnamed: R34.2, R40.1, SW4.1
unnamed: R40.2, SW5.1
SW_ARRAY_ANALOGUE_IN: R30.2, R31.1, U5.4 (AIN0)

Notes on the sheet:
Excluded from Board currently as no spare GPIO to connect to
GENERAL GPIO Trigger Jumper
I2C LED Screen
Control Switch Buttons

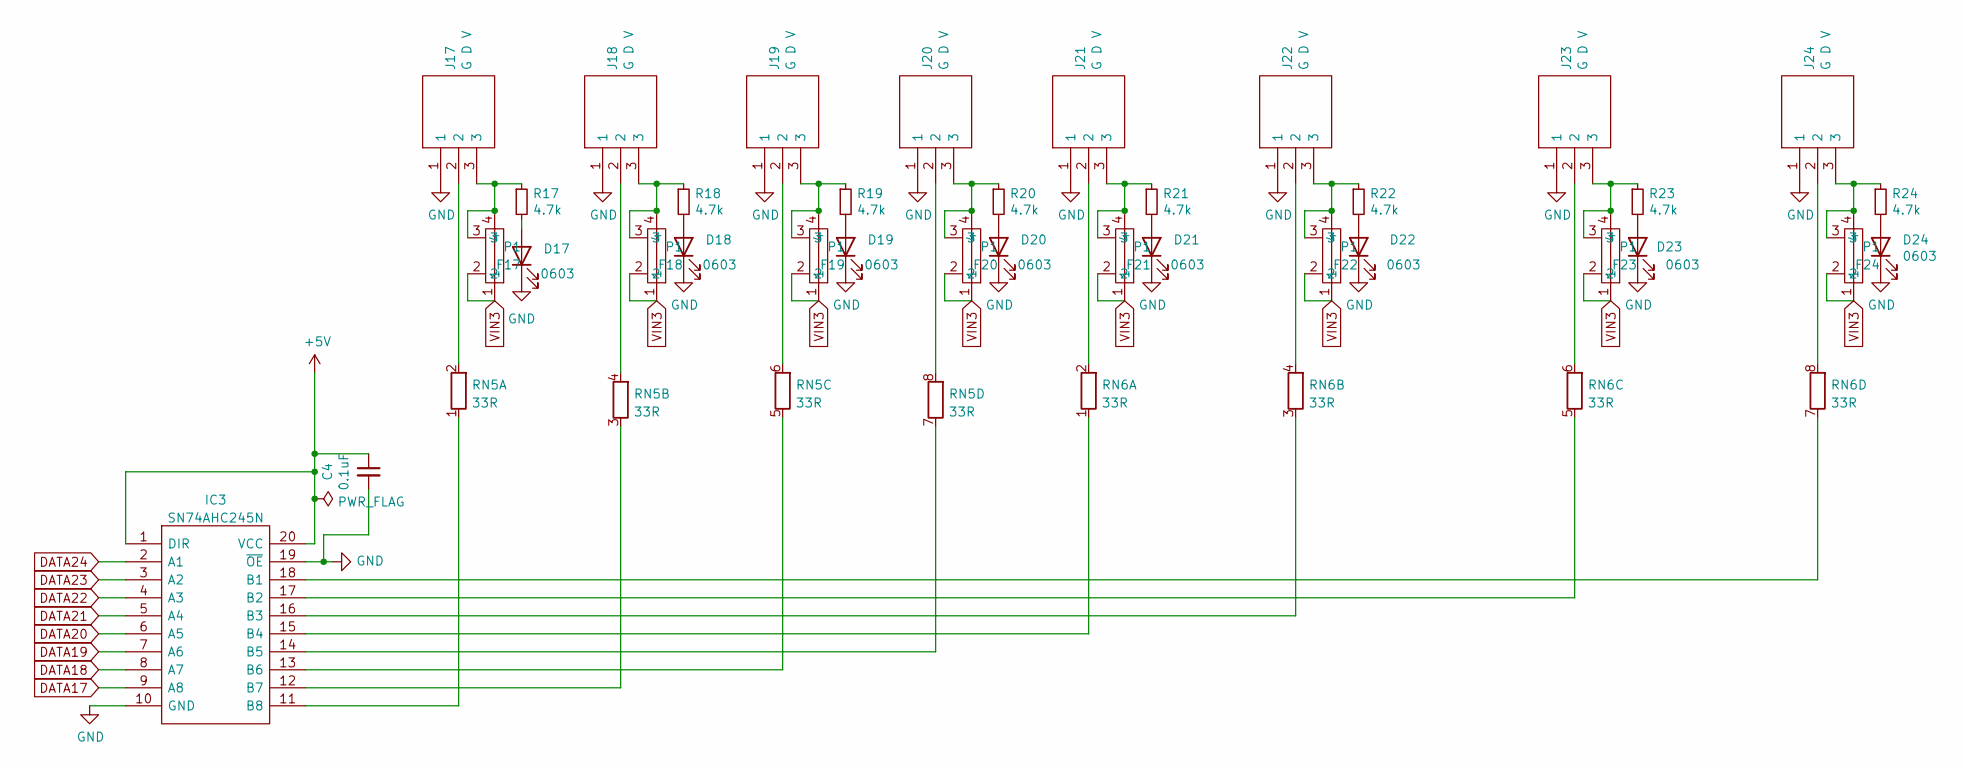
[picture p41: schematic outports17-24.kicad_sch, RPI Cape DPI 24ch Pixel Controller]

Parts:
C4: 0.1uF; C_Radial_D5.0mm_H11.0mm_P2.00mm
D17, D18, D19, D20, D21, D22, D23, D24: 0603; LED_0603_1608Metric
F17, F18, F19, F20, F21, F22, F23, F24: P1; Medium Auto Fuse Holder
IC3: SN74AHC245N; DIP794W53P254L2540H508Q20N; Mouser Part Number 595-SN74AHC245N
J17, J18, J19, J20, J21, J22, J23, J24: G D V; PhoenixContact_MCV_1,5_3-G-3.5_1x03_P3.50mm_Vertical; Mouser Part Number 571-284514-3
R17, R18, R19, R20, R21, R22, R23, R24: 4.7k; R_0805_2012Metric
RN5, RN6: 33R; R_Array_SIP8

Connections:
DATA17: IC3.9 (A8); also elsewhere on the board
DATA18: IC3.8 (A7); also elsewhere on the board
DATA19: IC3.7 (A6); also elsewhere on the board
DATA20: IC3.6 (A5); also elsewhere on the board
DATA21: IC3.5 (A4); also elsewhere on the board
DATA22: IC3.4 (A3); also elsewhere on the board
DATA23: IC3.3 (A2); also elsewhere on the board
DATA24: IC3.2 (A1); also elsewhere on the board
unnamed: D17.2 (A), R17.2
unnamed: D18.2 (A), R18.2
unnamed: D19.2 (A), R19.2
unnamed: D20.2 (A), R20.2
unnamed: D21.2 (A), R21.2
unnamed: D22.2 (A), R22.2
unnamed: D23.2 (A), R23.2
unnamed: D24.2 (A), R24.2
unnamed: F17.3, F17.4, J17.3, R17.1
unnamed: F18.3, F18.4, J18.3, R18.1
unnamed: F19.3, F19.4, J19.3, R19.1
unnamed: F20.3, F20.4, J20.3, R20.1
unnamed: F21.3, F21.4, J21.3, R21.1
unnamed: F22.3, F22.4, J22.3, R22.1
unnamed: F23.3, F23.4, J23.3, R23.1
unnamed: F24.3, F24.4, J24.3, R24.1
unnamed: IC3.11 (B8), RN5.1 (R1.1)
unnamed: IC3.12 (B7), RN5.3 (R2.1)
unnamed: IC3.13 (B6), RN5.5 (R3.1)
unnamed: IC3.14 (B5), RN5.7 (R4.1)
unnamed: IC3.15 (B4), RN6.1 (R1.1)
unnamed: IC3.16 (B3), RN6.3 (R2.1)
unnamed: IC3.17 (B2), RN6.5 (R3.1)
unnamed: IC3.18 (B1), RN6.7 (R4.1)
unnamed: J17.2, RN5.2 (R1.2)
unnamed: J18.2, RN5.4 (R2.2)
unnamed: J19.2, RN5.6 (R3.2)
unnamed: J20.2, RN5.8 (R4.2)
unnamed: J21.2, RN6.2 (R1.2)
unnamed: J22.2, RN6.4 (R2.2)
unnamed: J23.2, RN6.6 (R3.2)
unnamed: J24.2, RN6.8 (R4.2)
VIN3: F17.1, F17.2, F18.1, F18.2, F19.1, F19.2, F20.1, F20.2, F21.1, F21.2, F22.1, F22.2, F23.1, F23.2, F24.1, F24.2; also elsewhere on the board

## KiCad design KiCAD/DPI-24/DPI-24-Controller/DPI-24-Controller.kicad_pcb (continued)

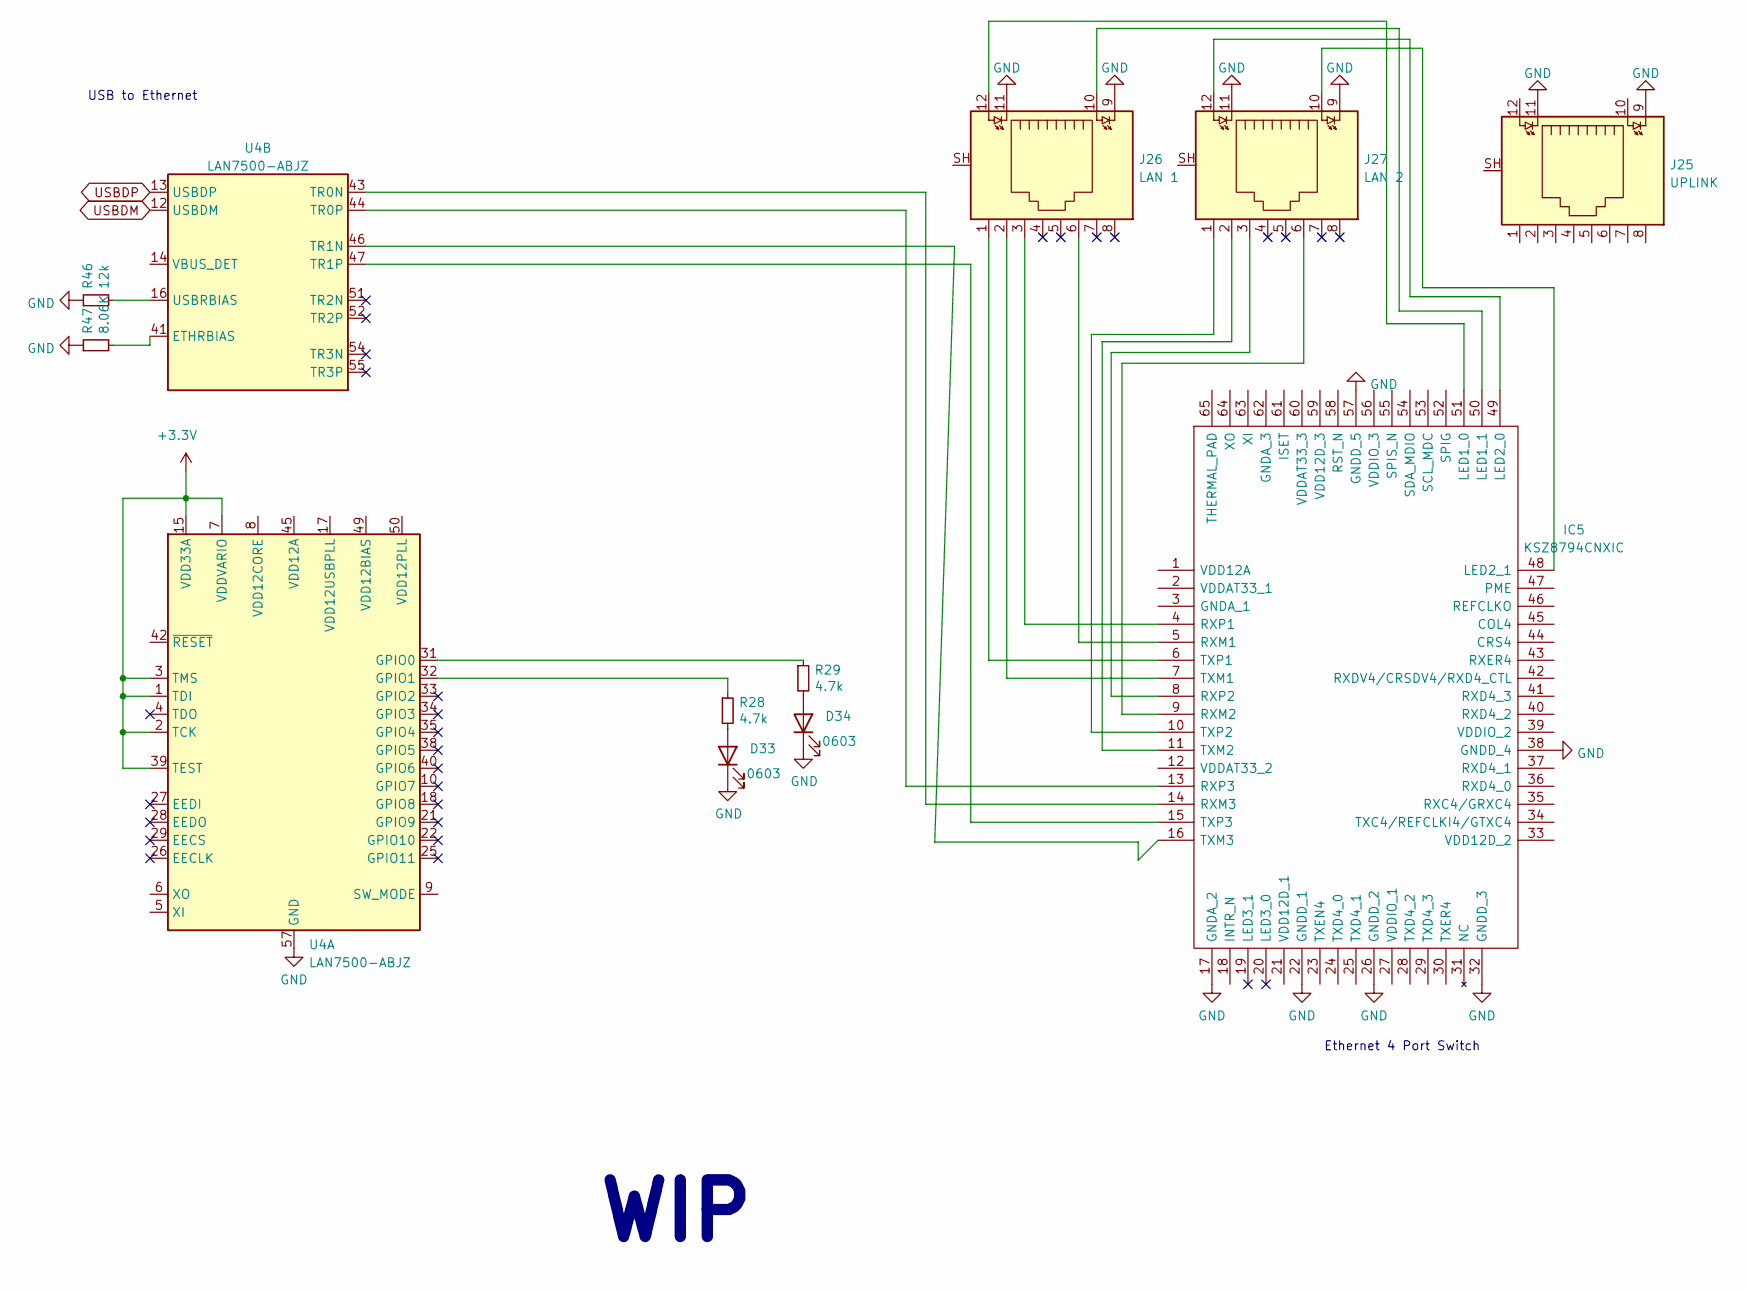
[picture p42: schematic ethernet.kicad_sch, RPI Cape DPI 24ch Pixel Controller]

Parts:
D33, D34: 0603; LED_0603_1608Metric
IC5: KSZ8794CNXIC; QFN40P800X800X90-65N; Mouser Part Number 998-KSZ8794CNXIC
J25: UPLINK; RJ45_BEL_SS74301-00x_Vertical
J26: LAN 1; RJ45_BEL_SS74301-00x_Vertical
J27: LAN 2; RJ45_BEL_SS74301-00x_Vertical
R28, R29: 4.7k; R_0805_2012Metric
R46: 12k; R_0805_2012Metric
R47: 8.06K; R_0805_2012Metric
U4: LAN7500-ABJZ; QFN-56-1EP_8x8mm_P0.5mm_EP5.9x5.9mm

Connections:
unnamed: D33.2 (A), R28.2
unnamed: D34.2 (A), R29.2
unnamed: IC5.4 (RXP1), J26.3
unnamed: IC5.5 (RXM1), J26.6
unnamed: IC5.6 (TXP1), J26.1
unnamed: IC5.7 (TXM1), J26.2
unnamed: IC5.8 (RXP2), J27.3
unnamed: IC5.9 (RXM2), J27.6
unnamed: IC5.10 (TXP2), J27.1
unnamed: IC5.11 (TXM2), J27.2
unnamed: IC5.13 (RXP3), U4.44 (TR0P)
unnamed: IC5.14 (RXM3), U4.43 (TR0N)
unnamed: IC5.15 (TXP3), U4.47 (TR1P)
unnamed: IC5.16 (TXM3), U4.46 (TR1N)
unnamed: IC5.48 (LED2_1), J27.10
unnamed: IC5.49 (LED2_0), J27.12
unnamed: IC5.50 (LED1_1), J26.10
unnamed: IC5.51 (LED1_0), J26.12
unnamed: R28.1, U4.32 (GPIO1)
unnamed: R29.1, U4.31 (GPIO0)
unnamed: R46.2, U4.16 (USBRBIAS)
unnamed: R47.2, U4.41 (ETHRBIAS)
unnamed: U4.8 (VDD12CORE), U4.11 (VDD12CORE), U4.20 (VDD12CORE), U4.23 (VDD12CORE), U4.30 (VDD12CORE), U4.36 (VDD12CORE)
unnamed: U4.45 (VDD12A), U4.48 (VDD12A), U4.53 (VDD12A), U4.56 (VDD12A)
USBDM: U4.12 (USBDM)
USBDP: U4.13 (USBDP)

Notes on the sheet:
USB to Ethernet
Ethernet 4 Port Switch
WIP

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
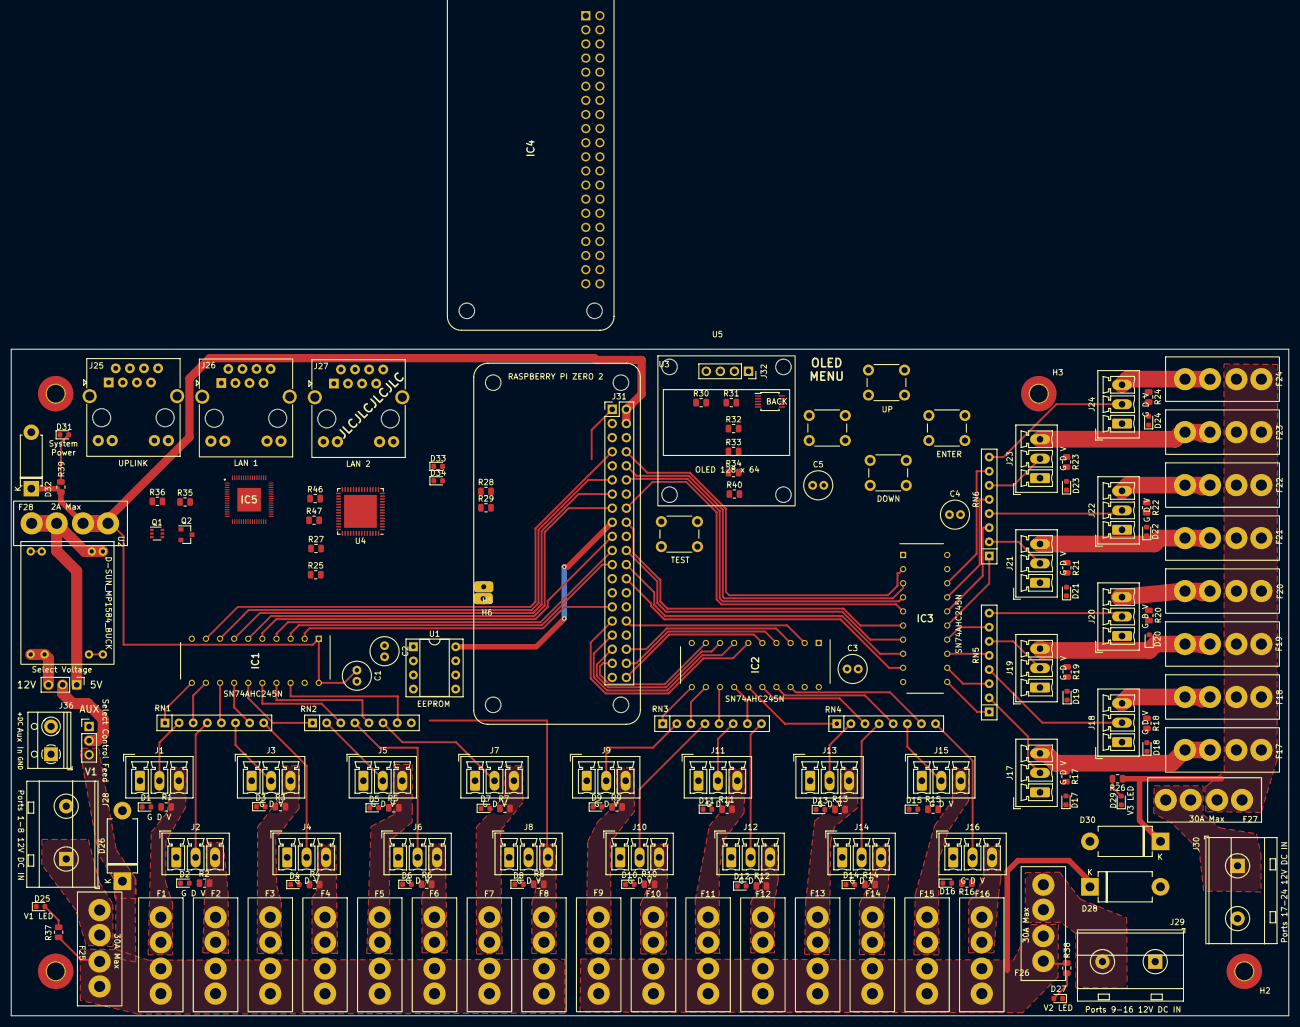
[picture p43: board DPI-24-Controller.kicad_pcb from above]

Board: 2 copper layers, 230.0 x 120.0 mm, 173 parts (0 on the bottom side), 176 nets.

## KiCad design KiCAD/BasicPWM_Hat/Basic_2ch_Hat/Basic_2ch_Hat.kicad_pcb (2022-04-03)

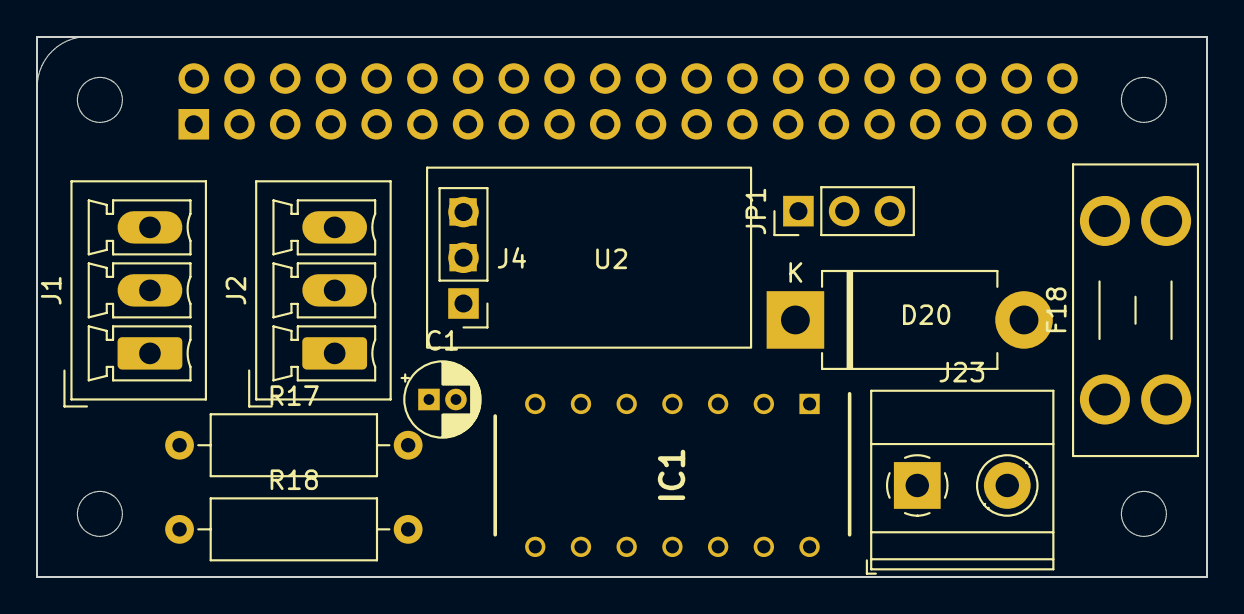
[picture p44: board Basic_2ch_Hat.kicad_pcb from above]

Board: 2 copper layers, 65.0 x 30.0 mm, 17 parts (1 on the bottom side), 13 nets, no tracks yet.

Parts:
C1: 0.1uF; CP_Radial_D4.0mm_P1.50mm
D20: SB5100; D_DO-201AD_P12.70mm_Horizontal
F18: 30A Max; Fuseholder_Blade_Mini_Keystone_3568
H1, H2, H3, H4: MountingHole; MountingHole_2.5mm
IC1: SN74HC126N; DIP794W53P254L1930H508Q14N
J1, J2: G D V; PhoenixContact_MCV_1,5_3-G-3.5_1x03_P3.50mm_Vertical
J3: Conn_02x20_Odd_Even_MountingPin; PinSocket_2x20_P2.54mm_Vertical
J4: Conn_01x03; PinHeader_1x03_P2.54mm_Vertical
J23: DC In; TerminalBlock_Phoenix_MKDS-1,5-2_1x02_P5.00mm_Horizontal
JP1: 5V / 12V; PinHeader_1x03_P2.54mm_Vertical
R17, R18: 33; R_Axial_DIN0309_L9.0mm_D3.2mm_P12.70mm_Horizontal
U2: DC DC_BUCK Module; DC DC BUCK MODULE

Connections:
+3V3: J3.1, J3.17
+5V: C1.1, IC1.14 (VCC)
DATA1: IC1.2 (1A), J3.32
DATA2: IC1.5 (2A), J3.33
GND: C1.2, D20.2 (A), IC1.1 (1OE), IC1.4 (2OE), IC1.7 (GND), IC1.10 (3OE), IC1.13 (4OE), J1.1, J2.1, J3.6, J3.9, J3.14, J3.20, J3.25, J3.30, J3.34, J3.39, J4.2, J23.1
unnamed: IC1.3 (1Y), R18.2
unnamed: IC1.6 (2Y), R17.2
unnamed: J1.2, R18.1
unnamed: J2.2, R17.1
V1: F18.1, J23.2
V5: J3.2, J3.4, J4.3, JP1.1 (A)
V12: J4.1, JP1.3 (B)
VIN1: D20.1 (K), F18.2, J1.3, J2.3, JP1.2 (C)

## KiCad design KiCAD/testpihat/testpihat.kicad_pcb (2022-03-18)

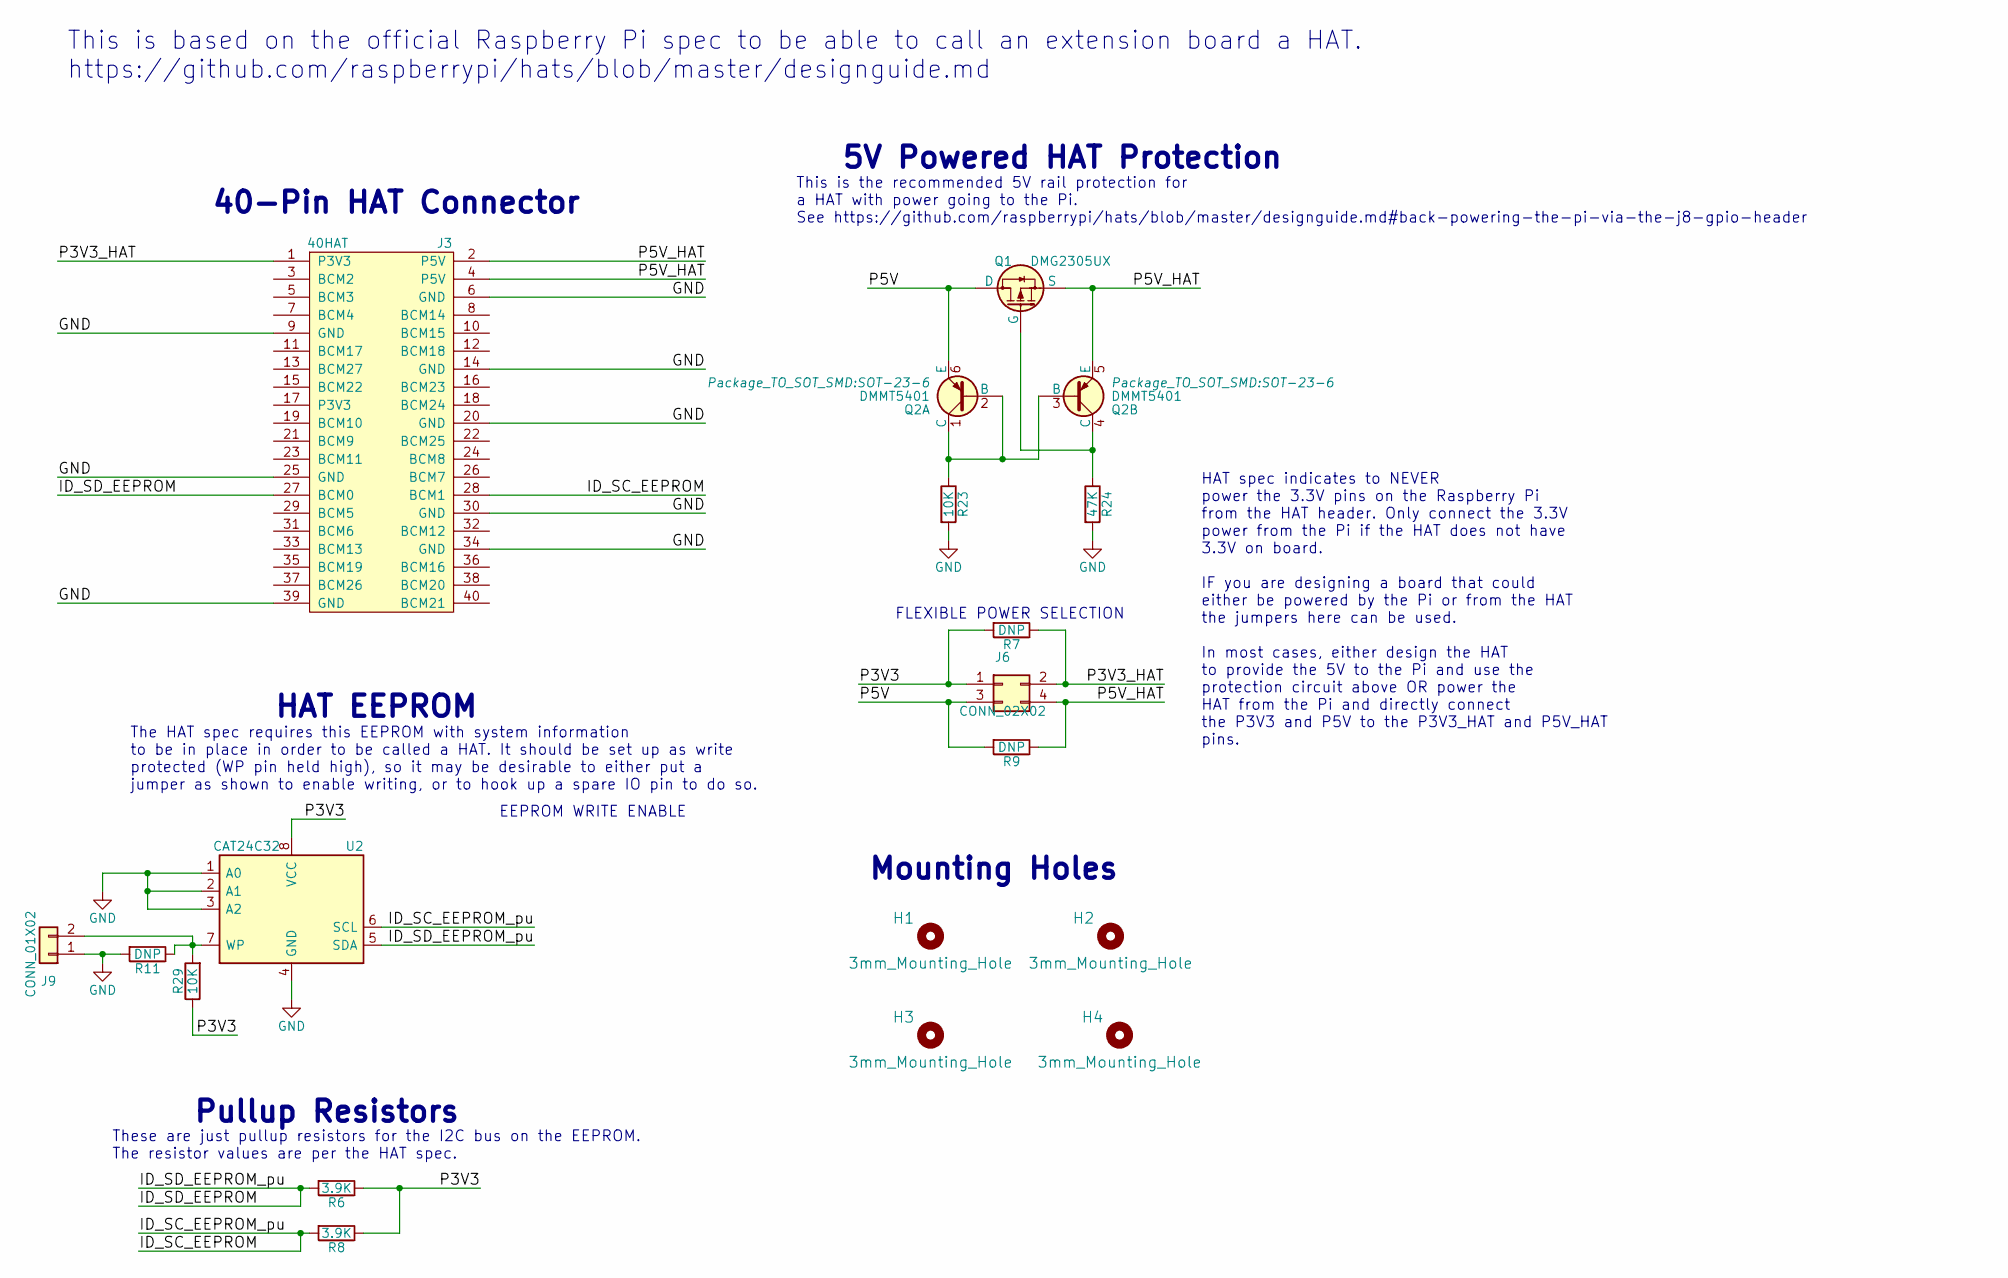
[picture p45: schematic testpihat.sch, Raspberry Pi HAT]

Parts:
H1, H2, H3, H4: 3mm_Mounting_Hole; NPTH_3mm_ID
J3: 40HAT; PinSocket_2x20_P2.54mm_Vertical
J6: CONN_02X02; PinHeader_2x02_P2.54mm_Vertical
J9: CONN_01X02; PinHeader_1x02_P2.54mm_Vertical
Q1: DMG2305UX; SOT-23
Q2: DMMT5401; SOT-23-6
R6, R8: 3.9K; R_0603_1608Metric_Pad0.84x1.00mm_HandSolder
R7, R9, R11: DNP; R_0603_1608Metric_Pad0.84x1.00mm_HandSolder
R23, R29: 10K; R_0603_1608Metric_Pad0.84x1.00mm_HandSolder
R24: 47K; R_0603_1608Metric_Pad0.84x1.00mm_HandSolder
U2: CAT24C32; SOIC-8_3.9x4.9mm_P1.27mm

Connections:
/ID_SC_EEPROM: J3.28 (BCM1), R8.2, U2.6 (SCL)
/ID_SD_EEPROM: J3.27 (BCM0), R6.2, U2.5 (SDA)
/P3V3: J6.1, R6.1, R7.2, R8.1, R29.1, U2.8 (VCC)
/P3V3_HAT: J3.1 (P3V3), J6.2, R7.1
/P5V: J6.3, Q1.3 (D), Q2.6 (E), R9.2
/P5V_HAT: J3.2 (P5V), J3.4 (P5V), J6.4, Q1.2 (S), Q2.5 (E), R9.1
GND: J3.6 (GND), J3.9 (GND), J3.14 (GND), J3.20 (GND), J3.25 (GND), J3.30 (GND), J3.34 (GND), J3.39 (GND), J9.1, R11.2, R23.2, R24.2, U2.1 (A0), U2.2 (A1), U2.3 (A2), U2.4 (GND)
unnamed: J9.2, R11.1, R29.2, U2.7 (WP)
unnamed: Q1.1 (G), Q2.4 (C), R24.1
unnamed: Q2.1 (C), Q2.2 (B), Q2.3 (B), R23.1

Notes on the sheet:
FLEXIBLE POWER SELECTION
5V Powered HAT Protection
This is the recommended 5V rail protection for a HAT with power going to the Pi. See https://github.com/raspberrypi/hats/blob/master/designguide.md#back-powering-the-pi-via-the-j8-gpio-header
EEPROM WRITE ENABLE
Pullup Resistors
HAT EEPROM
Mounting Holes
40-Pin HAT Connector
HAT spec indicates to NEVER power the 3.3V pins on the Raspberry Pi from the HAT header. Only connect the 3.3V power from the Pi if the HAT does not have 3.3V on board. IF you are designing a board that could either be powered by the Pi or from the HAT the jumpers here can be used. In most cases, e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
The HAT spec requires this EEPROM with system information to be in place in order to be called a HAT. It should be set up as write protected (WP pin held high), so it may be desirable to either put a jumper as shown to enable writing, or to hook up a spare IO pin to do so.
These are just pullup resistors for the I2C bus on the EEPROM. The resistor values are per the HAT spec.
This is based on the official Raspberry Pi spec to be able to call an extension board a HAT. https://github.com/raspberrypi/hats/blob/master/designguide.md

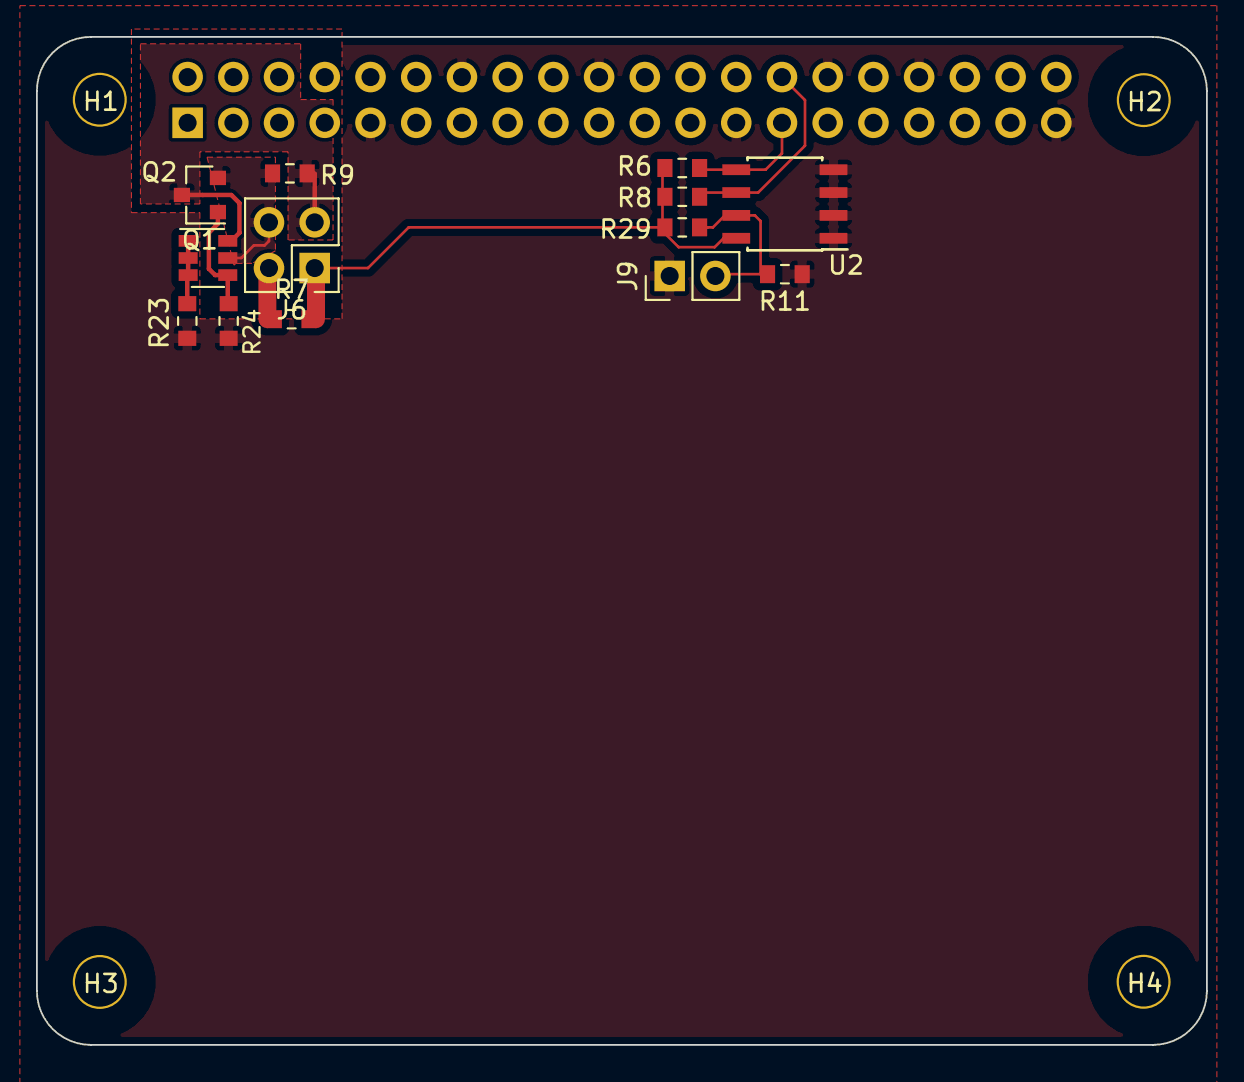
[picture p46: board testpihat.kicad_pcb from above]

Board: 4 copper layers, 65.0 x 56.0 mm, 18 parts (1 on the bottom side), 10 nets.

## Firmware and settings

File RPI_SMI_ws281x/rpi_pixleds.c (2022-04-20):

// Raspberry Pi WS2812 LED driver using SMI
// For detailed description, see https://iosoft.blog
//
// Copyright (c) 2020 Jeremy P Bentham
//
// Licensed under the Apache License, Version 2.0 (the "License");
// you may not use this file except in compliance with the License.
// You may obtain a copy of the License at
//
//     http://www.apache.org/licenses/LICENSE-2.0
//
// Unless required by applicable law or agreed to in writing, software
// distributed under the License is distributed on an "AS IS" BASIS,
// WITHOUT WARRANTIES OR CONDITIONS OF ANY KIND, either express or implied.
// See the License for the specific language governing permissions and
// limitations under the License.
//
// v0.01 JPB 16/7/20 Adapted from rpi_smi_adc_test v0.06
// v0.02 JPB 15/9/20 Addded RGB to GRB conversion
// v0.03 JPB 15/9/20 Added red-green flashing
// v0.04 JPB 16/9/20 Added test mode
// v0.05 JPB 19/9/20 Changed test mode colours
// v0.06 JPB 20/9/20 Outlined command-line data input
// v0.07 JPB 25/9/20 Command-line data input if not in test mode
// v0.08 JPB 26/9/20 Changed from 4 to 3 pulses per LED bit
//                   Added 4-bit zero preamble
//                   Added raw Tx data test
// v0.09 JPB 27/9/20 Added 16-channel option
// v0.10 JPB 28/9/20 Corrected Pi Zero caching problem
// v0.11 JPB 29/9/20 Added enable_dma before transfer (in case still active)
//                   Corrected DMA nsamp value (was byte count)
// v0.12 JPB 26/5/21 Corrected transfer length for 16-bit mode

#include <stdio.h>
#include <signal.h>
#include <stdint.h>
#include <stdlib.h>
#include <string.h>
#include <unistd.h>
#include <ctype.h>
#include "rpi_dma_utils.h"
#include "rpi_smi_defs.h"

#if PHYS_REG_BASE==PI_4_REG_BASE        // Timings for RPi v4 (1.5 GHz)
#define SMI_TIMING       10, 15, 30, 15    // 400 ns cycle time
#else                                   // Timings for RPi v0-3 (1 GHz)
#define SMI_TIMING       10, 10, 20, 10   // 400 ns cycle time
#endif

#define TX_TEST         0   // If non-zero, use dummy Tx data
#define LED_D0_PIN      8   // GPIO pin for D0 output
#define LED_NCHANS      8   // Number of LED channels (8 or 16)
#define LED_NBITS       24  // Number of data bits per LED
#define LED_PREBITS     4   // Number of zero bits before LED data
#define LED_POSTBITS    4   // Number of zero bits after LED data
#define BIT_NPULSES     3   // Number of O/P pulses per LED bit
#define CHAN_MAXLEDS    50  // Maximum number of LEDs per channel
#define CHASE_MSEC      100 // Delay time for chaser light test
#define REQUEST_THRESH  2   // DMA request threshold
#define DMA_CHAN        10  // DMA channel to use

// Length of data for 1 row (1 LED on each channel)
#define LED_DLEN        (LED_NBITS * BIT_NPULSES)

// Transmit data type, 8 or 16 bits
#if LED_NCHANS > 8
#define TXDATA_T        uint16_t
#else
#define TXDATA_T        uint8_t
#endif

// Structures for mapped I/O devices, and non-volatile memory
extern MEM_MAP gpio_regs, dma_regs;
MEM_MAP vc_mem, clk_regs, smi_regs;

// Pointers to SMI registers
volatile SMI_CS_REG  *smi_cs;
volatile SMI_L_REG   *smi_l;
volatile SMI_A_REG   *smi_a;
volatile SMI_D_REG   *smi_d;
volatile SMI_DMC_REG *smi_dmc;
volatile SMI_DSR_REG *smi_dsr;
volatile SMI_DSW_REG *smi_dsw;
volatile SMI_DCS_REG *smi_dcs;
volatile SMI_DCA_REG *smi_dca;
volatile SMI_DCD_REG *smi_dcd;

// Ofset into Tx data buffer, given LED number in chan
#define LED_TX_OSET(n)      (LED_PREBITS + (LED_DLEN * (n)))

// Size of data buffers & NV memory, given number of LEDs per chan
#define TX_BUFF_LEN(n)      (LED_TX_OSET(n) + LED_POSTBITS)
#define TX_BUFF_SIZE(n)     (TX_BUFF_LEN(n) * sizeof(TXDATA_T))
#define VC_MEM_SIZE         (PAGE_SIZE + TX_BUFF_SIZE(CHAN_MAXLEDS))

// RGB values for test mode (1 value for each of 16 channels)
int on_rgbs[16] = {0xff0000, 0x00ff00, 0x0000ff, 0xffffff,
                  0xff4040, 0x40ff40, 0x4040ff, 0x404040,
                  0xff0000, 0x00ff00, 0x0000ff, 0xffffff,
                  0xff4040, 0x40ff40, 0x4040ff, 0x404040};
int off_rgbs[16];

#if TX_TEST
// Data for simple transmission test
TXDATA_T tx_test_data[] = {1, 2, 3, 4, 5, 6, 7, 0};
#endif

TXDATA_T *txdata;                       // Pointer to uncached Tx data buffer
TXDATA_T tx_buffer[TX_BUFF_LEN(CHAN_MAXLEDS)];  // Tx buffer for assembling data
int testmode, chan_ledcount=1;          // Command-line parameters
int rgb_data[CHAN_MAXLEDS][LED_NCHANS]; // RGB data
int chan_num;                           // Current channel for data I/P

void rgb_txdata(int *rgbs, TXDATA_T *txd);
int str_rgb(char *s, int rgbs[][LED_NCHANS], int chan);
void swap_bytes(void *data, int len);
int hexdig(char c);
void map_devices(void);
void fail(char *s);
void terminate(int sig);
void init_smi(int width, int ns, int setup, int hold, int strobe);
void setup_smi_dma(MEM_MAP *mp, int nsamp);
void start_smi(MEM_MAP *mp);

int main(int argc, char *argv[])
{
    int args=0, n, oset=0;

    while (argc > ++args)               // Process command-line args
    {
        if (argv[args][0] == '-')
        {
            switch (toupper(argv[args][1]))
            {
            case 'N':                   // -N: number of LEDs per channel
                if (args >= argc-1)
                    fprintf(stderr, "Error: no numeric value\n");
                else
                    chan_ledcount = atoi(argv[++args]);
                break;
            case 'T':                   // -T: test mode
                testmode = 1;
                break;
            default:                    // Otherwise error
                printf("Unrecognised option '%c'\n", argv[args][1]);
                printf("Options:\n"
                       "  -n num    number of LEDs per channel\n"\
                       "  -t        Test mode (flash LEDs)\n"\
                      );
                return(1);
            }
        }
        else if (chan_num<LED_NCHANS && hexdig(argv[args][0])>=0 &&
                 (n=str_rgb(argv[args], rgb_data, chan_num))>0)
        {
            chan_ledcount = n > chan_ledcount ? n : chan_ledcount;
            chan_num++;
        }
    }
    signal(SIGINT, terminate);
    map_devices();
    init_smi(LED_NCHANS>8 ? SMI_16_BITS : SMI_8_BITS, SMI_TIMING);
    map_uncached_mem(&vc_mem, VC_MEM_SIZE);
#if TX_TEST
    oset = oset;
    setup_smi_dma(&vc_mem, sizeof(tx_test_data)/sizeof(TXDATA_T));
#if LED_NCHANS <= 8
    swap_bytes(tx_test_data, sizeof(tx_test_data));
#endif
    memcpy(txdata, tx_test_data, sizeof(tx_test_data));
    start_smi(&vc_mem);
    usleep(10);
    while (dma_active(DMA_CHAN))
        usleep(10);
#else
    setup_smi_dma(&vc_mem, TX_BUFF_LEN(chan_ledcount));
    printf("%s %u LED%s per channel, %u channels\n", testmode ? "Testing" : "Setting",
           chan_ledcount, chan_ledcount==1 ? "" : "s", LED_NCHANS);
    if (testmode)
    {
        while (1)
        {
            if (chan_ledcount < 2)
                rgb_txdata(oset&1 ? off_rgbs : on_rgbs, tx_buffer);
            else
            {
                for (n=0; n<chan_ledcount; n++)
                {
                    rgb_txdata(n==oset%chan_ledcount ? on_rgbs : off_rgbs,
                               &tx_buffer[LED_TX_OSET(n)]);
                }
            }
            oset++;
#if LED_NCHANS <= 8
            swap_bytes(tx_buffer, TX_BUFF_SIZE(chan_ledcount));
#endif
            memcpy(txdata, tx_buffer, TX_BUFF_SIZE(chan_ledcount));
            start_smi(&vc_mem);
            usleep(CHASE_MSEC * 1000);
        }
    }
    else
    {
        for (n=0; n<chan_ledcount; n++)
            rgb_txdata(rgb_data[n], &tx_buffer[LED_TX_OSET(n)]);
#if LED_NCHANS <= 8
        swap_bytes(tx_buffer, TX_BUFF_SIZE(chan_ledcount));
#endif
        memcpy(txdata, tx_buffer, TX_BUFF_SIZE(chan_ledcount));
        enable_dma(DMA_CHAN);
        start_smi(&vc_mem);
        usleep(10);
        while (dma_active(DMA_CHAN))
            usleep(10);
    }
#endif
    terminate(0);
    return(0);
}

// Convert RGB text string into integer data, for given channel
// Return number of data points for this channel
int str_rgb(char *s, int rgbs[][LED_NCHANS], int chan)
{
    int i=0;
    char *p;

    while (chan<LED_NCHANS && i<CHAN_MAXLEDS && hexdig(*s)>=0)
    {
        rgbs[i++][chan] = strtoul(s, &p, 16);
        s = *p ? p+1 : p;
    }
    return(i);
}
// Set Tx data for 8 or 16 chans, 1 LED per chan, given 1 RGB val per chan
// Logic 1 is 0.8us high, 0.4 us low, logic 0 is 0.4us high, 0.8us low
void rgb_txdata(int *rgbs, TXDATA_T *txd)
{
    int i, n, msk;

    // For each bit of the 24-bit RGB values..
    for (n=0; n<LED_NBITS; n++)
    {
        // Mask to convert RGB to GRB, M.S bit first
        msk = n==0 ? 0x8000 : n==8 ? 0x800000 : n==16 ? 0x80 : msk>>1;
        // 1st byte or word is a high pulse on all lines
        txd[0] = (TXDATA_T)0xffff;
        // 2nd has high or low bits from data
        // 3rd is a low pulse
        txd[1] = txd[2] = 0;
        for (i=0; i<LED_NCHANS; i++)
        {
            if (rgbs[i] & msk)
                txd[1] |= (1 << i);
        }
        txd += BIT_NPULSES;
    }
}

// Swap adjacent bytes in transmit data
void swap_bytes(void *data, int len)
{
    uint16_t *wp = (uint16_t *)data;

    len = (len + 1) / 2;
    while (len-- > 0)
    {
        *wp = __builtin_bswap16(*wp);
        wp++;
    }
}

// Return hex digit value, -ve if not hex
int hexdig(char c)
{
    c = toupper(c);
    return((c>='0' && c<='9') ? c-'0' : (c>='A' && c<='F') ? c-'A'+10 : -1);
}

// Map GPIO, DMA and SMI registers into virtual mem (user space)
// If any of these fail, program will be terminated
void map_devices(void)
{
    map_periph(&gpio_regs, (void *)GPIO_BASE, PAGE_SIZE);
    map_periph(&dma_regs, (void *)DMA_BASE, PAGE_SIZE);
    map_periph(&clk_regs, (void *)CLK_BASE, PAGE_SIZE);
    map_periph(&smi_regs, (void *)SMI_BASE, PAGE_SIZE);
}

// Catastrophic failure in initial setup
void fail(char *s)
{
    printf(s);
    terminate(0);
}

// Free memory segments and exit
void terminate(int sig)
{
    int i;

    printf("Closing\n");
    if (gpio_regs.virt)
    {
        for (i=0; i<LED_NCHANS; i++)
            gpio_mode(LED_D0_PIN+i, GPIO_IN);
    }
    if (smi_regs.virt)
        *REG32(smi_regs, SMI_CS) = 0;
    stop_dma(DMA_CHAN);
    unmap_periph_mem(&vc_mem);
    unmap_periph_mem(&smi_regs);
    unmap_periph_mem(&dma_regs);
    unmap_periph_mem(&gpio_regs);
    exit(0);
}

// Initialise SMI, given data width, time step, and setup/hold/strobe counts
// Step value is in nanoseconds: even numbers, 2 to 30
void init_smi(int width, int ns, int setup, int strobe, int hold)
{
    int i, divi = ns / 2;

    smi_cs  = (SMI_CS_REG *) REG32(smi_regs, SMI_CS);
    smi_l   = (SMI_L_REG *)  REG32(smi_regs, SMI_L);
    smi_a   = (SMI_A_REG *)  REG32(smi_regs, SMI_A);
    smi_d   = (SMI_D_REG *)  REG32(smi_regs, SMI_D);
    smi_dmc = (SMI_DMC_REG *)REG32(smi_regs, SMI_DMC);
    smi_dsr = (SMI_DSR_REG *)REG32(smi_regs, SMI_DSR0);
    smi_dsw = (SMI_DSW_REG *)REG32(smi_regs, SMI_DSW0);
    smi_dcs = (SMI_DCS_REG *)REG32(smi_regs, SMI_DCS);
    smi_dca = (SMI_DCA_REG *)REG32(smi_regs, SMI_DCA);
    smi_dcd = (SMI_DCD_REG *)REG32(smi_regs, SMI_DCD);
    smi_cs->value = smi_l->value = smi_a->value = 0;
    smi_dsr->value = smi_dsw->value = smi_dcs->value = smi_dca->value = 0;
    if (*REG32(clk_regs, CLK_SMI_DIV) != divi << 12)
    {
        *REG32(clk_regs, CLK_SMI_CTL) = CLK_PASSWD | (1 << 5);
        usleep(10);
        while (*REG32(clk_regs, CLK_SMI_CTL) & (1 << 7)) ;
        usleep(10);
        *REG32(clk_regs, CLK_SMI_DIV) = CLK_PASSWD | (divi << 12);
        usleep(10);
        *REG32(clk_regs, CLK_SMI_CTL) = CLK_PASSWD | 6 | (1 << 4);
        usleep(10);
        while ((*REG32(clk_regs, CLK_SMI_CTL) & (1 << 7)) == 0) ;
        usleep(100);
    }
    if (smi_cs->seterr)
        smi_cs->seterr = 1;
    smi_dsr->rsetup = smi_dsw->wsetup = setup;
    smi_dsr->rstrobe = smi_dsw->wstrobe = strobe;
    smi_dsr->rhold = smi_dsw->whold = hold;
    smi_dmc->panicr = smi_dmc->panicw = 8;
    smi_dmc->reqr = smi_dmc->reqw = REQUEST_THRESH;
    smi_dsr->rwidth = smi_dsw->wwidth = width;
    for (i=0; i<LED_NCHANS; i++)
        gpio_mode(LED_D0_PIN+i, GPIO_ALT1);
}

// Set up SMI transfers using DMA
void setup_smi_dma(MEM_MAP *mp, int nsamp)
{
    DMA_CB *cbs=mp->virt;

    txdata = (TXDATA_T *)(cbs+1);
    smi_dmc->dmaen = 1;
    smi_cs->enable = 1;
    smi_cs->clear = 1;
    smi_cs->pxldat = 1;
    smi_l->len = nsamp * sizeof(TXDATA_T);
    smi_cs->write = 1;
    enable_dma(DMA_CHAN);
    cbs[0].ti = DMA_DEST_DREQ | (DMA_SMI_DREQ << 16) | DMA_CB_SRCE_INC | DMA_WAIT_RESP;
    cbs[0].tfr_len = nsamp * sizeof(TXDATA_T);
    cbs[0].srce_ad = MEM_BUS_ADDR(mp, txdata);
    cbs[0].dest_ad = REG_BUS_ADDR(smi_regs, SMI_D);
}

// Start SMI DMA transfers
void start_smi(MEM_MAP *mp)
{
    DMA_CB *cbs=mp->virt;

    start_dma(mp, DMA_CHAN, &cbs[0], 0);
    smi_cs->start = 1;
}

// EOF

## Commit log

2022-03-18 inital commit of KiCAD WIP
2022-03-18 updates to power components
    [import.sch, out-ports1-8.sch, outports9-16.sch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]
2022-03-20 logo and kicad updates
    [out-ports1-8.sch, outports9-16.sch, owl_cape.kicad_pcb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]
2022-03-24 updates and eeprom settings
    [owl_cape.sch]
2022-03-27 added buck and pi
    [controls.kicad_sch, out-ports1-8.kicad_sch, outports9-16.kicad_sch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]
2022-03-28 started routing cu
    [RPI_Pad_locations.xlsx, controls.kicad_sch, out-ports1-8.kicad_sch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]
2022-04-03 swap chips to better speed / layout
    [Basic_2ch_Hat-B_Cu.gbl, Basic_2ch_Hat-B_Mask.gbs, Basic_2ch_Hat-B_Paste.gbp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]
2022-04-05 major update to layout
    [controls.kicad_sch, ethernet.kicad_sch, out-ports1-8.kicad_sch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]
2022-04-17 formatting fix
    [controls.kicad_sch, owl_cape.kicad_sch, serial_diff.kicad_sch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]
2022-04-20 updates based on testing
    [owl_cape.kicad_sch, serial_diff.kicad_sch, standard-hat-components.kicad_sch]
2022-04-24 addition of DPI-24 model
    [DPI-24-Controller.csv, DPI-24-Controller.kicad_pcb, DPI-24-Controller.kicad_sch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]
2022-04-24 dpi-24 updates
    [30A blade fuse.step.STEP, 5A blade fuse.step, 70255292.stp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]
2022-04-25 layout updates
    [1734577-3.stp, DPI-24-Controller.kicad_pcb, DPI-24-Controller.kicad_sch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]
2022-04-25 pcb layout changes
    [DPI-24-Controller.kicad_pcb, mill-max-0908-1-15-20-75-14-11-0.STEP]
2022-04-25 further layout updates
    [DPI-24-Controller.kicad_pcb, DPI-24-Controller.kicad_sch, KF950_01_2P_P9.5.stp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]
2022-04-25 more layout
    [DPI-24-Controller.kicad_pcb, DPI-24-Controller.kicad_sch, controls.kicad_sch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]
2022-04-28 more layout tweaking and a bit of copper!
    [2A blade fuse.STEP, 2P_P500MM_Terminal.STEP, 30A blade fuse.STEP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]
2022-04-29 more tweaks
    [DPI-24-Controller.kicad_pcb]
